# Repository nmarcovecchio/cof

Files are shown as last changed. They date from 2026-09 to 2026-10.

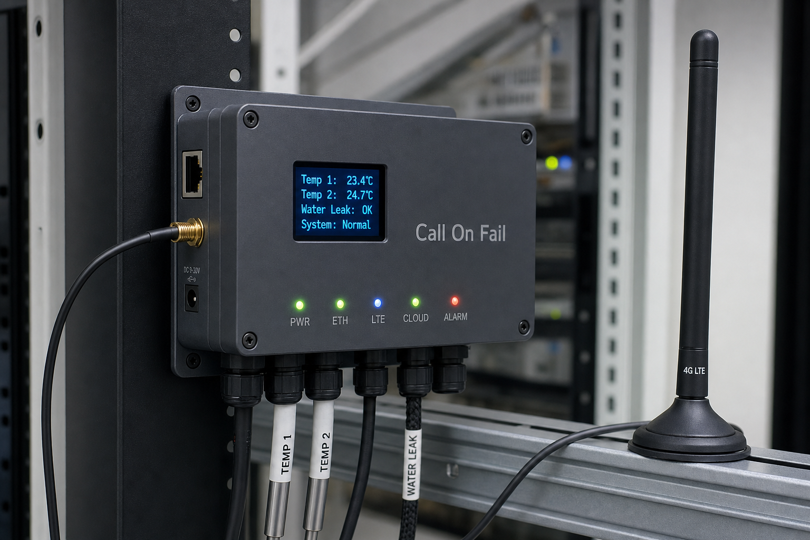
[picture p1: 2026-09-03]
web/assets/producto-nodo.png

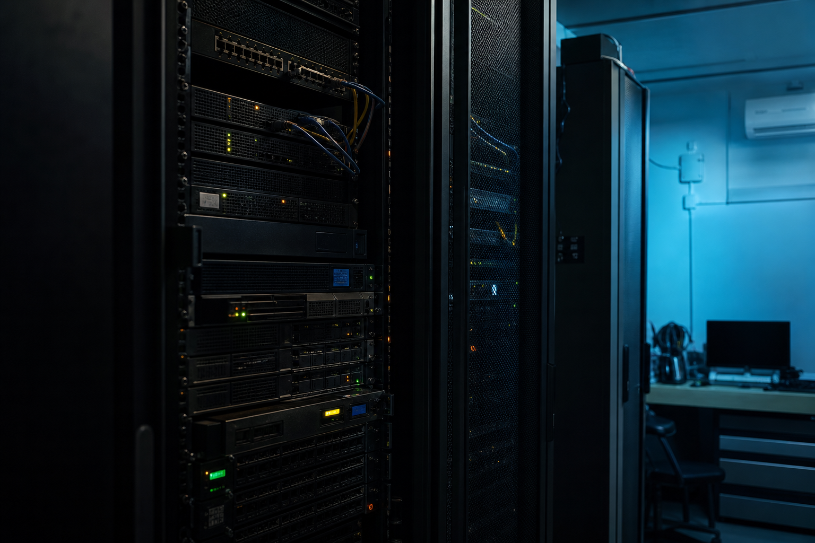
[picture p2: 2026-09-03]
web/assets/hero-sala.png

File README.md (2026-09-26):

# CallOnFail firmware

Primer firmware base para CallOnFail usando:

- WT32-ETH01 / WT32-S1 con Ethernet.
- WiFi opcional por credenciales cargadas desde Serial.
- OLED I2C 1.3" SH1106.
- SHT31 por I2C.
- DS18B20 por OneWire.
- PCF8574 por I2C para boton/DIP switch.
- Modem A7672 por UART TTL.
- OTA por Ethernet desde `ota/manifest.json`.
- Audio de prueba descargado por Ethernet y cargado al modem con `AT+CFTRANRX`.

## Backend MVP con Docker

El repo incluye una base deployable para VPS:

- Flask + Gunicorn.
- Jinja templates + Bootstrap.
- PostgreSQL.
- Redis.
- Mosquitto MQTT interno.
- Worker MQTT Python.
- Caddy como reverse proxy.
- Sitio público estático en `web/` (`www.callonfail.com.ar`).

La bitacora/configuracion persistente del VPS queda en:

```text
docs/ops/VPS_CONFIG.md
```

El contrato inicial para configuracion de dispositivos queda en:

```text
docs/DEVICE_CONFIG_V1.md
```

Llamada y SMS validados en lab (Claro / A7672 / TTS WAV) quedan en:

```text
docs/voice/VOICE_SMS.md
docs/voice/operators/claro-ar.md
```

La configuracion diferencia capacidades del modem, llamadas habilitadas por
cliente y estado real de audios. Un modem puede soportar audio, pero el cliente
puede tener `calling.enabled=false`.

### Deploy inicial en VPS

En el VPS, despues de instalar Docker:

```bash
sudo mkdir -p /opt/callonfail
sudo chown -R ubuntu:ubuntu /opt/callonfail
git clone https://github.com/nmarcovecchio/cof.git /opt/callonfail
cd /opt/callonfail
cp .env.example .env
nano .env
```

Si estas probando una rama antes de mergearla a `main`:

```bash
git clone -b NOMBRE_DE_RAMA https://github.com/nmarcovecchio/cof.git /opt/callonfail
```

Para una primera prueba sin dominio/TLS, dejar:

```text
APP_DOMAIN=:80
```

Cuando `app.callonfail.com.ar` (y `www`) apunten al VPS con DNS only en
Cloudflare, cambiar:

```text
APP_DOMAIN=app.callonfail.com.ar
ACME_EMAIL=tu-email
```

En produccion usá siempre el dominio, no la IP:

```text
https://www.callonfail.com.ar/
https://app.callonfail.com.ar/
```

Detalle de DNS/TLS/ACME: `docs/ops/VPS_CONFIG.md`.

Timezone de la UI:

```text
APP_TIMEZONE=America/Argentina/Buenos_Aires
```

Las fechas se guardan en UTC y se muestran en la UI con este timezone, hasta
segundos.

Credenciales admin iniciales:

```text
SECRET_KEY=generar-un-secreto-largo
ADMIN_USERNAME=admin
ADMIN_PASSWORD=poner-un-password-fuerte
SESSION_COOKIE_SECURE=false
```

`/health` queda publico para monitoreo. Dashboard, dispositivos, config y
comandos requieren login.

Los formularios usan token CSRF básico. Cuando el sitio esté con HTTPS, cambiar
`SESSION_COOKIE_SECURE=true`.

Levantar servicios:

```bash
docker compose up -d --build
```

Ver estado:

```bash
docker compose ps
docker compose logs -f web
docker compose logs -f mqtt-worker
```

Probar desde el VPS:

```bash
curl http://localhost/health
curl http://localhost/api/status
```

Probar desde navegador:

```text
http://IP_DEL_VPS/
```

Dashboard Bootstrap:

```text
http://IP_DEL_VPS/dashboard
http://IP_DEL_VPS/tenants
http://IP_DEL_VPS/devices
http://IP_DEL_VPS/devices/new
http://IP_DEL_VPS/devices/cof-test
http://IP_DEL_VPS/devices/cof-test/config
```

Flujo multi-cliente inicial:

1. Crear cliente en `/tenants/new` (email, grupo de Telegram, telefono).
2. Crear sitio en `/sites/new`.
3. Crear dispositivo en `/devices/new`.
4. Usar el mismo `Device ID` que usa el firmware en MQTT.
5. Entrar al dispositivo y publicar config o forzar OTA.
6. Configurar SMTP/bot una sola vez en el VPS: `docs/ops/NOTIFICATIONS.md`.

Los dispositivos reportan `hardware_profile`, capacidades y recursos
descubiertos. En `/devices/<device_id>` se muestran esos datos para poder mapear
sensores fisicos a sensores logicos.

Los datos de prueba se pueden borrar desde la web:

- `/devices`: archivar/restaurar dispositivos.
- `/tenants`: eliminar clientes completos o sitios individuales.

Archivar un dispositivo conserva su historial. Si el hardware sigue publicando
MQTT, el backend registra eventos `archived_device_message` y no guarda
telemetria normal ni lo reactiva automaticamente.

Para reutilizar un equipo con otro cliente:

1. Ir a `/devices?include_archived=1`.
2. Entrar a `Editar/reasignar`.
3. Elegir nuevo cliente/sitio.
4. Guardar y restaurar.

o, si ya configuraste DNS:

```text
https://app.callonfail.com.ar/
```

### Comandos Docker utiles

```bash
docker compose up -d
docker compose up -d --build
docker compose ps
docker compose logs -f
docker compose logs -f web
docker compose restart web
docker compose down
```

### MQTT MVP

Mosquitto escucha internamente en `1883` y Docker lo publica solo en
`127.0.0.1:1883`, para que no quede abierto a internet sin TLS.

Para probar desde el VPS:

```bash
docker compose exec mosquitto mosquitto_pub -h localhost -t devices/cof-test/telemetry -m '{"temperature":25.1}'
docker compose logs -f mqtt-worker
```

Antes de conectar equipos reales desde internet hay que agregar autenticacion y
TLS en `8883`.

### Prueba ESP32 -> VPS por MQTT

Para una prueba corta de laboratorio, se puede exponer MQTT sin TLS en `1883`.
No dejar esto asi para produccion.

En `.env` del VPS:

```text
MQTT_BIND_ADDRESS=0.0.0.0
```

Recrear servicios:

```bash
docker compose up -d --build
```

Abrir temporalmente el puerto en UFW:

```bash
sudo ufw allow 1883/tcp
```

Tambien abrir `1883/tcp` en el firewall de Lightsail/AWS.

En el ESP32, desde PlatformIO Monitor:

```text
mqtt mqtt.callonfail.com.ar 1883 cof-test
```

O usando la IP publica:

```text
mqtt IP_DEL_VPS 1883 cof-test
```

Publicar telemetria manual:

```text
pub
```

Ver logs en el VPS:

```bash
docker compose logs -f mqtt-worker
```

Luego refrescar:

```text
http://IP_DEL_VPS/dashboard
```

Para probar configuracion web -> ESP32 -> ACK:

```text
http://IP_DEL_VPS/devices/cof-test
```

Entrar a `Editar/publicar configuracion`, guardar el JSON y esperar que el
dispositivo reporte la misma version en `Config deseada/reportada`.

Para forzar chequeo OTA desde la web:

```text
http://IP_DEL_VPS/devices/cof-test
```

Click en `Probar SMS` o `Probar llamada` (firmware 0.2.28+) para mandar un SMS
o marcar un numero. El texto de la casilla es el SMS y el audio de la llamada
(Piper `es_AR-daniela` → AMR-NB 8 kHz). Detalle en `docs/voice/VOICE_SMS.md`. El backend
publica `test_sms` o `test_call` en `devices/<id>/command`. Si el ACK dice
`unsupported`, primero `OTA`. Sin VoLTE la llamada prepara CS (RF bounce)
antes del primer `ATD`.

Click en `Forzar chequeo OTA`. El backend publica:

```text
devices/cof-test/command
```

con:

```json
{"command":"ota_check"}
```

El ESP32 responde en:

```text
devices/cof-test/ack
```

El firmware consulta el manifest automaticamente para datos auxiliares, pero la
actualizacion de firmware se ejecuta solo por comando explicito:

- boton web `Forzar chequeo OTA`,
- comando Serial `o`,
- pulsacion larga del boton fisico.

Si se borra un dispositivo mientras el ESP32 sigue conectado, puede recrearse
primero por telemetria y aparecer sin hardware profile hasta que llegue un
`status`. El firmware publica status al conectar MQTT y tambien se puede pedir
desde `/devices/<device_id>` con `Solicitar estado`.

Por defecto el worker no auto-crea dispositivos desconocidos:

```text
MQTT_AUTO_PROVISION=false
```

Crear/provisionar dispositivos desde la web evita asignaciones accidentales a
clientes equivocados.

Cuando termine la prueba, cerrar `1883`:

```bash
sudo ufw delete allow 1883/tcp
```

## IDE recomendado

Usa **Visual Studio Code + PlatformIO**.

1. Instalar VS Code.
2. Instalar la extension "PlatformIO IDE".
3. Abrir la carpeta `firmware/` del repo en VS Code (PlatformIO toma `platformio.ini` de ahí).
4. Editar `firmware/include/cof_config.h`.
5. Conectar el programador USB-Serial.
6. En PlatformIO, ejecutar:
   - `Build`
   - `Upload`
   - `Monitor`

Alternativa por consola (desde `firmware/`):

```bash
cd firmware
pio run
pio run -t upload
pio device monitor -b 115200
```

## Comandos por Serial

Abrir PlatformIO Monitor a `115200`. El firmware acepta comandos para probar
hardware sin recompilar:

```text
h      ayuda
s      imprimir estado general
i      escanear bus I2C
t      leer sensores ahora
m      reinicializar modem
o      forzar chequeo manifest/OTA
a      forzar chequeo manifest/audio
c      hacer llamada de prueba si llamadas estan habilitadas
r      reiniciar ESP32
wifi SSID PASSWORD  guardar WiFi y conectar
wifi-clear          borrar WiFi guardado
wifi-status         ver estado WiFi
mqtt HOST PORT DEVICE_ID [USER PASSWORD]
mqtt-clear          borrar MQTT guardado
mqtt-status         ver estado MQTT
pub                 publicar telemetria ahora
AT...  enviar comando AT crudo al modem
```

Ejemplos:

```text
i
s
AT
AT+CPIN?
AT+CSQ
AT+CCMXPLAY=?
AT+CFTRANRX=?
```

Para cargar WiFi desde Serial:

```text
wifi MiRed MiPassword
```

El firmware guarda SSID/password en flash y vuelve a conectarse despues de un
reset. Para borrar:

```text
wifi-clear
```

Nota: por ahora el comando simple no soporta espacios en el SSID o password.
Desde la ficha web del dispositivo, con Ethernet ya conectado, se puede guardar
u olvidar WiFi; ahi el password puede tener espacios y no queda en la config
retenida.

Para configurar MQTT desde Serial:

```text
mqtt IP_DEL_VPS 1883 cof-test
mqtt-status
pub
```

La build de laboratorio trae por defecto:

```text
MQTT host: mqtt.callonfail.com.ar
MQTT port: 1883
Device ID: cof-test
```

Si no hay otra configuracion MQTT guardada en el ESP32, intenta conectar ahi
automaticamente.

El firmware tambien habilita el watchdog interno del ESP32 con timeout amplio
para pruebas. Si el programa se cuelga, el ESP32 deberia reiniciarse solo.

## Configuracion antes de llamar

Por seguridad, las llamadas estan deshabilitadas por defecto.

En `firmware/include/cof_config.h`:

```cpp
#define COF_ENABLE_CALLS 0
#define COF_PHONE_NUMBER "+549XXXXXXXXXX"
```

Para probar llamadas:

```cpp
#define COF_ENABLE_CALLS 1
#define COF_PHONE_NUMBER "+549TU_NUMERO"
```

Tambien se puede publicar el numero en `ota/manifest.json`, pero para la
primera prueba conviene dejarlo fijo en el firmware.

## Pines WT32

La placa v1 (4 IN, 2 OUT, leak, RESET del A7672, WDT con corte de 5 V) esta
en `docs/hardware/HARDWARE_V1.md`. Abajo queda el cableado de **lab** actual.

### Alimentacion

Usar una sola entrada de alimentacion en el WT32:

```text
Fuente PC 5V  -> WT32 5V
Fuente PC GND -> WT32 GND
```

No alimentar el WT32 por 5V y 3V3 al mismo tiempo.

### Programacion inicial

Usar el header de programacion/debug:

```text
USB-Serial TX  -> WT32 RXD0
USB-Serial RX  -> WT32 TXD0
USB-Serial GND -> WT32 GND
WT32 IO0       -> GND solo para subir firmware
```

Secuencia:

1. Poner `IO0` a GND.
2. Reset/EN.
3. Subir firmware.
4. Sacar `IO0` de GND.
5. Reset/EN.

El USB-Serial debe usar logica de 3.3V.

### I2C

```text
WT32 IO32 / CFG    -> SDA
WT32 IO33 / 485_EN -> SCL
```

Conectar al mismo bus:

```text
OLED SH1106 VCC -> 3V3
OLED SH1106 GND -> GND
OLED SH1106 SDA -> IO32
OLED SH1106 SCL -> IO33

SHT31 VCC -> 3V3
SHT31 GND -> GND
SHT31 SDA -> IO32
SHT31 SCL -> IO33

PCF8574 VCC -> 3V3
PCF8574 GND -> GND
PCF8574 SDA -> IO32
PCF8574 SCL -> IO33
```

Boton de prueba:

```text
PCF8574 P0 -> boton -> GND
```

Pulsacion corta: llamada de prueba.

Pulsacion larga, mas de 3 segundos: forzar chequeo OTA/manifest.

### DS18B20

```text
DS18B20 VDD  -> 3V3
DS18B20 GND  -> GND
DS18B20 DATA -> WT32 IO14
4.7k entre DATA y 3V3
```

### ZMPT101B

Para mas adelante:

```text
ZMPT101B OUT -> WT32 IO36
```

No conectar 220V hasta validar el resto del sistema.

### A7672

Alimentar el modem con 5V de la fuente de PC:

```text
Fuente PC 5V  -> A7672 VCC
Fuente PC GND -> A7672 GND
WT32 GND      -> A7672 GND comun
```

UART:

```text
A7672 TXD -> WT32 RXD / GPIO5
A7672 RXD -> WT32 TXD / GPIO17
```

Velocidad inicial:

```text
115200
```

El firmware prueba:

```text
AT
ATE0
ATI
AT+CPIN?
AT+CSQ
AT+CCMXPLAY=?
AT+CFTRANRX=?
```

## OTA por Ethernet o WiFi

El ESP32 consulta el manifest en el mismo origen que el binario:

```text
https://app.callonfail.com.ar/ota/manifest.json
```

(OTA por LTE esta bloqueado a proposito; sin LAN el OLED muestra `OTA needs LAN`.)

Para publicar una nueva version:

1. Actualizar `COF_FIRMWARE_VERSION` en `firmware/include/cof_config.h`.
2. Compilar:

   ```bash
   pio run
   ```

3. Copiar el binario:

   ```bash
   cp firmware/.pio/build/wt32-eth01/firmware.bin ota/firmware.bin
   ```

4. Actualizar `ota/manifest.json` con la nueva version.
5. Commit + push.

Los equipos instalados descargaran el firmware por Ethernet o WiFi cuando vean
una version mayor en el manifest. Ethernet queda como red principal; WiFi sirve
como fallback y para pruebas.

## Audio de llamada

Hay **dos familias** de audio en el modem y no se pisan:

| Archivo | Origen | Cuando suena |
| --- | --- | --- |
| `C:/a_<sha16>.amr` | El servidor sintetiza el `call_text` de cada regla **al guardar la config**, y el equipo lo baja con `syncRuleAudio()`. | Llamada de esa regla. Es **autocontenido** y **no necesita red**. |
| `C:/cof_fallback.wav` | `ota/audio/cof_fallback.wav`, anunciado por el manifest. | Ultimo recurso, si la regla no tiene audio local utilizable **y** la descarga del TTS falla. |

La llamada usa, en orden: (1) el audio pregrabado de la regla; (2) el TTS bajado
del servidor, si hay ruta y el asset local todavia no bajo; (3) recien ahi
`C:/cof_fallback.wav`.

Todo el texto de la llamada se resuelve **al guardar**, asi que el audio de la
regla es siempre completo y la llamada no baja nada en el momento del disparo. El
unico caso que necesita red es la descarga inicial del asset, que usa `HTTPClient`
+ `WiFiClientSecure` y en un sitio solo-LTE no tiene ruta (el MQTT viaja por el
socket `AT+CIPOPEN`, que no es lwIP). El respaldo no puede decir el sitio ni el
valor: el ESP32 no tiene sintesis.

`{valor}` esta **retirado**: obligaba a sintetizar y bajar audio durante la alarma
y su respaldo sin internet decia "un valor fuera de rango", que suele ser falso.
El numero, si importa, se escribe en el texto y se graba; el valor exacto de cada
disparo va por SMS y email. Ver `docs/ops/NOTIFICATIONS.md`.

El equipo **solo borra archivos que empiezan con `a_`**, asi que ni el respaldo ni
nada desconocido puede ser barrido por accidente.

El respaldo se rehace a mano (no hay pipeline):

```text
ota/audio/cof_fallback.wav
```

Formato:

```text
WAV PCM, 8000 Hz, mono, 16-bit
```

El firmware lo sube al modem como:

```text
AT+CFTRANRX="C:/cof_fallback.wav",<bytes>
```

Y durante la llamada lo reproduce hacia el remoto:

```text
AT+CCMXPLAY="C:/cof_fallback.wav",1,0
```

## Pantalla OLED

La pantalla muestra:

- Version de firmware.
- IP Ethernet.
- Temperatura/humedad SHT31.
- Temperatura DS18B20.
- ADC crudo del ZMPT101B.
- Estado modem/LTE.
- Estado actual: OTA, llamada, audio, errores.

## Si el OLED queda apagado

Checklist rapido:

1. Despues de subir firmware, sacar `IO0` de GND y resetear. Si `IO0`
   queda a GND, el WT32 queda en modo programacion y no corre el programa.
2. Confirmar que el OLED este conectado a los pines configurados:

   ```text
   OLED SDA -> WT32 IO32 / CFG
   OLED SCL -> WT32 IO33 / 485_EN
   OLED VCC -> WT32 3V3
   OLED GND -> WT32 GND
   ```

3. No usar GPIO21/GPIO22: en este firmware el bus I2C esta en IO32/IO33.
4. Probar invertir SDA/SCL si hay duda de serigrafia.
5. Abrir Monitor a 115200 y buscar:

   ```text
   [i2c] scan SDA=32 SCL=33
   [i2c] found device at 0x3C
   ```

   o:

   ```text
   [i2c] no devices found
   ```

6. Si no aparece ningun dispositivo I2C, revisar alimentacion, GND comun,
   SDA/SCL y soldaduras del pin header.

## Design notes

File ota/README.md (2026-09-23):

# CallOnFail current version

The ESP32 reads `manifest.json` from this directory over Ethernet.

Expected production files:

- `manifest.json`: firmware, audio and runtime configuration metadata.
- `firmware.bin`: PlatformIO build output copied from `.pio/build/wt32-eth01/firmware.bin`.
- `audio/cof_fallback.wav`: 8 kHz, 16-bit, mono WAV. Uploaded to the A7672 modem
  as `C:/cof_fallback.wav` and played by an **alarm** call as a last resort, when
  the site can neither use the rule's pre-recorded audio nor download the server
  TTS (site with no Ethernet/WiFi). Regenerated by hand: bump `audio.version` and
  the `sha256` when it changes.
- `audio/cof_test.wav`: the historical lab test audio. No longer what an alarm
  call plays (`COF_MODEM_AUDIO_PATH` now points at `cof_fallback.wav`); kept as
  the canonical bench asset.

**Per-rule call audio is NOT here.** Rules with a `call_text` get their audio
pre-recorded by the backend at config-save time and served from
`CALL_AUDIO_DIR` at `/audio/asset/<sha256>.amr`; the device downloads it on
config apply into `C:/a_<sha16>.amr`. Nothing to publish in this directory.

`manifest.json` advertises one audio asset at a time, so the file above is the
current one. `release-fw.py` only rewrites `firmware.*`; it leaves the `audio`
block alone.

Keep the firmware version in `manifest.json` higher than the version compiled in
`include/cof_config.h` when you want deployed devices to update OTA.

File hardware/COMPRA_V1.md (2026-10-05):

# Listado de compra — CallOnFail v1.5.3

**Trabado con el esquemático rev 1.5.3.** No cambiar partes de alimentación sin
actualizar `docs/hardware/HARDWARE_V1.md` y `hardware/kicad/gen_sch.py` juntos.

Alineado a `cof-v1-bom.csv`. Un prototipo. En AE se piden packs: el proto usa
la columna **Usa**. Todo lo que se suelda a pata es THT (no SOT-23 suelto).
Los módulos (WT32, A7672, XY-SJVA, XL6019, LM66200, PCF8575, SHT31, OLED,
FT232, RS485, PC817, relé 2CH, water detector) ya vienen armados.

Gel **6 V 7 Ah** (NP7-6): comprar acá, no China. Fuente **5 V 5 A**: ya está.

## Módulos

| Comprar | Pedir | Usa | Para |
| --- | ----- | --- | ---- |
| **XY-SJVA** o XY-SJVA-4 CC/CV 3 A 35 W, **dos potes** | 1 | 1 | Carga gel 6,85 V / 0,6 A desde `5V_PSU`. No ZK-S4 |
| Buck-boost auto **XL6019** (no XL6009 de un pote, no ZK-4KX) | 1 | 1 | Backup gel → **5,1 V** |
| **LM66200** dual ideal-diode (módulo pines 2,54 / tipo Adafruit) | 1–2 | **1** | OR PSU + XL6019 → `5V_BUS` |
| **PCF8575** módulo I2C (16 bit) | 1 | 1 | Campo, LEDs, buzzer, SYS_KILL, ETH_RST. VDD **3V3** |
| **Módulo 2 relés optoacoplado** 5 V | 1 | 1 | OUT1 / OUT2. Activo LOW típico |
| **EstarDyn PC817 2CH** (3,6–30 V) | 1 | 1 | Aísla campo IN1 + IN2 (no agua) |
| **Mini Water Detector Relay** 5/12/24 V | 1 | 1 | Fuga → contacto seco a PCF P00. Alimentar a **5 V** |
| **Buzzer activo 5 V** (2 patas) | 5–10 | **1** | +5V_SYS; − vía Q_BZ (P03→NPN) |
| **TTL↔RS485 auto** (BS, 3V3/5V) | 1 | 1 | Modbus HW. IO12 TX / IO39 RX |
| **FT232** (FTDI232 / FT232RL) breakout | 1 | 1 | Prog UART0. No 5 V USB al WT32 |
| **TPL5010** (módulo o DIP/SOIC breakout) | 1–2 | **1** | WDT ~10 min @ `5V_BUS`. DONE vía NPN |
| **74HCT123** DIP-16 (o HCT123 equivalente) | 2–5 | **1** | One-shot ~2 s → Q1 nuclear |
| SHT31 I2C | 1 | 1 | Humedad (si no está el del lab) |
| OLED 1.3" SH1106 | 1 | 1 | Si no está el del lab |
| DS18B20 waterproof | 4 | 4 | Temps en cadena |
| ZMPT101B | 1 | 1 | 220 V después; no conectar 220 hasta validar |

WT32-ETH01 y A7672SA-FASE: los del lab.

## Semiconductores

| Comprar | Pedir | Usa | Para |
| --- | ----- | --- | ---- |
| **NDP6020P** TO-220 (P-FET logic). Alt AE: **IRF5305** | 5–10 | **1** | Q1 `5V_SYS` (+módem). **No** IRF4905 |
| **2N3904** NPN TO-92 | 10 | **3** | Q_EN (`BB_EN`) + Q_DONE (TPL DONE) + Q_BZ (buzzer) |
| **1N4148** | pack 50 | **1+** | ETH_RST (PCF P11) → PHY nRST (pad R43) |

## Pasivos y mecánica

| Comprar | Pedir | Usa | Para |
| --- | ----- | --- | ---- |
| Electrolítico **2200 µF / 16 V** | 10 | 1 | `5V_BUS` C1 |
| Electrolítico **1000 µF / 16 V** | 10 | 1 | A7672 C2 (placa B) |
| Electrolítico **47 µF / 16 V** | 10 | 1 | 74HCT123 timing C17 |
| Electrolítico **10 µF** | 10 | 1 | `5V_SYS` C15 |
| Cerámico / film **2,2 µF** | pack | 1 | `/CLR` blank C18 |
| Cerámico **100 nF** paso 2,54 mm | pack | ver BOM | Desacoples + ADC + ZMPT |
| **REXT** TPL5010 **57,6 kΩ** 1% | 5 | 1 | Intervalo ~10 min (tabla TI) |
| **100 kΩ** 1% | pack | 2+ | HCT123 REXT + TRIG_N/`/CLR` PU |
| 10 kΩ, 15 kΩ, 47 kΩ, 4,7 kΩ, **1 kΩ**, 330 Ω, **1 MΩ** | packs | ver BOM | Gates, I2C, 1-Wire, LEDs, ADC gel, ZMPT, DONE PU |
| Fusible 5×20 **5 A** + porta | 5+1 | 1 | Gel+ |
| LED 5 mm verde / rojo / azul (+ LTE) | 20 c/u | **4** | PWR / NET / ALARMA / **LTE** |
| Pulsador panel NA hundido + táctiles 6×6 | 1+pack | **4** | RESET gabinete + servicio PCF + **BOOT** + **EN** |
| Bornera 5,08 mm | 1 set | — | IN/OUT / RS485 A-B |
| **Bornera 5,08** 4 polos ×2 | 1 set | 2 | J7 / J8 enlace 5 V A↔B. No cinta IDC |
| **Molex KK 2,54** 8p + housing ×2 (o bornera 8) | 1 set | 2 | J9 / J10 señales (IO15, SYS_KILL, BTN) |

## No comprar (para este diseño)

- 74HCT14 / 74HCT125
- CD4541BE (WDT = TPL5010)
- TLC555 / NE555 / 7555
- Segundo NDP6020P / Q3 / FET de módem (módem = `5V_SYS`)
- ULN2003 + relés sueltos / 1N4007 flyback (módulo opto)
- PCF8574 (usar **8575**)
- SB560 / Schottky de potencia (OR = LM66200)
- 2N7000
- ZK-S4, XL4015, XL6009 de un pote, ZK-4KX
- IRF4905 / IRF9540
- AO3401 / SOT-23 suelto
- TXS0102 / shifters I2C
- Cinta IDC-10

Detalle por referencia: `hardware/kicad/cof-v1-bom.csv`.
Especificación: `docs/hardware/HARDWARE_V1.md`.

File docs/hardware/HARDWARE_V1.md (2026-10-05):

# Hardware v1 — CallOnFail

**Hardware trabado en rev 1.5** (2026-10-04). No rediseñar alimentación / OR /
MOSFET / enlace A↔B salvo bug real. Fuente de verdad: `gen_sch.py` + este doc +
`hardware/COMPRA_V1.md`. El PDF se genera local con `kicad-cli sch export pdf`;
no va en git.

**Software / lab:** Telegram y email ya andan. Falta **probar el ciclo de alarma**.
Firmware de I/O, RESET, WDT y LEDs de gabinete todavía no (driver **PCF8575**).

Placa: WT32-ETH01 + A7672SA-FASE. Perfil `cof-wt32-a7672-v1`.

Esquemático KiCad 10: `hardware/kicad/cof-v1.kicad_pro`
(hoja Alimentacion + hoja ESP32/modem/sensores).
BOM: `hardware/kicad/cof-v1-bom.csv`. Compra: `hardware/COMPRA_V1.md`. Rev **1.5.3**
(THT: **1×** NDP6020P + **2× 2N3904**; OR = **LM66200**; WDT = **TPL5010**@`5V_BUS`
+ NPN DONE; nuclear = **74HCT123** ~2 s → Q1; módem en `5V_SYS`; P12 = `SYS_KILL`↓;
EN = lab only; I/O = **PCF8575** @ 3V3; campo = PC817 + relé opto 2CH + water;
prog = **FT232** + BOOT/EN; RS485 auto IO12/IO39).
Proto en dos placas unidas por bornera / Molex (no cinta IDC); después, una sola placa.

**Lab** = ya cableado y en firmware. **v1** = placa a armar según este doc.

No usar GPIO21/22 para I2C. No alimentar el WT32 por 5V y 3V3 a la vez.

---

## Qué lleva el producto

| Función | Cómo |
| --- | --- |
| Temp ×4 (máx. de venta) | DS18B20 en un bus, ~15–20 m, cadena |
| Humedad + temp ambiente | SHT31 en la placa |
| 220 V | ZMPT101B (no conectar 220 hasta validar) |
| Fuga de agua | Water Detector contacto seco → PCF **P00** (sin PC817) |
| Entradas de campo ×2 | IN1/IN2 vía PC817 2CH → PCF **P01** / **P13** |
| 2 salidas de campo | Módulo 2 relés opto (PCF P04/P05) |
| Buzzer de gabinete | PCF P03 → NPN → buzzer 5 V activo |
| LEDs de **gabinete** | PWR, NET, ALARMA, **LTE** (frente) |
| Botón **RESET** de gabinete | Hundido; dispara one-shot ~2 s (corta `5V_SYS` + módem) |
| RS485 | Módulo TTL↔RS485 auto (IO12 TX / IO39 RX) |
| OLED | Servicio / lab, adentro, no en el frente |
| Backup 4 h | Gel 6 V 7 Ah (VRLA). LiFePO4 queda para después |

---

## 1. Alimentación (v1)

Riel de equipo: **5 V**. La fuente de 220 que ya está comprada es **5 V 5 A**.
Eso alimenta WT32 + A7672 + sensores. Un solo convertidor de backup
(**buck-boost**, no el XL4015). Los **3V3 salen del WT32**; no hay otro
regulador de 3V3.

Gel **6 V 7 Ah** (sellada, tipo NP7-6). Usar ~la mitad. Flote **6,8–6,9 V**,
no 7,3 V de “carga rápida”. La gel **no** va en paralelo con la fuente de
5 V. Se carga desde `5V_PSU` con **XY-SJVA** (buck-boost CC/CV 3 A / 35 W;
a 5 V de entrada ~15 W). Seteo **6,85 V / 0,6 A**, ~C/10. No ZK-S4 (80 W).

4 Ah a 6 V queda justo para 4 h. 7 Ah deja margen de llamada y Peukert.
No dos 6 V en serie: eso es volver a 12 V.

GND común. El supervisor (WDT + one-shot del RESET) vive en **`5V_BUS`**,
antes de los MOSFET de corte. Así funciona en el banco sin gel, y sigue
vivo cuando se corta `5V_SYS`.

```text
220 VAC
  └── Fuente 5V 5A
          ├── 5V_PSU
          │     ├── XY-SJVA CC/CV (6,85 V / 0,6 A)  [3 A / 35 W]
          │     │         └── Gel 6 V 7 Ah + fusible 3–5 A
          │     │               └── buck-boost (ajuste 5,1 V) ──┐
          │     │                   (EN=0 si hay PSU)            │
          │     └────────────────────────────────────────────── LM66200 ── 5V_BUS
          │                                                       (VIN1=PSU, VIN2=backup)
5V_BUS  (+2200 µF + 100 nF)
  ├── TPL5010 WDT (~10 min) + 74HCT123 one-shot (~2 s) → Q1
  │
  └── NDP6020P (Q1)  →  5V_SYS
        WT32 pin 5V
        A7672 VCC (+1000 µF + 100 nF en placa B)
        LED PWR
        3V3 del WT32 → OLED, SHT31, PCF, DS18B20
```

Hay 220: la fuente de 5 V lleva todo. El XY-SJVA deja la gel en flote a
6,85 V / 0,6 A. El buck-boost de backup está apagado (EN a GND vía **2N3904**).

Se corta la 220: se muere la fuente y el cargador. El EN del buck-boost se
suelta (pull-up a Gel+), el LM66200 pasa a VIN2, la gel a 5,1 V en el bus.
El capellón en `5V_BUS` tapa el hueco. El ZMPT avisa “se cortó la luz”.
Ethernet off, LTE si hace falta, ~4 h.

El XY-SJVA **toma 5V_PSU**, no `5V_BUS` (si no, en backup la gel se carga a
sí misma). **No unir** las nets con un cable. OR: módulo **LM66200** (dual
ideal-diode, ~2,5 A, pines 2,54). VIN1 = `5V_PSU`, VIN2 = XL6019, VOUT =
`5V_BUS`. EN del módulo a GND (siempre habilitado). El XY-SJVA no sirve de
backup (3 A / ~15 W a 5 V). LED verde “lleno” es ~0,1×I; en gel se ignora
(flote a 6,85 V).

IN− y OUT−: con el tester, módulo apagado. Si están abiertos, **no** los
unes ni los tires los dos al GND del WT32 (el shunt de CC va en el −).
Gel− solo a OUT−. Si ya vienen cortocircuitados en la placa, GND común
está bien.

### Cableado de banco

```text
Fuente 5V+ ──── 5V_PSU ──── LM66200 VIN1 ──┐
Fuente 5V− ──── GND                        ├── VOUT ── 5V_BUS
                 │                         │
                 ├── XY-SJVA IN+    XY-SJVA IN− ── GND fuente (no puentear OUT−)
                 │         │
                 │         OUT+ ── fusible 3–5 A ── Gel+
                 │         OUT− ────────────────── Gel−  (ver nota IN−/OUT−)
                 │
                 │   Gel+ ── buck-boost VIN+
                 │   GND  ── VIN−
                 │           VOUT+ ── LM66200 VIN2 ─┘
                 │           VOUT− ── GND
                 │           EN ── R2 10k a Gel+ ; Q_EN 2N3904 hunde EN si hay PSU
                 │
                 └── 10k ── PSU_DET ── 100k a GND ── base Q_EN (vía 10k)

5V_BUS ── 2200 µF + 100 nF a GND
       ├── TPL5010 + 74HCT123 → gate Q1 (~2 s SYS off)
       └── NDP6020P (Q1) ── 5V_SYS → WT32 5V, A7672 VCC, LED PWR, 3V3
```

XY-SJVA: **CV 6,85 V / CC 0,6 A** (vacío, después gel). Buck-boost de
backup: **5,1 V**. EN: pull-up a Gel+; con PSU el **2N3904** lo baja a ~0.

### Cortes (WDT / RESET / nuclear)

IRF4905 / IRF9540 no cierran bien a 5 V (quieren Vgs ≈ −10 V). Usar
**P-MOSFET logic NDP6020P** (TO-220): source = `5V_BUS`, drain = carga,
gate a GND = ON, gate a `5V_BUS` = OFF. Pinout de frente G-D-S. Arranca
en el banco sin gel. Si no hay NDP6020P, **IRF5305** TO-220. **No** IRF4905.

| Qué | Quién lo corta | Default |
| --- | --- | --- |
| `5V_SYS` | 74HCT123 (~2 s): TPL timeout / P12 `SYS_KILL` / BTN RESET  | ON |
| Módem | Mismo Q1 (`5V_SYS`); soft = AT / RESET / PWRKEY | ON |
| Gel | Nadie | Siempre conectada |

Un pulso a `EN` del ESP32 **no** resetea el PHY LAN8720. Por eso el nuclear
corta `5V_SYS` (ESP + PHY + módem). `EN` queda solo para lab (SW_EN).

Durante una llamada hay que seguir pateando el WDT. Timeout **~10 min**
(REXT 57,6 kΩ tabla TI; > llamada + TTS + margen).

### Por qué 6 V y por qué buck-boost

6 V queda más cerca del riel de 5 V: carga 5 V → 6,85 V (menos salto que
13,7 V), bateria más chata, mismo tipo NP7-6 de alarma / luces de
emergencia. No 12 V.

La gel 6 V llena está ~6,8 V; vacía (corte) ~5,5 V. Eso **cruza** los 5,1 V
del backup. Un buck (XL4015) necesita ~1,5 V de cabeza: solo sirve con la
bateria llena. Un boost solo se queda corto cuando está llena. El puente
es un **buck-boost automático** a 5,1 V (módulo 5 A tipo **XL6019**, no
el XY-SJVA, no ZK-4KX). El **XL6009 de un pote es solo boost**: con la gel
llena (~6,8 V) no puede entregar 5,1 V. Si no trae EN, un NDP6020P corta el
+ de la gel al convertidor mientras haya `5V_PSU`.

---

## 2. WT32 — lab (no bornes de cliente)

Ethernet interno: IO0 CLK, IO16 power, IO18 MDIO, IO23 MDC.

```text
5V_SYS  →  WT32 5V
GND     →  WT32 GND
```

Programación (3.3 V):

```text
USB-Serial TX  →  RXD0
USB-Serial RX  →  TXD0
USB-Serial GND →  GND
IO0 a GND solo para flashear; después soltar y reset
```

---

## 3. I2C — IO32 SDA, IO33 SCL (lab + v1)

Todo a 3V3 del WT32 (riel `5V_SYS`).

| Equipo | Dir. | Rol |
| --- | --- | --- |
| OLED SH1106 | 0x3C | Lab / adentro del gabinete |
| SHT31 | 0x44 | Humedad + temp ambiente |
| PCF8575 | 0x20–0x27 | 16 I/O: campo, buzzer, LEDs, SYS_KILL, ETH_RST. **VDD=3V3** |

---

## 4. DS18B20 ×4 — IO14 (lab)

```text
3V3  →  VDD (las 4)
GND  →  GND
IO14 →  DATA (un bus, en cadena, no estrella)
4.7k entre DATA y 3V3, en la placa junto al WT32
```

No parásito. Cable tipo UTP, par DATA+GND.

---

## 5. ZMPT101B — IO36 (lab, 220 después)

```text
ZMPT VCC  →  5V_SYS
ZMPT OUT  →  10 kΩ  → IO36
                  ├── 15 kΩ a GND
                  └── 100 nF a GND
ZMPT GND  →  GND
```

No conectar 220 V hasta validar el divisor en lab.

---

## 6. Bornes de campo — PCF8575 (v1.5)

VDD del PCF = **3V3** (no 5 V: I2C al ESP32). Firmware de gabinete aún no.

**Módulo 2 relés opto:** `VCC` (lógica/opto) a **3V3**, `JD-VCC` (bobinas) a
**5V_SYS**. Jumper **VCC–JD-VCC OFF** (aislado).

| PCF | I/O | Qué |
| --- | --- | --- |
| P00 | IN | Fuga agua: Water Detector NO→P00, COM→GND (sin opto) |
| P01 | IN | Campo IN1 vía PC817 ch1 |
| P02 | IN | Botón **servicio** (lab/mantenimiento; no RESET, no silencia) |
| P03 | OUT | Buzzer: →1k→ Q_BZ 2N3904 (coll. a buzzer−; + = 5V_SYS) |
| P04 | OUT | Relé módulo IN1 (activo LOW típico) |
| P05 | OUT | Relé módulo IN2 |
| P06 | OUT | LED NET (ánodo **3V3**, cátodo P06) |
| P07 | OUT | LED ALARMA (ánodo **3V3**, cátodo P07) |
| P10 | OUT | LED LTE (ánodo **3V3**, cátodo P10) |
| P11 | OUT | ETH_RST → 1N4148 → LAN8720 nRST (soldado en módulo) |
| P12 | OUT | SYS_KILL → TRIG_N (pulso **bajo** = nuclear ~2 s) |
| P13 | IN | Campo IN2 vía PC817 ch2 (10k PU) |
| P14–P17 | — | Spare NC |

Campo IN1/IN2 vía **PC817** (los 2 canales). Agua **no** usa opto (contacto
seco a P00). Pull-ups 10 k a 3V3 en lado MCU.

---

## 7. Frente del gabinete — LEDs + RESET (v1)

Tres LEDs y un botón, cable a un conector de la placa. No usar OUT1/OUT2 ni IN1–2.

| Frente | Color / tipo | Qué hace | Origen |
| --- | --- | --- | --- |
| PWR | LED verde | Hay `5V_SYS` | 5V_SYS + R → GND (sin PCF) |
| NET | LED verde/azul | Ethernet o MQTT OK | **3V3** + R → PCF **P06** |
| ALARMA | LED rojo | Alarma abierta | **3V3** + R → PCF **P07** |
| LTE | LED (ámbar/azul) | Enlace LTE / MQTT LTE | **3V3** + R → PCF **P10** |
| RESET  | Botón NA, **hundido** | `5V_SYS` off mientras se mantiene | BTN → gate Q1 |

Hundido. **No silencia alarmas.**

Conector de panel (**6 pines**):

```text
1  GND
2  LED_PWR      ánodo (5V_SYS→330Ω en placa; cátodo del LED de frente a GND)
3  LED_NET      P06 (cátodo; ánodo en placa a 3V3→330Ω)
4  LED_ALARMA   P07 (cátodo; ánodo en placa a 3V3→330Ω)
5  LED_LTE      P10 (cátodo; ánodo en placa a 3V3→330Ω)
6  BTN_RESET    → TRIG_N (NA a GND; nuclear ~2 s)
```

**Buzzer** adentro: `5V_SYS` → buzzer+ ; buzzer− → collector **Q_BZ** 2N3904;
P03 → 1 kΩ → base; emitter GND. PCF nunca ve 5 V. Servicio: táctil → **PCF P02**.

Prog lab: **FT232** + **SW_BOOT** (IO0) + **SW_EN** (EN). No 5 V USB al WT32.

PHY soft-reset: PCF P11 → 1N4148 → nRST LAN8720 (hilo a pad R43 del WT32).

---

## 8. A7672

UART lab, 115200:

```text
A7672 TXD  →  WT32 IO5
A7672 RXD  →  WT32 IO17
GND comun
5V_SYS     →  A7672 VCC
```

Control v1 (open-collector a GND; el módulo ya tiene pull-up). **1 k en
serie** en RESET y PWRKEY. No >100 nF en estos pines. No bajar RESET y PWRKEY a la vez.

| A7672  | Pin | WT32 |
| --- | --- | --- |
| RESET  | 16  | IO4, pulso bajo ~2,5 s |
| PWRKEY | 1 | IO2, encendido / apagado |

`USIM_RST` es la SIM, no el módem.

Si RESET soft no alcanza: `SYS_KILL` (nuclear) o botón gabinete; luego PWRKEY.

---

## 9. WDT externo + nuclear RESET (v1.5.3)

**TPL5010** a **`5V_BUS`** (siempre vivo con fuente/gel). Intervalo **~10 min**
vía REXT **57,6 kΩ** (tabla TI). `WAKE` NC. `RSTn` → net `TRIG_N` (OR open-drain
con P12 / BTN). Sin TLC555. **No** ata `EN`.

**DONE (nivel):** VDD=5 V exige DONE ≥ ~3,5 V. IO15 solo da 3,3 V → **NPN
open-drain** (`Q_DONE` 2N3904): colector = DONE + PU 10 k a `5V_BUS`; base ←
IO15 vía 1 k. Idle firmware: IO15 **alto** (DONE bajo). Pateo: pulso IO15
**bajo** (DONE sube = clear WDT).

**74HCT123** @ `5V_BUS`: trig en **A1** ← `TRIG_N` (flanco bajada; B1=VCC).
**Q** → net `HCT_Q` → 1 k → gate Q1 ~2 s (R 100 k + C 47 µF en RCx).
A1 y Q son nodos distintos (no se unen). Mitad 2: A2=VCC, B2=GND, `/CLR2`=GND.

**/CLR blank:** al enchufar, RC 100 k + 2,2 µF mantiene `/CLR` bajo ~220 ms
(> POR TPL ~120 ms) para no disparar el one-shot por el POR del TPL.

**RESET gabinete / P12:** bajan `TRIG_N` a GND → flanco en A → nuclear ~2 s.

```text
IO15 ──1k── Q_DONE ── DONE ── TPL5010@BUS ── RSTn ──┐
                                                    ├── TRIG_N ──► A1 74HCT123
SYS_KILL (P12 pulso bajo) ──────────────────────────┤              Q ──► HCT_Q ──1k── Q1 gate
BTN_RESET / SW1 ── GND ─────────────────────────────┘
/CLR1 ── RC blank (100k+2.2u a BUS/GND)
```

### MOSFET high-side

```text
5V_BUS ── S NDP6020P D ── 5V_SYS (= módem)
              G ── 100k GND ── 1k ← HCT_Q ← Q (74HCT123)
```

Solo **Q1** (sin Q3). OR rieles = LM66200.

### EN del buck-boost

```text
5V_PSU ── 10k ── PSU_DET ── 100k a GND ── 10k ── base Q_EN
Gel+ ── 10k ── BB_EN ── collector Q_EN (emitter GND)
```

Hay PSU → Q_EN ON → EN≈0 → backup off. Sin PSU → EN a Gel+ → backup on.

Usar la gel en un corte es normal. Lo que la mata es seguir chupando
cuando ya está vacía (menos de ~5,5 V, sulfato). El convertidor de backup
no corta solo: quiere 5,1 V hasta que no puede más.

### ADC gel (firmware) + LVD (hardware)

**ADC (v1):** Gel+ al WT32 **IO35** (ADC1, pin libre). No IO36 (ZMPT) ni
32/33 (I2C).

```text
Gel+ ── 47 kΩ ──┬── IO35
                └── 22 kΩ a GND
                └── 100 nF a GND
```

~2,2 V a 6,9 V; ~1,75 V a 5,5 V. Medir Gel+ vs GND del equipo. MQTT:
tensión, aviso p.ej. bajo 6,0 V. El firmware puede bajar EN bajo 5,5 V;
si el ESP está muerto, no alcanza.

**LVD (después, en `5V_BUS`):** comparador o TL431 al mismo EN del buck-boost
(bajar EN sin el ESP). Gel bajo 5,5 V → backup off. No hace falta ADS1115.

---

## 10. GPIO WT32 — mapa (v1.5.3)

Header útil **lleno** (0 libres). `SYS_KILL` va por PCF P12.

| GPIO | Uso |
| ---- | --- |
| 0 | ETH REFCLK + SW_BOOT |
| 1 / 3 | UART0 ↔ FT232 |
| 2 | A7672 PWRKEY |
| 4 | A7672 RESET |
| 5 / 17 | UART módem RX / TX |
| 12 | RS485 TX |
| 14 | DS18B20 |
| 15 | TPL5010 DONE (vía NPN; idle alto, pateo bajo) |
| 16, 18, 23 | Ethernet (interno) |
| 32 / 33 | I2C SDA / SCL |
| 35 | ADC gel |
| 36 | ZMPT |
| 39 | RS485 RX |
| EN | SW_EN lab only |

`SYS_KILL`: PCF **P12** (pulso **bajo** = nuclear). Servicio: PCF **P02**.

---

## 11. Enlace A ↔ B (proto; después una placa)

Dos placas 9×15: A = fuente / WDT / MOSFET, B = electrónica. Se unen con
**bornera 5,08** (5 V) y **Molex KK 2,54** o más bornera (señales). **No
cinta IDC-10.** Cable a cable, pinout marcado en ambos lados. 5 V en
**0,75 mm²**. Cuando A y B anden, esas nets pasan a pistas en **una sola
placa** y J7–J10 desaparecen.

`5V_BUS` y `5V_PSU` se quedan en A. TPL5010 y 74HCT123 viven de `5V_BUS` en A
(no necesitan 3V3 de B). Pin 6 `3V3` queda por si hace falta. No pasar `GEL+`.

**J7 / J8 — 5 V (bornera 5,08)**

| Pin | Net | Dirección |
| --- | --- | --- |
| 1 | GND | — |
| 2 | `5V_SYS` | A → B |
| 3 | GND | — |
| 4 | `5V_SYS` | A → B |

**J9 / J10 — señales (Molex KK o bornera)**

| Pin | Net | Dirección |
| --- | --- | --- |
| 1 | `GEL_ADC` | A → B |
| 2 | `IO15` | B → A |
| 3 | `TRIG_N` | B → A (P12 SYS_KILL) |
| 4 | `SPARE` | — |
| 5 | `TRIG_N` | B → A (BTN panel) |
| 6 | `3V3` | B → A |
| 7 | `SPARE2` | — |
| 8 | GND | — |

Si un pin de señal queda abierto: el equipo falla (WDT, ADC, nuclear) pero no
se quema: gate Q1 con 100 k a GND **en A**; `TRIG_N` con PU 100 k a BUS. Si
falta **GND** y sigue habiendo 5 V, sí se puede romper el ESP.

---

## 12. Recuperación

1. AT (CFUN, hangup).
2. RESET del A7672 (~2,5 s).
3. PWRKEY cycle.
4. Nuclear `5V_SYS` (ESP + PHY + módem): TPL timeout, `SYS_KILL`, o **BTN RESET**.

---

## 13. Qué va al frente vs adentro

**Frente (gabinete):** LEDs PWR, NET, ALARMA. Botón RESET hundido. Bornes IN1–2, OUT1–2. Jack Ethernet. Buzzer adentro. (SIM / SMA antena según mecánica.)

**Adentro:** WT32, A7672, OLED, SHT31, PCF, ZMPT, fuente 5 V 5 A, XY-SJVA
(carga gel), buck-boost 5 A (backup), TPL5010, 74HCT123, NDP6020P×1, divisor
gel en IO35, botón de servicio (PCF P02), USB-serial FT232.

### Pedido AE (un prototipo)

Igual a `hardware/COMPRA_V1.md` (rev **1.5.3**). Gel **6 V 7 Ah** acá. Fuente **5 V 5 A**: ya comprada.

Piezas clave vs 1.4: **2N3904×2**, **TPL5010**, **74HCT123**, **PCF8575**, PC817
2CH, water detector, relé opto 2CH, RS485 auto, FT232, LED LTE. Salen: HCT14,
CD4541, TLC555, ULN2003, PCF8574, Q3/MODEM_CUT, relés sueltos.

No ZK-S4 / XL4015 / XL6009 1-pote / IRF4905 / cinta IDC / SB560 / 2N7000 /
HCT125 / TLC555 / NE555 / shifter I2C.

XY-SJVA: CV **6,85 V**, CC **0,6 A**, vacío primero. No unir IN−/OUT− si el
tester los ve abiertos. LED verde de “lleno” no vale para gel.

### Seguridad en el proto (rev 1.5.3)

- Gate Q1 definido **en A** (100 k a GND; idle ON).
- EN backup: R2 a Gel+; **Q_EN** baja EN si hay PSU.
- **SYS_KILL** (P12 pulso bajo) + BTN + TPL RSTn → `TRIG_N` → 74HCT123 → Q1.
- LEDs NET/ALARM/LTE a **3V3** (mismo dominio que PCF). Buzzer 5 V solo vía **Q_BZ**.
- **LM66200**: OR PSU+backup. No puentear `5V_PSU` con `5V_BUS`.
- TPL5010 a `5V_BUS`; DONE vía NPN OD; REXT 57,6 kΩ (~10 min); `/CLR` blank.
- PHY nRST: solo sink vía 1N4148; no pelear el RC del módulo.
- FT232: GND+TX+RX; **no** 5 V USB al WT32.
- Enlace proto: bornera / Molex, no IDC. No hot-plug. No 5 V y 3V3 a la vez en el WT32.

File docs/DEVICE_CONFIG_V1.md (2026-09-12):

# Device configuration contract v1

This document defines the first CallOnFail device configuration contract.

The backend owns the desired configuration. The device stores the latest valid
configuration locally and reports what it applied.

## MQTT topics

For a device with ID `cof-000001`:

```text
devices/cof-000001/telemetry
devices/cof-000001/event
devices/cof-000001/status
devices/cof-000001/config/desired
devices/cof-000001/config/reported
devices/cof-000001/command
devices/cof-000001/ack
```

The `device_id` must match the backend device record created in `/devices/new`.
For lab testing, the seeded/default device is:

```text
cof-test
```

Recommended QoS:

```text
telemetry          QoS 0
event              QoS 1
status             QoS 1
config/desired     QoS 1, retained
config/reported    QoS 1
command            QoS 1
ack                QoS 1
```

## Desired config

Example payload published by the backend to:

```text
devices/cof-000001/config/desired
```

```json
{
  "schema_version": 1,
  "config_version": 1,
  "device_id": "cof-000001",
  "telemetry_interval_seconds": 60,
  "sensors": [
    {
      "id": "temp_1",
      "name": "Temperatura freezer",
      "type": "temperature",
      "enabled": true,
      "source": "ds18b20"
    },
    {
      "id": "temp_2",
      "name": "Temperatura ambiente",
      "type": "temperature",
      "enabled": true,
      "source": "sht31_temperature"
    },
    {
      "id": "humidity_1",
      "name": "Humedad ambiente",
      "type": "humidity",
      "enabled": true,
      "source": "sht31_humidity"
    },
    {
      "id": "mains_1",
      "name": "Red electrica",
      "type": "mains_voltage",
      "enabled": true,
      "source": "zmpt101b"
    },
    {
      "id": "water_1",
      "name": "Fuga de agua",
      "type": "water_leak",
      "enabled": true,
      "source": "input_1",
      "mode": "normally_open"
    }
  ],
  "outputs": [
    {
      "id": "output_1",
      "name": "Sirena",
      "type": "relay",
      "enabled": true
    },
    {
      "id": "output_2",
      "name": "Salida auxiliar",
      "type": "relay",
      "enabled": true
    }
  ],
  "calling": {
    "enabled": false,
    "max_attempts_per_alarm": 0,
    "notes": "Enable only for customers that want phone calls."
  },
  "audio": [
    {
      "id": "test_call",
      "enabled": false,
      "description": "Audio de prueba. El archivo debe validarse con una llamada real.",
      "url": "https://ota.callonfail.com.ar/audio/test_call.wav",
      "sha256": "",
      "modem_path": "C:/test_call.wav",
      "format": "wav_pcm_8000_mono_16bit"
    }
  ],
  "contacts": [
    {
      "id": "owner",
      "name": "Responsable",
      "phone": "+549XXXXXXXXXX"
    },
    {
      "id": "backup",
      "name": "Backup",
      "phone": "+549XXXXXXXXXX"
    }
  ],
  "rules": [
    {
      "id": "high_temperature",
      "enabled": true,
      "condition": {
        "sensor": "temp_1",
        "operator": ">",
        "value": 40,
        "duration_seconds": 60
      },
      "flow": "temperature_alarm"
    }
  ],
  "flows": [
    {
      "id": "temperature_alarm",
      "steps": [
        {
          "type": "call",
          "contact": "owner",
          "audio": "test_call"
        },
        {
          "type": "wait",
          "seconds": 120
        },
        {
          "type": "call",
          "contact": "backup",
          "audio": "test_call"
        },
        {
          "type": "output",
          "output": "output_1",
          "state": true,
          "seconds": 30
        }
      ]
    }
  ]
}
```

## Calling and audio model

Keep these concepts separate:

### Modem capability

Reported by firmware as telemetry/status:

```json
{
  "modem_ready": true,
  "audio_play_supported": true,
  "file_transfer_supported": true
}
```

This only means the modem supports the AT commands. It does **not** prove that
the customer wants calls enabled or that the audio was heard in a real call.

### Customer/device configuration

Controlled from the web:

```json
{
  "calling": {
    "enabled": false,
    "max_attempts_per_alarm": 0
  },
  "audio": [
    {
      "id": "test_call",
      "enabled": false,
      "url": "https://ota.callonfail.com.ar/audio/test_call.wav",
      "sha256": "",
      "modem_path": "C:/test_call.wav"
    }
  ]
}
```

If `calling.enabled` is false, the device must not place phone calls even if the
modem is ready. Alarm email, Telegram chat ID and phone number are stored on
the tenant (see `docs/NOTIFICATIONS.md`). Device `notifications` in this JSON
is a leftover override only.

Audio assets should be dynamic. A customer may have no audio assets, one shared
test audio, or different audios per alarm flow.

### Runtime status

Reported by firmware/backend after real operations:

```json
{
  "calling_enabled": false,
  "audio_assets": [
    {
      "id": "test_call",
      "modem_path": "C:/test_call.wav",
      "sync_status": "not_required",
      "last_sync_at": null,
      "last_play_result": null,
      "validated_by_real_call": false
    }
  ]
}
```

Recommended status values:

```text
not_required
pending
synced
sync_failed
play_command_ok
play_command_failed
validated_by_real_call
```

The product should show audio as "validated" only after a real call test proves
that the remote side heard the expected audio.

## Reported config

After validating and storing the desired config, the device publishes:

```text
devices/cof-000001/config/reported
```

```json
{
  "schema_version": 1,
  "device_id": "cof-000001",
  "config_version": 1,
  "applied": true,
  "config_hash": "sha256-of-canonical-config",
  "firmware": "0.1.4",
  "message": "config applied"
}
```

If config cannot be applied:

```json
{
  "schema_version": 1,
  "device_id": "cof-000001",
  "config_version": 1,
  "applied": false,
  "error": "unsupported sensor source input_3"
}
```

## Telemetry

The device publishes telemetry to:

```text
devices/cof-000001/telemetry
```

```json
{
  "device_id": "cof-000001",
  "firmware": "0.1.4",
  "uptime_seconds": 12345,
  "ip": "192.168.1.10",
  "ethernet": true,
  "wifi": true,
  "network": {
    "active": "ethernet",
    "ethernet": { "up": true, "ip": "192.168.1.10" },
    "wifi": {
      "configured": true,
      "up": true,
      "ssid": "RedDelSitio",
      "ip": "192.168.1.20",
      "rssi": -62
    },
    "lte": { "up": false, "ip": "-" }
  },
  "temperature_1": 24.8,
  "temperature_2": 25.1,
  "humidity": 52.0,
  "mains_voltage": 221.4,
  "water_leak": false,
  "input_1": false,
  "input_2": false,
  "output_1": false,
  "output_2": false,
  "modem_ready": true,
  "lte_signal": 18
}
```

## Hardware profile and discovery

Devices publish capabilities and discovered resources in `status` messages.
These payloads are retained and event-driven, not high-frequency telemetry.
Devices publish them:

- when MQTT connects,
- when Ethernet or WiFi gains or loses an IP,
- when hardware discovery changes,
- when the backend sends `status_report`.

Ethernet is the default route when both LAN links are up. WiFi is a backup
path. If Ethernet and WiFi are down, MQTT uses LTE data on the A7672.
Do **not** put WiFi passwords in retained `config/desired`; use the
`set_wifi` / `clear_wifi` commands.

Example:

```json
{
  "device_id": "cof-test",
  "status": "online",
  "firmware": "0.2.4",
  "ip": "192.168.1.10",
  "ethernet": true,
  "wifi": true,
  "network": {
    "active": "ethernet",
    "ethernet": { "up": true, "ip": "192.168.1.10" },
    "wifi": {
      "configured": true,
      "up": true,
      "ssid": "RedDelSitio",
      "ip": "192.168.1.20",
      "rssi": -62
    },
    "lte": { "up": false, "ip": "-" }
  },
  "hardware_profile": "cof-wt32-a7672-v1",
  "capabilities": {
    "ethernet": true,
    "wifi": true,
    "modem_a7672": true,
    "phone_calls": true,
    "audio_playback": true,
    "modem_file_transfer": true,
    "sht31": true,
    "ds18b20_bus": true,
    "max_ds18b20": 8,
    "mains_voltage": true,
    "pcf8574": true,
    "external_inputs": 2,
    "external_outputs": 2
  },
  "discovered": {
    "sht31": true,
    "pcf8574": true,
    "modem": true,
    "cellular": {
      "registered": true,
      "radio": "LTE",
      "model": "A7672SA-FASE",
      "ims": false,
      "csq": 31,
      "operator": "722310",
      "voice": {
        "path": "csfb",
        "last_ok": "csfb",
        "cs_attached": true,
        "radio": "LTE",
        "ims": false
      }
    },
    "ds18b20_count": 2,
    "ds18b20": [
      "28FF641D4C1603A1",
      "28FF882B2D1804B3"
    ]
  }
}
```

The backend stores this on the device record and uses it to guide dynamic
configuration. The UI should eventually let users map discovered physical
resources to logical sensors, for example:

```text
28FF641D4C1603A1 -> Freezer 1
28FF882B2D1804B3 -> Freezer 2
input_1          -> Fuga de agua
output_1         -> Sirena
```

## Archived devices

Devices should be archived instead of hard-deleted.

If an archived device continues publishing MQTT:

- the backend keeps the device archived,
- normal telemetry is not stored,
- an `archived_device_message` warning event is recorded,
- config and command actions are disabled until the device is restored.

This prevents a retired/deleted device from being recreated as active just
because it is still powered on and publishing.

To reuse an archived physical device for another customer, restore/reassign it:

```text
/devices?include_archived=1
-> Editar/reasignar
-> select new tenant/site
-> Guardar y restaurar
```

The same `device_id` is preserved, so the firmware does not need to change if it
continues using that MQTT identity.

## Events

The device publishes alarm/state changes to:

```text
devices/cof-000001/event
```

```json
{
  "device_id": "cof-000001",
  "type": "temperature_high",
  "severity": "alarm",
  "message": "Temperatura freezer mayor a 40 C",
  "sensor": "temp_1",
  "value": 42.5,
  "threshold": 40
}
```

## Commands

The backend can publish commands to:

```text
devices/cof-000001/command
```

### Force OTA check

Firmware updates should be explicit commands, not automatic background updates.
The device can still poll the manifest for auxiliary metadata, but firmware
upgrade should happen through this command, Serial `o`, or a physical
maintenance action.

```json
{
  "command_id": "uuid",
  "command": "ota_check",
  "device_id": "cof-000001",
  "created_at": "2026-09-03T00:00:00Z"
}
```

### Force status/capabilities report

```json
{
  "command_id": "uuid",
  "command": "status_report",
  "device_id": "cof-000001",
  "created_at": "2026-09-03T00:00:00Z"
}
```

The device responds with an ACK and publishes a fresh retained `status` message
including `hardware_profile`, `capabilities`, `discovered`, and `network`.

### Set WiFi credentials

Install with Ethernet first, then publish this from the device page. QoS 1, **not
retained**. The firmware stores SSID/password in NVS (same keys as Serial
`wifi`) and associates in STA mode. The ACK and the backend Event store the
SSID only; `password` is stored as a boolean.

```json
{
  "command_id": "uuid",
  "command": "set_wifi",
  "device_id": "cof-000001",
  "ssid": "RedDelSitio",
  "password": "...",
  "created_at": "2026-09-12T00:00:00Z"
}
```

### Clear saved WiFi

```json
{
  "command_id": "uuid",
  "command": "clear_wifi",
  "device_id": "cof-000001",
  "created_at": "2026-09-12T00:00:00Z"
}
```

The device forgets NVS credentials and disconnects WiFi. Ethernet is unchanged.

### Test call with audio

An explicit operator action from the device page. The backend synthesizes the
form text to AMR-NB 8 kHz (`docs/VOICE_SMS.md`) and the device
downloads `audio_url` into `C:/tts.amr` before dialing.

This command may place a call even if `calling.enabled` is false. Automatic
alarm calls still require `calling.enabled=true`.

```json
{
  "command_id": "uuid",
  "command": "test_call",
  "device_id": "cof-000001",
  "phone": "+5491112345678",
  "text": "CallOnFail prueba de llamada",
  "audio_url": "https://app.callonfail.com.ar/audio/tmp/<32-hex>.amr",
  "audio_format": "amr_nb_8000",
  "created_at": "2026-09-04T00:00:00Z"
}
```

The device ACKs immediately, downloads TTS audio when `audio_url` is present,
prepares CS radio if VoLTE is not registered, then publishes an `event` of type
`test_call`. A result that starts with `Call done` is success, even when
radio/IMS/CEER details are appended. `discovered.cellular.voice.path` is
inferred live from IMS, radio and `CREG`: `volte`, `csfb`, `gsm`, `lte_data`,
or `none`. A new IMSI/operator clears the last learned path so another SIM is
re-diagnosed.

### Test SMS

```json
{
  "command_id": "uuid",
  "command": "test_sms",
  "device_id": "cof-000001",
  "phone": "+5491112345678",
  "text": "CallOnFail prueba SMS",
  "created_at": "2026-09-03T00:00:00Z"
}
```

The device ACKs immediately, sends the SMS with `AT+CMGF=1` / `AT+CMGS`,
then publishes an `event` of type `test_sms` with the result.

The device responds to:

```text
devices/cof-000001/ack
```

```json
{
  "device_id": "cof-000001",
  "command_id": "uuid",
  "command": "ota_check",
  "status": "accepted",
  "message": "OTA check scheduled",
  "firmware": "0.2.3"
}
```

## Local vs cloud behavior

The cloud is the source of truth for desired configuration, but devices must
keep the latest valid config locally and continue critical alarm behavior when
offline. WiFi credentials are an exception: they live only on the device NVS
and are set with `set_wifi` / `clear_wifi` (or Serial), never in retained
`config/desired`.

The backend should show:

```text
desired config version
reported config version
applied/pending/error
last config report time
```

## MVP web test flow

1. Open the device page:

   ```text
   http://<VPS_STATIC_IP>/devices/cof-test
   ```

2. Click `Editar/publicar configuracion`.
3. Save the JSON.
4. The backend stores a new `device_configs` row.
5. The backend publishes the payload retained to:

   ```text
   devices/cof-test/config/desired
   ```

6. Firmware receives the config, stores `config_version` and `config_hash`, then publishes:

   ```text
   devices/cof-test/config/reported
   ```

7. The MQTT worker stores the report and updates the device's reported config
   version.
8. Refresh the device page and verify:

   ```text
   Config deseada/reportada: <same version> / <same version>
   ```

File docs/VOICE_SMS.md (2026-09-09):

# Voice and SMS — validated lab (2026-09-04)

This is the working reference for outgoing **test calls** and **test SMS**
on the current lab device. Follow this before changing radio, audio, or Claro
settings.

Validated on:

```text
Device:     cof-test
Hardware:   WT32-ETH01 + A7672
SIM:        Claro Argentina (operator 722310)
Firmware:   0.2.42 (inbound SMS for OK ack, plus command_id on call/SMS result)
MQTT:       mqtt.callonfail.com.ar:1883 (anonymous, no TLS)
Web:        https://app.callonfail.com.ar/devices/cof-test
```

Both **Probar SMS** and **Probar llamada** succeeded from the web on this setup.

## What not to change without a new live test

- Do not default MQTT to port `8883` / TLS until the broker actually serves TLS.
- Do not dial CSFB on a stale LTE attach as the first `ATD`.
- Do not rely on `AT+CTTS` (on-modem TTS). Many A7672 builds return `ERROR`.
- Do not treat `device.status == online` in the DB as live. The UI uses
  `last_seen_at` (fresh if younger than 3 minutes).
- Keep `COF_ENABLE_CALLS` at `0` in firmware. Admin test-call/SMS bypass it.
  Automatic alarm calls still require `calling.enabled=true` in device config.

## Claro / modem config (compiled in firmware)

From `include/cof_config.h`:

```text
APN       internet.claro.com.ar
APN user  clarogprs
APN pass  clarogprs777
SMSC      +5491115030500
```

Idle radio stays automatic (`AT+CNMP=2`) so LTE is used for SMS and signal.
Voice-centric LTE: `AT+CEMODE=1`, `AT+CEVDP=3`, `AT+CAVIMS=1`.

VoLTE (`CIREG` / IMS registered) was **not** the working path on this SIM.
The working voice path is **CS after a radio bounce**, then one dial.

## Voice call sequence (must keep)

On LTE without IMS, the first `ATD` usually returns `NO CARRIER`. That is not
a “retry that sometimes works”: the CS domain was not ready. Firmware 0.2.27+
does this **before** the first dial:

1. Download TTS AMR (test call only).
2. `AT+CFUN=4` → wait → `AT+CFUN=1` (RF bounce).
3. Wait until `CREG` / radio online / `CPAS` idle / CSQ valid.
4. One `ATD<E.164>;` (semicolon required for voice).
5. Wait for connect URCs (ignore early CSFB `NO CARRIER` for ~40 s).
6. `AT+CCMXPLAY="C:/tts.amr",1,0` (remote path = into the call).
7. Hang up, restore `AT+CNMP=2` and packet/SMS services.

If that still fails, fallback is lock GSM (`AT+CNMP=13`), dial once, then
restore LTE.

Progress events on the device page (in order on a good call):

```text
Downloading TTS audio
Preparing CS radio
Dialing, waiting for voice
Call done [...]
```

Claro CSFB event table, traces and what we can mark:
[docs/operators/claro-ar.md](operators/claro-ar.md).

## Test SMS

Web publishes:

```json
{
  "command": "test_sms",
  "device_id": "cof-test",
  "phone": "+549...",
  "text": "CallOnFail prueba de llamada"
}
```

Firmware waits until the SMS stack is ready (`CMGF` / `CPMS`), keeps the SIM
SMSC, then `AT+CMGS`. Result event `SMS sent` is success.

After a failed CSFB call, firmware restores LTE + SMS bearer so SMS still
works. Do not poll `AT` during an active CSFB in a way that aborts the call.

## Test call audio (AMR-NB)

The text field on the device page is used for **SMS and spoken call audio**.
SMS still caps at 160 characters. Call TTS accepts up to **800 characters**.

Backend (`backend/app/tts.py`):

1. Piper `es_AR-daniela-high` (español argentino; baked into the web image).
2. `ffmpeg` → **AMR-NB 8 kHz, 12.2 kbps** (`#!AMR\n`). About 1.5 KB/s vs 16 KB/s WAV.
3. File lives in `/tmp/cof-tts/<id>.amr` for 15 minutes.
4. Public URL: `https://app.callonfail.com.ar/audio/tmp/<id>.amr`

ESP32 RAM still buffers the whole file (`kMaxAudioBytes` 180 KB). AMR at 12.2 kbps
fits ~**2 minutes** of speech; 800 characters is typically under a minute.

VPS `.env` must include:

```text
PUBLIC_BASE_URL=https://app.callonfail.com.ar
```

MQTT command:

```json
{
  "command": "test_call",
  "device_id": "cof-test",
  "phone": "+549...",
  "text": "CallOnFail prueba de llamada",
  "audio_url": "https://app.callonfail.com.ar/audio/tmp/<32-hex>.amr",
  "audio_format": "amr_nb_8000"
}
```

Device downloads over Ethernet (HTTPS, cert not verified) into RAM, deletes any
previous `C:/tts.amr` (`AT+FSDEL`), uploads with `AT+CFTRANRX`, plays remote,
then restores the previous modem audio path. If this fails, the event message
is specific (`TTS HTTP 404`, `TTS too large`, `TTS no RAM`, etc.).

Admin test-call **bypasses** `calling.enabled`. Alarm-driven calls must not.

The canned `cof_test.wav` on the modem stays WAV; only spoken test-call audio
is AMR.

## Web / MQTT ops

- Commands: `devices/<id>/command` QoS 1, not retained.
- ACK: `devices/<id>/ack`.
- Call/SMS result: `devices/<id>/event` types `test_call` / `test_sms`.
- Cellular card is **not live** unless `last_seen_at` is < 3 minutes old.
  Stale LTE/CSQ is shown as last report, not “Conectado”.
- Firmware OTA still only on web **OTA**, Serial `o`, or long button press.
- MQTT silence: no successful publish for 3 min → reconnect; 6 min →
  `ESP.restart()`. A WT32-ETH01 LAN8720 PHY hang may still need a **power
  cycle** (PHY reset is not wired to a GPIO).

## After deploy

```bash
cd /opt/callonfail
git pull
docker compose up -d --build web
docker compose up -d caddy
```

Firmware OTA reads the GitHub manifest, then downloads
`https://app.callonfail.com.ar/ota/firmware.bin` from this VPS (same host as TTS).
Do that deploy **before** pressing OTA on a 0.2.30 device.

Device must already be on firmware `>= 0.2.31` (OTA) to download AMR `audio_url`.
If ACK is `unsupported`, OTA first.

## Still pending (do not mix with this win)

1. MQTT TLS + per-device passwords — only with Serial access to the ESP32.

Alarmas por regla, email, Telegram y **Disparar esta alarma** estan en
`docs/NOTIFICATIONS.md`. El telefono/email/chat van en el cliente.

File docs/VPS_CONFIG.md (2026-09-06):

# CallOnFail VPS configuration

This file is the shared source of truth for VPS setup and operations. Update it
whenever the server, deployment, DNS, MQTT, TLS, backups, or Docker layout
changes.

## Current goal

Run CallOnFail on a single AWS Lightsail VPS (2 vCPU / 2 GB) using Docker
Compose:

- Flask + Gunicorn web/API service (`app.callonfail.com.ar`).
- Public static marketing site (`www.callonfail.com.ar`, apex redirects to www).
- PostgreSQL database.
- Redis.
- Mosquitto MQTT broker.
- MQTT worker.
- Caddy reverse proxy + Let's Encrypt TLS.

Current Lightsail public IP (update if the instance changes):

```text
54.207.204.86
```

## VPS baseline

Recommended baseline (current Lightsail matches the minimum):

- Ubuntu 24.04 LTS.
- 2 vCPU.
- 2 GB RAM minimum, 4 GB RAM preferred.
- 60 GB SSD minimum.
- Static public IP.

The marketing site is static and cheap. The tight resource is RAM for
Postgres + Gunicorn + MQTT worker. Keep Gunicorn at 2 workers on 2 GB. Add
1–2 GB swap if the instance OOMs under load.

## DNS plan

Cloudflare manages `callonfail.com.ar`.

Recommended DNS records (A only; do **not** publish AAAA unless the VPS has
working IPv6 and Caddy listens on it):

```text
callonfail.com.ar        A    <VPS_STATIC_IP>
www.callonfail.com.ar    A    <VPS_STATIC_IP>
app.callonfail.com.ar    A    <VPS_STATIC_IP>
api.callonfail.com.ar    A    <VPS_STATIC_IP>
mqtt.callonfail.com.ar   A    <VPS_STATIC_IP>
ota.callonfail.com.ar    A    <VPS_STATIC_IP>
```

Cloudflare proxy mode for Caddy + Let's Encrypt:

```text
callonfail.com.ar        DNS only   (grey cloud)
www.callonfail.com.ar    DNS only
app.callonfail.com.ar    DNS only
api.callonfail.com.ar    DNS only
mqtt.callonfail.com.ar   DNS only
ota.callonfail.com.ar    DNS only
```

Use **DNS only** while Caddy obtains/renews certificates with HTTP-01. If a
hostname is still Proxied (orange cloud), Cloudflare may publish AAAA to their
edge; Let's Encrypt prefers IPv6 and the ACME challenge returns 404 → no cert
→ browser errors (Cloudflare 525 if proxied, or TLS handshake errors if DNS
only).

MQTT must stay `DNS only` because the normal Cloudflare proxy does not proxy
raw MQTT on port 8883.

After certificates exist, orange-cloud + SSL mode Full (strict) is optional.
While certificates are missing, Flexible can hide the problem temporarily but
is not the target setup.

## Public marketing website

Static HTML lives in the repo under `website/` and is served by Caddy:

```text
https://www.callonfail.com.ar/     -> website/index.html
https://www.callonfail.com.ar/sala/    -> pack Sala / Rack
https://www.callonfail.com.ar/energia/ -> pack Energía
https://www.callonfail.com.ar/ot/      -> pack OT / Tablero
https://www.callonfail.com.ar/frio/    -> pack Cadena de frío
https://callonfail.com.ar/         -> redirect to www
https://app.callonfail.com.ar/     -> Flask app
```

SEO helpers in `website/`:

```text
robots.txt
sitemap.xml
```

After deploy, submit `https://www.callonfail.com.ar/sitemap.xml` in Google Search Console.
For ads, point campaigns to the pack URLs (`/sala/`, `/energia/`, `/ot/`, `/frio/`)
with unique WhatsApp prefill text per landing.
Do **not** open the Flask app by raw IP (`https://<VPS_IP>/...`). After
`APP_DOMAIN=app.callonfail.com.ar`, Caddy only routes the app on that hostname.
Use:

```text
https://app.callonfail.com.ar/
https://app.callonfail.com.ar/devices/cof-test
```

Update the marketing site from the VPS:

```bash
cd /opt/callonfail
git pull origin main
```

Content is bind-mounted; `git pull` is enough for HTML/CSS/assets. Recreate
Caddy only if `deploy/caddy/Caddyfile` or compose volumes changed:

```bash
docker compose up -d caddy
```

## TLS / ACME notes

Production `.env` must use the real app hostname (not `:80`):

```text
APP_DOMAIN=app.callonfail.com.ar
ACME_EMAIL=admin@callonfail.com.ar
```

`:80` is only for a first lab boot before DNS exists. Leaving it set while
`www` / apex are also in the Caddyfile makes HTTPS confusing and is not the
production layout.

Verify certificates from the VPS with correct SNI (do not curl bare `127.0.0.1`
over HTTPS without `--resolve`):

```bash
curl -Ik --resolve www.callonfail.com.ar:443:127.0.0.1 https://www.callonfail.com.ar/
curl -Ik --resolve app.callonfail.com.ar:443:127.0.0.1 https://app.callonfail.com.ar/health
docker compose logs caddy --tail 80 | grep -iE 'certificate obtained|acme|error'
```

If ACME is stuck after fixing DNS, clear Caddy cert state and retry:

```bash
docker compose stop caddy
docker volume ls | grep caddy
docker run --rm -v callonfail_caddy_data:/data alpine \
  sh -c 'rm -rf /data/caddy/certificates /data/caddy/acme /data/caddy/locks'
docker compose up -d caddy
docker compose logs -f caddy
```

Replace `callonfail_caddy_data` with the volume name from `docker volume ls`.

## VPS firewall

Open in AWS Lightsail networking and Ubuntu UFW:

```text
22/tcp    SSH
80/tcp    HTTP
443/tcp   HTTPS
8883/tcp  MQTT over TLS, later
```

Do not expose `1883/tcp` publicly for production.

Current Docker Compose publishes Mosquitto only on localhost:

```text
127.0.0.1:1883:1883
```

This is intentional until TLS/authentication are configured.

For a short lab test from an ESP32 outside the VPS, set this in `.env`:

```text
MQTT_BIND_ADDRESS=0.0.0.0
```

Unknown MQTT devices are ignored by default:

```text
MQTT_AUTO_PROVISION=false
```

For lab-only auto creation of unknown devices, set it to `true`. Production
should keep it disabled and create/provision devices from the web.

Then recreate services:

```bash
docker compose up -d --build
```

Open port `1883/tcp` only temporarily in AWS Lightsail and UFW:

```bash
sudo ufw allow 1883/tcp
```

Close it after the test:

```bash
sudo ufw delete allow 1883/tcp
```

## Initial server packages

```bash
sudo apt update
sudo apt upgrade -y
sudo apt install -y git curl ufw fail2ban ca-certificates
```

## Docker installation

```bash
curl -fsSL https://get.docker.com | sh
sudo usermod -aG docker ubuntu
```

Log out and log back in, then verify:

```bash
docker run hello-world
docker compose version
```

If Docker says permission denied:

```bash
sudo usermod -aG docker ubuntu
exit
```

Then reconnect over SSH.

## Ubuntu UFW setup

```bash
sudo ufw allow OpenSSH
sudo ufw allow 80/tcp
sudo ufw allow 443/tcp
sudo ufw allow 8883/tcp
sudo ufw enable
sudo ufw status
```

## Repository checkout

For branch testing:

```bash
sudo mkdir -p /opt
sudo chown ubuntu:ubuntu /opt
cd /opt
git clone -b cursor/backend-docker-setup-4c37 https://github.com/nmarcovecchio/cof.git callonfail
cd /opt/callonfail
```

After merge to `main`, use:

```bash
git clone https://github.com/nmarcovecchio/cof.git /opt/callonfail
cd /opt/callonfail
```

If the repo already exists:

```bash
cd /opt/callonfail
git pull
```

## Environment file

Create `.env` from the example:

```bash
cp .env.example .env
nano .env
```

For first boot without DNS/TLS:

```text
APP_DOMAIN=:80
```

After DNS points to the VPS:

```text
APP_DOMAIN=app.callonfail.com.ar
ACME_EMAIL=<admin-email>
```

UI timezone:

```text
APP_TIMEZONE=America/Argentina/Buenos_Aires
```

Dates are stored in UTC and rendered in the configured timezone with second
precision.

Admin login:

```text
SECRET_KEY=<long-random-secret>
ADMIN_USERNAME=admin
ADMIN_PASSWORD=<strong-password>
SESSION_COOKIE_SECURE=false
```

`/health` remains public for monitoring. Dashboard, device pages, config pages,
and command actions require login.

After HTTPS is confirmed, set:

```text
SESSION_COOKIE_SECURE=true
```

Always change:

```text
POSTGRES_PASSWORD=change-this-password
```

Do not commit `.env`.

## Docker operations

Start/build:

```bash
docker compose up -d --build
```

Status:

```bash
docker compose ps
```

Logs:

```bash
docker compose logs -f
docker compose logs -f web
docker compose logs -f mqtt-worker
docker compose logs -f mosquitto
```

Restart one service:

```bash
docker compose restart web
```

Stop:

```bash
docker compose down
```

## Health checks

From the VPS (use Host / `--resolve` once `APP_DOMAIN` is a real hostname):

```bash
curl -sS --resolve app.callonfail.com.ar:80:127.0.0.1 \
  http://app.callonfail.com.ar/health
curl -sk --resolve app.callonfail.com.ar:443:127.0.0.1 \
  https://app.callonfail.com.ar/health
curl -sk --resolve app.callonfail.com.ar:443:127.0.0.1 \
  https://app.callonfail.com.ar/api/status
```

From a browser after DNS/TLS:

```text
https://www.callonfail.com.ar/
https://app.callonfail.com.ar/
https://app.callonfail.com.ar/dashboard
https://app.callonfail.com.ar/devices/cof-test
```

Raw IP URLs are only useful for the first `:80` lab boot. In production they
will not serve the Flask app correctly.
## MQTT local test

Publish a test message inside the Mosquitto container:

```bash
docker compose exec mosquitto mosquitto_pub -h localhost -t devices/cof-test/telemetry -m '{"temperature":25.1}'
```

Watch the worker:

```bash
docker compose logs -f mqtt-worker
```

Expected result: the MQTT worker logs the incoming telemetry payload.

## MQTT ESP32 lab test

Preconditions:

- Firmware with MQTT support is running on the ESP32.
- ESP32 has Ethernet or WiFi internet.
- VPS `.env` has `MQTT_BIND_ADDRESS=0.0.0.0`.
- AWS Lightsail and UFW allow temporary `1883/tcp`.

From PlatformIO Monitor:

```text
mqtt <VPS_STATIC_IP> 1883 cof-test
mqtt-status
pub
```

Or, after DNS is configured:

```text
mqtt mqtt.callonfail.com.ar 1883 cof-test
mqtt-status
pub
```

Firmware lab default:

```text
MQTT host: mqtt.callonfail.com.ar
MQTT port: 1883
Device ID: cof-test
```

If no MQTT config is saved in the ESP32 preferences, firmware attempts to
connect to this endpoint automatically.

Watch the VPS:

```bash
docker compose logs -f mqtt-worker
```

Refresh:

```text
https://app.callonfail.com.ar/dashboard
```

## Resume at home — 2026-09-03 (updated 2026-09-04)

The ESP32 was recovered. **Test call and test SMS work.** Details and the
radio/audio config to keep: `docs/VOICE_SMS.md`.

### What is running now

- VPS Mosquitto: anonymous, public `1883` only. No TLS certs, no passwd.
- `docker-compose.yml` publishes `1883:1883` and `8883:8883`.
- Web config form is visual (sensors / rules / call on/off).
  Email, Telegram chat ID and phone live on the **tenant**.
  Rules are evaluated in `mqtt_worker`. Setup: `docs/NOTIFICATIONS.md`.
- Latest published firmware: `0.2.34`.
- Lab device `cof-test`: MQTT `1883`, Claro A7672. Voice = CS bounce then one
  dial. SMS = modem. Call audio = Piper `es_AR-daniela` → AMR-NB 8 kHz.

### Why OTA does not happen by itself

Hourly manifest check calls `checkManifest(false)` — it does **not** flash.
Firmware OTA only runs on MQTT command `ota_check` (web button) or Serial `o`.

Do **not** OTA a build that defaults/migrates MQTT to `:8883` until TLS is
actually up. `0.2.11` did that and left the device offline.

### Next (in this order)

1. Only with the ESP32 at hand: MQTT TLS + auth + per-device credentials.
   Follow the section below. Do not cut over remotely.

## Current security posture

Current MVP state (after 2026-09-03 revert):

- Marketing site and Web/API run behind Caddy with Let's Encrypt.
- PostgreSQL is internal to Docker.
- Redis is internal to Docker.
- Mosquitto is **lab mode again**:
  - `1883` public, `allow_anonymous true`
  - `8883` published in Compose but unused (no certs / no TLS listener)
- MQTT TLS + password + ACL cutover is **not** active. Do not re-enable it
  without Serial access to the ESP32.

## MQTT TLS + auth setup

### 1) DNS

Ensure Cloudflare has:

```text
mqtt.callonfail.com.ar   A    <VPS_STATIC_IP>    DNS only
```

### 2) VPS firewall / Lightsail

Open:

```text
8883/tcp
```

Close public `1883/tcp` if it was opened for lab tests:

```bash
sudo ufw delete allow 1883/tcp || true
sudo ufw allow 8883/tcp
sudo ufw status
```

Also remove `1883` from the Lightsail networking panel if present.

### 3) Update repo and env

```bash
cd /opt/callonfail
git pull
nano .env
```

Add/update:

```text
MQTT_BACKEND_USERNAME=backend
MQTT_BACKEND_PASSWORD=<strong-backend-pass>
MQTT_DEVICE_USERNAME=cof-test
MQTT_DEVICE_PASSWORD=<strong-device-pass>
MQTT_TLS_DOMAIN=mqtt.callonfail.com.ar
SESSION_COOKIE_SECURE=true
```

Use the same device password in firmware (`COF_DEFAULT_MQTT_PASSWORD`) before building/OTA.

### 4) Generate Mosquitto users

```bash
export MQTT_BACKEND_PASSWORD='...'   # same as .env
export MQTT_DEVICE_PASSWORD='...'    # same as .env
./deploy/mosquitto/gen-passwd.sh
```

### 5) Issue MQTT certificate via Caddy

```bash
docker compose up -d caddy
curl -I https://mqtt.callonfail.com.ar/
./deploy/mosquitto/sync-certs-from-caddy.sh
```

### 6) Start hardened Mosquitto + backend

```bash
docker compose up -d --build
docker compose ps
docker compose logs -f mosquitto
docker compose logs -f mqtt-worker
```

### 7) Point the ESP32 to TLS MQTT

Do **not** OTA a firmware that defaults/migrates to `:8883` until the
broker actually listens on TLS `8883`. `0.2.11` did that and left
`cof-test` offline. Recover over Serial first (see "Resume at home").

Manual Serial override:

```text
mqtt mqtt.callonfail.com.ar 8883 cof-test cof-test <device-password>
mqtt-status
```

### 8) Verify

From the VPS:

```bash
docker compose exec mosquitto mosquitto_pub \
  -h localhost -p 1883 \
  -u backend -P "$MQTT_BACKEND_PASSWORD" \
  -t devices/cof-test/command \
  -m '{"command":"status_report","device_id":"cof-test"}'
```

From dashboard: device should stay online and accept OTA/config commands.

## Deferred: finish MQTT security and per-device provisioning at home

This should be finished when physical access to the ESP32 is available, so the
device can be recovered over USB/Serial if the MQTT TLS cutover leaves it
offline.

Recommended order:

1. Keep current lab device (`cof-test`) working.
2. Finish MQTT TLS/auth cutover on the VPS.
3. OTA the firmware and confirm the existing device reconnects on `8883`.
4. Only after that, implement per-device credential provisioning in the web UI.

### Target provisioning model

For production, each device should have its own MQTT identity:

```text
username = device_uid
password = random secret generated by backend
ACL      = devices/<device_uid>/#
```

The current `.env` values:

```text
MQTT_DEVICE_USERNAME=cof-test
MQTT_DEVICE_PASSWORD=...
```

are only a bootstrap/lab setup for the current test device. They are not the
final multi-device model.

### Planned implementation

When resuming this work, implement the following in one pass:

1. Add a per-device MQTT credential record in the backend/database.
2. Generate a random password automatically when creating a new device.
3. Create/update the Mosquitto password entry for that device.
4. Show the credentials once in the UI together with a ready-to-paste Serial
   command:

```text
mqtt mqtt.callonfail.com.ar 8883 <device_uid> <device_uid> <device-password>
```

5. Store the credentials in ESP32 Preferences over Serial during first install.
6. Keep OTA/config/status fully remote after that first provisioning step.

### Why defer this to home

- The first provisioning flow still depends on Serial/USB.
- If TLS/auth is misconfigured, the device may stop reconnecting over MQTT.
- Physical access makes recovery safe and fast.

## Next backend milestones

1. Keep DNS grey-cloud for Caddy ACME (or move to CF origin certs if proxying).
2. Set `SESSION_COOKIE_SECURE=true` once HTTPS is confirmed.
3. Add database migrations.
4. Rotate MQTT device passwords per device (not shared lab password).
5. Add OTA release management under `ota.callonfail.com.ar`.
6. Add backups and basic server monitoring.

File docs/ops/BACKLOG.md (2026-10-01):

# Backlog de ingenieria — CallOnFail

Estado: **2026-09-30**. Ultimo firmware publicado: **0.2.130** (en `ota/manifest.json`).

**Validado en campo (cof-test, 0.2.129):** llamada **y** SMS funcionan por **Ethernet**
y por **LTE**. Voz por VoLTE; SMS prueba SMSoIP (10 s) y cae a CS/SGs con drop de
IMS cuando hace falta. Ver entrada 0.2.129 abajo.

Este archivo es la lista de trabajo tecnico pendiente (deuda, bugs conocidos,
hardening de proceso). **No** es el roadmap de producto: las funciones que
todavia no existen y no se pueden vender viven en `docs/ROADMAP.md`.

Regla: cuando un item se cierra, se borra de aca en el mismo commit que lo
arregla.

**Validado en campo (cof-test, 2026-09-26/27):** MQTT nativo CMQTT solo-LTE
estable (0.2.96+), telemetria y OLED OK, `OTA needs LAN` en vez de Manifest fail,
manifest servido desde el VPS (`/ota/manifest.json`), panel con live-update y
graficos por unidad.

**0.2.98 — UART debug:** comando MQTT `modem_uart_debug` (botones en device
detail). Con ON, ring AT con timestamps, dump cada 30s + snapshot al drop
(`modem_uart_debug` events en el panel Modem).

**0.2.99 — telemetria gemela + IPADDR nativo:** el intervalo de telemetria usa
`millis()` fresco (el `now` del inicio de `loop()` underflowaba tras un
reconnect CMQTT largo y republicaba ~2 s despues). En path nativo
`queryLteIp` ya no llama `AT+IPADDR` (siempre ERROR / 4 s); usa `CGPADDR=1`
(OLED/IP intactos).

**0.2.106 / 0.2.107 (historico, ya superado):** 0.2.106 mandaba `CMQTTDISC` al
llegar al limite de soft-fail PUB y eso reiniciaba el A7672; 0.2.107 lo cambio por
"bajar flags + `CONNECT`" con un guard `cmqttSoftReclaimPending()` que evitaba el
`STOP` — ese guard **se borro en 0.2.108** y el `CONNECT` a ciegas sobre sesion
viva resulto ser otro gatillo de reboot. Nada de esto sigue en el codigo.

**0.2.108 — cooldown en vez de CONNECT + UART debug respeta OFF:** 0.2.107
siguio en reboots porque `CMQTTCONNECT` sobre sesion viva tambien reinicia el
modulo. Soft-fail ahora solo pausa PUB 60 s (sin DISC/CONNECT).
OTA ya no fuerza `uartDbg` ON.

**0.2.109 — `*ATREADY` invisible en sesion viva (causa raiz del offline del
2026-09-29 01:19):** `cmqttLoop()` solo miraba lineas `+CMQTT*` y **descartaba**
el resto, incluido el `*ATREADY` del reboot espontaneo del modulo. El cliente
MQTT del A7672 quedaba muerto con `cmqttBrokerUp` en true, cada PUB posterior
contaba como soft-fail, y el cooldown de 0.2.108 dejaba el publish en pausa para
siempre sin reconectar nunca: la unica salida era el watchdog de silencio (6 min
→ `ESP.restart()`), y ese reboot encontraba el servicio CMQTT viejo, mandaba
`CMQTTSTOP` y reiniciaba tambien el modem. Repetido, eso dejo la radio colgada.

Tres cambios: (1) `cmqttLoop()` detecta `*ATREADY` (`textHasAtReady`, NUL-safe) y
levanta `modemRebootUrcSeen` como hace `readModemUntil()`; (2) al llegar al limite
de soft-fails se consulta `AT+CMQTTCONNECT?` (read-only): si el modulo dice que no
hay sesion se bajan **solo flags** y se reintenta `CONNECT`, si dice que sigue viva
se mantiene el cooldown — nunca `DISC`/`STOP`, nunca `CONNECT` a ciegas; (3) si
`CMQTTSTART` responde `ERROR` ("ya arrancado", tipico tras reboot del ESP32) se
adopta el servicio via `AT+CMQTTACCQ?` en vez de mandar `CMQTTSTOP`, y si el
cliente 0 sigue conectado con nuestro client id se reusa la sesion tal cual.

**0.2.110 — `DISC`/`REL`/`STOP` fuera de todos los hot paths.** Campo 0.2.109:
12 min de traza UART continua sin un solo `*ATREADY`, pero los gatillos seguian
armados en tres lugares que el producto usa todo el tiempo.

- **SMS / llamada sobre LTE.** `takeModemForVoiceSms()` mandaba `CMQTTDISC` sobre
 sesion **viva** y `releaseModemToMqtt(wasOnLte)` hacia `stopLtePdp()` →
 `REL`+`STOP`: los dos gatillos, en cada test SMS y en **cada llamada de alarma**.
 Ahora el take no manda nada (la sesion vive en el modulo y el keepalive es suyo;
 los gates de `modemUartOwnedByMqtt()` ya impedian CMQTT AT), y el release llama
 `cmqttResumeAfterUartHandover()`: descarta el frame RX a medias, y si
 `AT+CMQTTCONNECT?` dice que la sesion vive se reusa tal cual, si dice que murio
 (llamada mas larga que el keepalive, CSFB que se llevo el bearer) baja **solo
 flags** y el siguiente pase hace `CONNECT`. Si el modulo se reinicio durante la
 llamada, `modemRebootUrcSeen` manda al camino de re-init de 0.2.109.
- **Route bounce.** `bounceMqttForRouteChange()` ya no manda `DISC` en path
 nativo: solo limpia el backoff. O la LAN sirve — y entonces corre el unico
 `stopLtePdp()` legitimo, el de `maintainLteFallback()`/`serviceNetworkPaths()` —
 o se queda LTE, y entonces la sesion que iba a tirar es la que hace falta.
- **`cmqttTearDown()` pregunta antes de `DISC`.** Si el modulo dice que no hay
 sesion, se saltea el `DISC` (esa era la cadena documentada `+CMQTTDISC: 0,11` →
 `CMQTTREL ERROR` → `CMQTTSTOP` encima del boot) y va directo a `REL`/`STOP`.
- **`Unknown` es conservador en todos lados.** El adopt trataba "el modulo no
 contesta" como "no conectado" y hacia `CONNECT` a ciegas (la jugada de 0.2.107),
 mientras el soft-fail lo trataba como "no tocar". Ahora `Unknown` → camino
 `STOP` en el adopt, cooldown en el soft-fail: nunca `CONNECT` sin confirmacion.
- **`CGACT` antes de escalar.** Un `CONNECT` que falla tras `+CMQTTNONET` suele ser
 el bearer caido; se reactiva el contexto 1 con `AT+CGACT=1,1` (no toca CMQTT) en
 vez de llegar antes al `stopLtePdp()`. La falla igual cuenta: el escape hatch no
 se desarma nunca.
- **`cmqttDisconnect()` y `releaseLteMqttForModem()` borrados** (el primero ya solo
 se llamaba donde el flag estaba en false, el segundo era codigo muerto).
- **Password redactada en el log UART.** `AT+CMQTTCONNECT=...,"user","pass"` y
 `AT+CGAUTH=...` se publicaban enteros al panel (y quedaban en la tabla de
 events) con UART debug ON. Se redacta el ultimo argumento entre comillas.
 En 0.2.111 se cubrio tambien el **read** de `AT+CMQTTCONNECT?`, que devuelve
 `+CMQTTCONNECT: 0,"tcp://…",…,"user","pass"` (con `:`, no `=`); `cmqttProbeBrokerLink()`
 lo logueaba entero y filtraba el password al dump UART.

**0.2.111 — probe `cmqtt_probe` (boton "Probar DISC/QUIT (CMQTT)").** Ejecuta,
sobre LAN (MQTT por Ethernet/WiFi, nunca con MQTT vivo por LTE), la secuencia
exacta que antes reiniciaba el A7672: `CMQTTSTART` → `CMQTTACCQ` → `CMQTTCONNECT`
(anonimo, client id `cof-probe`) → `CMQTTDISC` → `CMQTTREL` → `CMQTTSTOP`, y
reporta paso a paso si aparece `*ATREADY` (reboot) en algun comando. Sirve para
confirmar en cada unidad, sin consola serial, el bug DISC/QUIT de §0.2.106/110.

**0.2.112 — fix de reporte del `cmqtt_probe` (gate de `publishMqttJson`).** El
gate `!modemUartOwnedByMqtt()` en `publishMqttJson()` bloqueaba **todo** publish
mientras la UART estaba prestada, incluso en LAN, donde el MQTT sale por
Ethernet/WiFi (`PubSubClient`) y **nunca toca la UART del modem**. En el probe de
0.2.111 eso difirio todos los pasos posteriores al `start` a la cola de 8 slots
(`kDeferredEventMax`), y al resetear el modem el ESP32 se reinicio antes de
flushear: en el panel solo quedo `start`, `end` y un burst de `CMQTTSTART ok`.
Ahora el gate solo aplica cuando `state.lteMqttTransport` (ahi el publish **es**
`CMQTTPUB` sobre la UART y si hay que bloquear); en LAN se publica en vivo.

**Hallazgo de campo (cof-test, 2026-09-29 14:51 UTC):** con 0.2.111 el probe
confirmo `CMQTTSTART ok` pero el equipo se reinicio (ESP32: el contador `T+` de
`millis()` paso de `T+39360` a `T+3164`; el dump siguiente muestra un
`initModem()` completo) antes de poder publicar que paso disparo el reset. El
culpable (¿`ACCQ`/`CONNECT`/`DISC`?) quedo sin identificar por el bug de reporte
de arriba.

**Resultado con 0.2.112 (cof-test, 2026-09-29 16:33 UTC): la hipotesis DISC/QUIT
queda DESMENTIDA en esta unidad (A7672SA-FASE, IMEI 860710055794385).** Con el
reporte en vivo, el probe corrio la secuencia completa y limpia, paso a paso:
`CMQTTSTART ok` → `CMQTTACCQ ok` → `CMQTTCONNECT ok` → `before DISC: up` →
`DISC ok +CMQTTDISC: 0,0` → `REL ok` → `STOP ok` → `no reboot (*ATREADY)`.
El dump UART lo confirma byte a byte (respuestas canonicas, `+CMQTTDISC: 0,0`,
`+CMQTTSTOP: 0`, cero `*ATREADY`, contador `T+` continuo: ni el modem ni el
ESP32 se reiniciaron). **El teardown CMQTT (DISC/REL/STOP) NO resetea este
modem.** La nota historica de §0.2.106/0.2.110 ("DISC/QUIT reinicia el A7672")
era una pista falsa o aplicaba a otra unidad/firmware: no es regla general en
este hardware. La causa real de los reboots de 0.2.106–0.2.108 queda como el
otro sospechoso: **`CMQTTCONNECT` sobre una sesion ya viva** (ver 0.2.113).

**0.2.113 — probe `cmqtt_probe` gana fase 2: re-CONNECT sobre sesion viva.**
Tras la fase 1 (DISC/QUIT, ya probada limpia), el probe vuelve a `CMQTTSTART` →
`CMQTTACCQ` → `CMQTTCONNECT` #1 y luego emite **un segundo `CMQTTCONNECT` sobre
la sesion recien conectada** (el patron exacto de 0.2.106/0.2.108, donde se
conectaba sin `DISC` previo). Reporta `P2 reCONNECT ok/fail [+ *ATREADY]` y hace
cleanup (`DISC`/`REL`/`STOP`) si sobrevive. Es la confirmacion empírica del
segundo sospechoso, en la misma corrida y sobre LAN para que el resultado
sobreviva a un reboot.

**Gran descubrimiento (cof-test, 2026-09-29, fw 0.2.112/0.2.113): NI el teardown
CMQTT NI el re-CONNECT reinician el A7672SA-FASE.** Fase 1: `DISC`/`REL`/`STOP`
corren limpios de punta a punta (respuestas canonicas, cero `*ATREADY`, contador
`T+` continuo). Fase 2: el re-`CMQTTCONNECT` sobre sesion viva **no reinicia**,
responde `+CMQTTCONNECT: 0,19` = **"client is used"** (tabla de codigos de la
A76XX MQTT(S) Application Note §1.3). La hipotesis historica de 0.2.106–0.2.110
("DISC/QUIT resetea el modem") queda **desmentida**: era una pista falsa o
aplicaba a otra unidad/firmware. La causa real de los reboots de 0.2.106–0.2.108
fue otra: el modem se reiniciaba solo (CFUN/CSFB o espontaneo) y el firmware,
que no veia el `*ATREADY` por el prefijo `\0` (0.2.94), seguia mandando CMQTT
**encima del boot** (`CMQTTDISC` codigo 11 → `REL ERROR` → `STOP` sobre boot), lo
que dejaba la radio en `NO SERVICE`. O sea: los comandos CMQTT no *causaban* el
reboot; lo *agravaban* sobre un modem que ya estaba reiniciandose.

**0.2.114 — `cmqttConnect()` adopta `0,19` ("client is used") en vez de fallar.**
Con el codigo 19 identificado, el connect ya no lo trata como error: si el
modulo dice "client is used", el flag `cmqttBrokerUp` estaba stale (soft-fail que
probeo "unknown", o un `CONNLOST` transitorio que el modem recupero solo) y la
sesion esta viva; se adopta (`cmqttBrokerUp = true`) en vez de devolver false y
caminar el teardown/reconnect contra una sesion viva. Corrige ademas los
comentarios que afirmaban (mal) que DISC/STOP/CONNECT "reinician" el A7672: la
postura "probe-first / no DISC en hot path" se mantiene, pero ahora con la razon
correcta (DISC sobre cliente no conectado = `0,11` + `REL`/`STOP` ERROR, no un
reboot).

Sigue habiendo `DISC`/`REL`/`STOP`, **solo** como ultimo recurso y nunca en un
hot path: LAN que toma el relevo definitivo, 3 `CONNECT` fallidos seguidos,
`CSQ 99` sostenido, el ladder de recuperacion de radio (que resetea el modulo de
todas formas) y el borrado de credenciales.

**0.2.115 — `lockGsmForCall()` ya no cuelga la llamada en un sitio solo-LTE.** Campo
2026-09-29 21:43 UTC (`cof-test`, 0.2.114, saliendo por LTE): un `test_call` llego y
se acepto (`command_ack`), publico `Rule audio not on device, using fallback`, y a
partir de ahi **4 min de silencio total** (sin telemetria ni eventos). A las 21:47:31
el dump UART muestra el modem reiniciado (`AT`/`ATE0`/`ATI`/`AT+CPIN?` = `initModem()`
completo) y en `+CPSI: NO SERVICE,Online` con **`+CNMP: 13`**. La llamada nunca se
marco: no hay un solo `ATD` en el trace.

La huella `+CNMP: 13` es `lockGsmForCall()` ([`sms_voice.cpp`](../firmware/src/sms_voice.cpp)),
que corria **incondicional** cuando el primer dial no completaba:
`AT+CNMP=13` (GSM-only) → `waitForRadioService(45 s, true)` + `waitUntilModemReady(30 s)`.
**El sitio no tiene 2G usable** (radio LTE Band 2/Band 28, CSQ 31), asi que el lock
dejaba la radio en `NO SERVICE`, quemaba 75 s bloqueantes en el loop cooperativo
(sin telemetria ni watchdog de MQTT) y el modem reiniciaba con `CNMP` todavia en 13.
`restoreAutoRadio()` solo restauraba `CNMP=2` si `forcedGsmForCall` seguia en RAM, asi
que un reboot en medio del lock dejaba la radio en GSM-only/NO SERVICE.

**Dato que cerro el diagnostico (usuario):** saliendo por **Ethernet la llamada sale
perfecta**; solo falla por LTE, con la misma senal y el mismo firmware. No es la radio
ni el dial: es **que camino de retry se elige al fallar el primer intento**. Por
Ethernet el primer CSFB completa y el retry no corre; por LTE el primer intento no
completa a tiempo y escalaba al GSM-lock sin 2G. Agravante: `persistSkipGsm(true)`
**no tenia ningun caller** (el unico uso era `persistSkipGsm(false)` en
`bounceRadioForCsfb()`), o sea la unica proteccion contra el lock existia pero nunca
se activaba.

Cambios en 0.2.115:

- **`gsmAccessPlausible()`** (nuevo, [`modem_at.cpp`](../firmware/src/modem_at.cpp)):
  escanea con `AT+COPS=?` y acepta el lock solo si algun operador anuncia GSM/2G
  (bit 2 de la mascara de ACT). Un `observedVoicePath` previo `"gsm"` evita el scan;
  el veredicto se cachea por boot. Un scan que no contesta **no** bloquea (unknown ≠ no).
- **`lockGsmForCall()` devuelve `bool` y se gatea**: si no hay 2G, no toca el radio y
  sale con `false` (el caller termina con el resultado del primer intento). Si lockea,
  exige que `waitForRadioService(45 s, true)` devuelva servicio **antes** de gastar el
  segundo wait; si no aparece GSM, hace `restoreAutoRadio()` y sale.
- **Camino de retry** ([`sms_voice.cpp`](../firmware/src/sms_voice.cpp)): no corre el
  `bounceRadioForCsfb()` de la rama `else if` cuando el lock no tomo, asi un sitio
  solo-LTE no paga `bounce + lock + bounce` por una sola llamada. El resultado se
  anota con `(no 2G here, GSM lock skipped)` para que el motivo se vea en el panel.
- **`configureCellularApn()` fuerza `AT+CNMP=2`** y limpia `forcedGsmForCall`, asi un
  reboot (del ESP32 o del modulo) durante el lock no deja la radio en GSM-only.
  `restoreAutoRadio()` ademas pregunta `CNMP` real (`state.cnmp`) en vez de confiar
  solo en el flag en RAM.
- **Instrumentacion:** `waitForRadioService(gsmOnly)` loguea `radio`/`csq` al expirar,
  y `lockGsmForCall()` registra el motivo (`GSM lock skipped: no 2G in COPS scan` /
  `GSM lock timed out, restoring CNMP=2`) via `appendModemLogForced`, que viaja en el
  evento final. El silencio del 2026-09-29 no se puede repetir sin dejar rastro.

**Pendiente de validar en hardware:** `test_call` en `cof-test` solo-LTE (Ethernet
desenchufado) no debe producir silencio > 20 s ni reboot del modem, debe publicar el
motivo; y con Ethernet debe seguir andando perfecto (sin regresion).

**0.2.116 — sacar el lock 2G: siempre LTE/CSFB + abortar rapido en reboot.** Campo
2026-09-29 (cof-test, 0.2.115, LTE **y** Ethernet): el `ATD` devolvia `+CLCC dialing`
y a los ~12-15 s el modem se reiniciaba solo (`\0` + `*ATREADY`) — el handoff CSFB
no tiene target alcanzable en este sitio (IMS `ims_reg=0`; 2G anunciado en `COPS=?`
pero `CNMP=13` → `NO SERVICE`). No es el audio: el `Rule audio not on device, using
fallback` es normal (usa `cof_fallback.wav`), y nunca se llega al `CCMXPLAY` porque
el modem crashea antes de conectar.

Cambios en 0.2.116:

- **No mas lock GSM:** se elimina `lockGsmForCall()` y `gsmAccessPlausible()` (el
  scan `COPS=?` de 60 s que ademas mentia con torres lejanas). 2G nunca anduvo en
  Claro AR (`claro-ar.md`, 0.2.39); el camino de voz es **siempre LTE/CSFB**
  (bounce `CFUN=4/1` + un `ATD`), sin escaladas de radio en el retry. Un `test_call`
  fallido termina con el resultado del primer intento, rapido y sin tocar el radio.
- **Abortar en reboot:** `conductOutgoingCall()` ahora vuelve inmediatamente con
  `Call not connected (modem reboot)` si `modemRebootUrcSeen` se activa durante la
  llamada, en vez de esperar el timeout de 120 s. Una llamada fallida pasa de
  ~4 min + reboot-loop a ~12-15 s y modem sano.

**Pendiente (raiz):** el ciclo ya no cuelga ni lockea 2G, pero el modem **sigue
crasheando en el CSFB** si no hay target CS. La voz solo vuelve con VoLTE/IMS (que
en Claro AR no registra) o con un target 2G/3G anclable en el sitio. Queda por
verificar en el manual `A76XX` el rango de `AT+CEVDP`/`AT+CEMODE` (si `CEVDP=3`
obliga "IMS only" en vez de "CS preferred", es candidato a causa del crash) y
probar `CEVDP=0/1` + `CEMODE=0` (CS-only).

**0.2.118 — bisect CSFB cerrado: la falla es el entorno, no el firmware; IMS/VoLTE
investigado.** Se reconstruyo el binario 0.2.39 (publicado como 0.2.117) y el
`test_call` en `cof-test` dio un resultado distinto al de 0.2.115/116, que separa
los dos problemas que veniamos mezclando:

- **La llamada no conecta (entorno, no codigo).** El 0.2.39 marco (`ATD`), bajo
  el TTS (`audio_url`, no el `call_audio` por regla), y a los ~40 s recibio
  `+CLCC: 1,0,6` (desconexion limpia, sin ring). El **mismo binario 0.2.39** que
  el 06-09 estaba documentado con ringing + audio (`claro-ar.md`) hoy no llega a
  ring ⇒ el target CSFB de 2G se cayo del sitio. Sin 2G (CSFB) + sin VoLTE
  (`ims_reg=0`) + sin 3G (A7672SA-FASE no tiene WCDMA) **no queda camino de voz**.
  Ninguna version de firmware arregla esto.

- **El modem crashea al marcar (regresion de firmware).** Solo 0.2.115/116
  (`*ATREADY` ~12-15 s tras `ATD`); 0.2.39 marco y obtuvo `CLCC 6` limpio, sin
  crash. Candidato: la sesion CMQTT/PDP nativa (desde 0.2.79) + teardown CSFB.
  Arreglar esto evita el crash pero **no** hace conectar la llamada.

**No es el AMR/VPS.** El 0.2.39 bajo el TTS bien; el fallo es en el radio (`CLCC 6`
antes de ring), antes de cualquier `CCMXPLAY`. Los cambios de audio por regla del
23-09 (`dfa75ef`, `74456ee`, `ab68306`, `659818c`, `7e100f1`) corren **despues**
de que la llamada conecta.

**IMS/VoLTE (`ims_reg=0`):** el A7672 (ASR1603) **si soporta VoLTE** (pagina de
SIMCom lista `VoLTE` en funciones), pero el manual `A76XX` V1.12 que tenemos no
documenta `AT+CAVIMS`/`AT+CIREG`/`AT+CEMODE`/`AT+CEVDP` (son comandos ASR1603, de
un manual V2.x). El firmware ya configura lo correcto (`CAVIMS=1`, `CEMODE=1`,
`CEVDP=3`, `CIREG=2`, `CGDCONT=2,"IPV4V6","ims"`). El registro no ocurre por
razones de **operador/vendor**, no de codigo:

1. **Pack VoLTE en la linea (SIM).** Claro AR exige la funcionalidad
   `Funcionalidad VoLTE` activa en la linea (se pide gratis por Mi Claro). Sin
   ella, IMS no registra.
2. **Whitelist de equipo.** "activo en todo dispositivo comercializado por Claro
   desde 2019" ⇒ Claro habilita VoLTE en equipos vendidos por ellos; el A7672 es
   un modulo IoT, su IMEI no esta whitelisted para VoLTE.
3. **Perfil IMS/MBN del operador en el modulo.** En ASR1603 el VoLTE es
   MBN/XML-based; el firmware del A7672 debe traer el perfil IMS de Claro AR, y
   los modulos Cat1 LatAm normalmente no lo traen.

**Camino de voz en este hardware+operador = dead end.** Las salidas son de
hardware/operador: (a) modem con 3G/WCDMA para CSFB a 3G (Claro mantiene 3G mas
tiempo que 2G); (b) lograr VoLTE (Pack VoLTE en el SIM + whitelist del IMEI +
perfil IMS de Claro en el modulo — poco probable para IoT); o (c) aceptar voz solo
2G donde aun haya 2G (menguante).

**Giro 2026-09-30: VoLTE SI quedó activo en la línea.** El usuario llamó a Claro
(*611) con el IMEI y activaron `Funcionalidad VoLTE` en la línea. Con eso el módem
reporta `+CIREG: 2,1,15` (registrado + capacidades IMS `0xF` = voz MMTEL + SMS).
La llamada de prueba sale por IMS **sin** rebote CS (`Preparing CS radio` ya no
aparece en el `test_call`), así que el PDP/CMQTT nativo no se toca. Desmiente la
conclusión "dead end" de arriba: era falta de activación en la línea, no whitelist
de IMEI ni perfil MBN.

**0.2.122 — parser de `+CIREG` leía `ext_info` en vez de `reg_info`.** Según
3GPP TS 27.007 §8.71, `AT+CIREG?` devuelve `+CIREG: <n>,<reg_info>[,<ext_info>]`;
`reg_info` (2º campo) es el flag de registro (`1` = registrado) y `ext_info` es la
máscara hex de capacidades que **solo aparece cuando ya está registrado**. El parser
hacía `lastIndexOf(',')` y se quedaba con `"15"` (ext_info) en vez de `"1"`, así que
`imsVoiceReady()` (`state.imsReg == 1`) nunca daba true pese al registro. Fix en
[`modem_at.cpp`](../firmware/src/modem_at.cpp): tomar el 2º campo.

**0.2.123 — SMS: falso "SMS sent" + `CGSMS` mal puesto.** Dos hallazgos en el envío
MO sobre LTE:

- `transmitSms()` ([`sms_voice.cpp`](../firmware/src/sms_voice.cpp)) solo miraba la
  *ausencia* de `+CMGS`/`OK` para fallar. El dump mostraba
  `SMS rsp ... +CMGS: 70 | +CMS ERROR: unknown error | +CGEV: ME PDN DEACT 1` y aun
  así devolvía `SMS sent` (y el `readModemUntil(60000,"OK")` agotaba el timeout sin
  `OK`). Ahora `+CMS ERROR`/`+CME ERROR` se tratan como falla antes de evaluar éxito,
  lo que además activa el retry de `sendTestSms()`.
- `AT+CGSMS=1` en el manual A76XX §9.2.10 es **"circuit switched"** (mapeado a 3 =
  CS preferred), no "SMS sobre LTE NAS/IMS" como daba por sentado el código. En un
  sitio solo-LTE eso forzaba un intento CS por 2G que fallaba con
  `+CMS ERROR: unknown error` y desactivaba el PDP de datos. Se pasó a `CGSMS=2`
  ("GPRS preferred" = SMS sobre PS/NAS) en `configureCellularApn()` y
  `restorePacketServices()`.

**0.2.124 — `CGSMS=2` NO bastó: el SMS seguía por CS (2G). `CSMS=1` + probe.** El
re-test en `cof-test` (0.2.123, 21:23) siguió fallando igual:
`SMS rsp ... +CGEV: ME PDN DEACT 1 | +CMGS: 72 | +CMS ERROR: unknown error`. La
clave es el `+CGEV: ME PDN DEACT 1` = el módem **desactiva el PDP de datos** al
enviar el SMS → está haciendo **CSFB a 2G** para el SMS, no SMS sobre PS/IMS. Con
2G caído del sitio, `+CMS ERROR` y no llega el mensaje.

Por qué `CGSMS=2` no alcanza: `CGSMS` (manual §9.2.10) solo elige **CS vs GPRS/PS**;
el SMS sobre PS requiere además **`AT+CSMS=1`** (Phase 2+, manual §9.2.1), que el
firmware **nunca seteaba** (queda en Phase 2 = solo CS). Se agregó `CSMS=1` antes de
`CGSMS=2` en `configureCellularApn()` y `restorePacketServices()`.

El otro dato: `+CIREG: 2,1,15` con `ext_info=15` = **0xF** = bits 1 (MMTEL voz) + 2
(texto) + 4 (**SMS using IMS functionality**, SMSoIP) + 8 (video) — o sea Claro
**sí anuncia SMSoIP**. Si `CSMS=1` no alcanza (SGs no disponible en la red), el
camino correcto con VoLTE activo es **SMS over IMS (SMSoIP)**, que es automático
cuando el módem registra con `+g.3gpp.smsip`; no hay comando AT dedicado para
forzarlo.

**0.2.125 — la causa real era `CEMODE=1` (combined attach), no `CSMS`.** El re-test
a las 22:03 siguió en **0.2.123** (el OTA de 0.2.124 nunca se aplicó en el device),
y el dump repite `+CMGS: 74 | +CMS ERROR: unknown error | +CGEV: ME PDN DEACT 1`
(×3). `AT+CEMODE` (3GPP TS 27.007 §10.1.28) es **"UE modes of operation for EPS"**:
`0`=PS mode 2, `1`=**CS/PS mode 1** (combined attach = CSFB + SMS-over-SGs), `2`=CS/PS
mode 2, `3`=**PS mode 1** (EPS-only, voice-centric). El firmware seteaba `CEMODE=1`,
o sea **combined attach** con CSFB habilitado; por eso cada MO SMS hacía CSFB (soltaba
el PDP de datos, `+CGEV: ME PDN DEACT 1`) para bajar a 2G, que no existe en el sitio.
`CEMODE=3` (PS mode 1) fuerza voz **y** SMS por IMS (VoLTE/SMSoIP) sin dominio CS:
es el modo correcto para operar "todo IMS". `CSMS=1` + `CGSMS=2` quedan (no molestan),
pero el arreglo es `CEMODE=3`. El probe ahora agrega `CEMODE?`/`CEMODE=?`/`CGPADDR?`
para confirmar el modo y que el PDP IMS (CID 2) tenga IP.

**0.2.126 — `CEMODE=3` correcto pero insuficiente: el PDP IMS (CID 2) nunca se
activaba, y `CEMODE` fijo rompía los sitios 2G.** El re-test en 0.2.125 (22:28) con
VoLTE activo dio `+CREG: 0,0` (CS apagado, esperado con PS mode 1) pero el SMS
**seguía** fallando con `+CMS ERROR: unknown error`. Diagnóstico: hay **tres**
caminos de SMS y el firmware no dejaba vivo ninguno.

| Escenario | CS | PS (CID 1) | IMS (CID 2) | Antes de 0.2.126 |
|---|---|---|---|---|
| Sitio 2G / CSFB | CS off (CEMODE=3) | — | nunca activado | **roto** por el `CEMODE=3` fijo |
| LTE sin Ethernet (CMQTT nativo) | CS off | activo (CMQTTSTART) | nunca activado | SMS por PS, pero CID 2 sin levantar |
| LTE + Ethernet (este sitio, `cof-test`) | CS off | **inactivo** (`"lte":{"up":false}`) | nunca activado | **sin bearer** -> `+CMS ERROR` |

El `AT+CGDCONT=2,"IPV4V6","ims"` se definía desde siempre pero **nunca** se activaba
con `AT+CGACT=1,2`, así que con MQTT por Ethernet (CID 1 idle) el IMS no tenía IP.
Cambios de 0.2.126:

- `ensureImsPdp()` (`lte_pdp.cpp`): si CID 2 no tiene IP, `CGDCONT`+`CGACT=1,2` y
  espera `+CGPADDR=2` != `0.0.0.0`. Se llama antes del primer `CMGS` y en el
  reintento de `sendTestSms()`.
- `applyAdaptiveCemode()` (`modem_at.cpp`): **el `CEMODE` sigue al sitio, no es fijo.**
  Con IMS registrado (`imsVoiceReady()`) mantiene `CEMODE=3` (todo IMS); sin IMS baja
  a `CEMODE=1` (combined attach) para no matar el SMS/CSFB de los sitios 2G. Se
  re-evalúa en `refreshCellularStatus()` y `restorePacketServices()`.
- Probe: `CGPADDR=2` y `CGPADDR=1` por CID, para confirmar qué bearer tiene IP.

Pendiente de campo: confirmar que con CID 2 arriba el `+CMGS` sale por SMSoIP en
`cof-test`, y que un sitio sin IMS queda en `CEMODE=1` y sigue mandando por CS.

**0.2.127 — 0.2.126 quedó desmentido por el campo: SMSoIP no está provisionado y el
bearer IMS real es CID 8, no CID 2.** El probe de 0.2.126 en `cof-test` mostró:

- IMS registrado `+CIREG: 2,1,15` (ext_info=0x15 = voz+SMS+video).
- El IMS bearer real es **CID 8**, auto-creado por el módem y **ya activo**:
  `+CGDCONT: 8,"IPV4V6","IMS","254.128.0.0...81.203.207.201.1",0,0,0,2,1,1` y `+CGACT: 8,1`.
  Nuestro `CGDCONT=2,"ims"` era un duplicado muerto.
- `ensureImsPdp()` activaba CID 2: `AT+CGACT=1,2` -> `+CME ERROR: unknown error` +
  `+CGEV: ME PDN DEACT 2` + `+CGEV: NW REATTACH` (**dañino: desestabilizaba antes del SMS**).
- Con IMS arriba, `AT+CMGS` -> `+CMS ERROR: Network timeout` (60 s). El A7672 **no
  rutea MO SMS por IMS**; Claro no provisiona SMSoIP para este IMEI IoT (igual que
  VoLTE requirió alta en línea).

Conclusión: MO SMS en este módem sale por **CS/SGs** (combined attach, `CEMODE=1`), y
la voz por **VoLTE** (`CEMODE=3`). Son excluyentes, así que el firmware conmuta por
operación. Cambios de 0.2.127:

- Revertido `ensureImsPdp()` (CID 2 fantasma).
- `enableCsSmsTransport()`: `CEMODE=1` + `CEVDP=1`, espera `csAttached()` (CREG
  registrado) antes del `CMGS`.
- `restoreImsMode()`: devuelve `CEMODE=3`+`CEVDP=3`+`CAVIMS=1` si hay IMS (o `CEMODE=1`
  en sitio 2G) al terminar el SMS, para que la voz siga por VoLTE.
- `applyAdaptiveCemode()` respeta un override mientras el SMS fuerza CS.
- Probe: `CGPADDR8` (bearer IMS real) en vez de `CGPADDR2`, y reporta `cs_attached`.

Pendiente de campo: probar SMS (debe salir por SGs con `CEMODE=1` transitorio) y
llamada (debe seguir por VoLTE). Si el SMS por SGs también falla en cof-test (LTE
sin 2G y sin SGs en la MME), el siguiente paso es pedir a Claro el alta de
SMS-over-IMS en la línea, no más firmware.

**0.2.128 — la llamada VoLTE se bloqueaba en `isCallReady()`: exigía `csAttached()`
(`+CREG` stat 1/5/9/10), que en un sitio solo-VoLTE (`CEMODE=3`) es `+CREG: 0,0`.** El
re-test en `cof-test` (23:49) mostró IMS arriba (`+CIREG: 2,1,15`) y EPS registrado
(`+CEREG: 0,1`), pero `waitUntilModemReady(true)` agotaba los 25 s y la llamada nunca
marcaba ("Call not ready", sin `ATD`). La voz tiene dos transportes independientes:
CS (CSFB/2G) o IMS (VoLTE); `isCallReady()` ahora acepta `csAttached() || imsVoiceReady()`.
Los sitios CSFB legacy no cambian (`imsVoiceReady()` es falso ahí).

**0.2.128 — SMS: sale por Ethernet, falla por LTE. La causa es que IMS no se suelta
cuando el data PDP (CID 1) está activo.** En cof-test el primer SMS tras el OTA
(00:01:15Z, MQTT por Ethernet) salió por **CS/SGs**, no por IMS: `CEMODE=1`+`CEVDP=1`
provocó `+CGEV: NW PDN DEACT 1`, el IMS cayó a `+CIREG: 2,0,0`, `CREG` pasó a `0,1`
y el `CMGS` respondió `OK`. Después de que el MQTT subió a LTE nativo/CMQTT
(00:02:24Z "LTE MQTT OK"), los SMS de 00:04:52Z y 00:17:33Z fallaron con
`+CMS ERROR: unknown error` (60 s): con CID 1 activo la red NO desactiva el PDP,
el módem conserva `+CIREG: 2,1,15` aun con `CEMODE=1`, y el `CMGS` se rutea por IMS
(SMSoIP no provisionado). Ver `docs/voice/operators/claro-ar.md`. Salida limpia:
alta SMSoIP en Claro; workaround firmware: bajar IMS (`AT+CGACT=0,1`) antes del `CMGS`.

**0.2.129 — SMS: SMSoIP primero (10 s), fallback CS/SGs con drop de IMS.** Tras
revalidar Ethernet (SMS OK), el fix LTE es: si `imsVoiceReady()`, probar `CMGS` con
tope 10 s + early `ERROR`; si falla, `dropImsForSms()` (`CGACT=0,8` + `CAVIMS=0`,
espera `!imsVoiceReady` ~15 s); si IMS no baja → `SMS failed: IMS still up`; si baja,
`enableCsSmsTransport()` + `CMGS` por CS/SGs; al final `restoreImsMode()` re-arma
VoLTE. Sin IMS al inicio, directo a CS/SGs (sitios 2G/CSFB). No toca el path de voz.

**Campo (cof-test, 0.2.129):** confirmado por el usuario — **llamada OK por Ethernet
y por LTE**; **SMS OK por Ethernet y por LTE**. El path de voz observado es VoLTE;
el de SMS es CS/SGs (SMSoIP sigue sin provisionar en esta línea, el probe falla en
≤10 s y el fallback manda el SMS).

**0.2.130 — badge de transporte en call/SMS.** El evento MQTT lleva `payload.transport`
(`volte`/`csfb`/`gsm`/`smsoip`/`sgs`/`cs`) y el panel muestra el badge (VoLTE, CSFB,
2G, SMSoIP, SGs, CS) en lugar del genérico "ok". SMS exitoso publica
`SMS sent [smsoip|sgs|gsm]`.

---

## P0 — Pipeline de OTA

Tres agujeros encontrados el 2026-09-21 al publicar 0.2.60. El device no tenia
forma de saber que estaba desactualizado durante **cinco releases** (0.2.55 a
0.2.59). El §0 de abajo es del 2026-09-23 y agrega un cuarto, mas de fondo.

### 0. Un equipo solo-LTE nunca se puede actualizar (hallazgo 2026-09-23)

**CONFIRMADO EN HARDWARE el 2026-09-23.** `cof-test` saliendo por LTE: el OTA desde
el panel devolvio `ota_check: accepted` y el equipo **siguio en 0.2.70** con el
manifest anunciando 0.2.72. El servidor estaba bien (el binario del VPS tenia el
sha256 correcto); el corte es del lado del equipo.

`checkManifest()` lee el manifest con `httpGetString()`, que arranca asi:

```c
bool httpGetString(const String& url, String& out, uint32_t timeoutMs) {
  if (!lanConnected()) {          // estado: ethernetConnected || wifiConnected
    return false;
  }
```

`lanConnected()` es Ethernet o WiFi **solamente**: no cuenta `lteDataUp`. Y
`checkManifest()` es quien decide si hay version nueva. Consecuencia: en un sitio
solo-LTE el manifest **nunca se lee**, el equipo nunca ve una version nueva y
**jamas se actualiza solo**. Desde 0.2.97 el OLED dice `OTA needs LAN` (no
`Manifest fail`) para no parecer un fallo; el panel sigue bloqueando el boton.

Es la misma raiz que §8c (el audio y el OTA necesitan `HTTPClient`, que necesita
lwIP), pero aca el sintoma es mas grave porque no depende de una descarga fallida:
ni siquiera se intenta. Y como `performOta()` usa `networkConnected()` (que **si**
cuenta LTE), la asimetria es accidental, no deliberada: el OTA se negaria en
`httpGetString` mucho antes de llegar a `performOta`.

**Mitigado en el panel (commit `53b5407`).** El boton ya no publica a ciegas:
`device_ota_block_reason()` en `backend/app/main.py` rechaza antes de enviar y
avisa por que. El boton queda deshabilitado con la razon en el tooltip y una alerta
debajo, asi que ya no se puede creer que el OTA funciono cuando no puede. Sigue
siendo una mitigacion, **no un arreglo**: el equipo sigue sin poder actualizarse
solo.

**Impacto directo en el trabajo en curso:** esto es lo que hace que B tenga un
bootstrap de una sola vez. El firmware que implementa la via HTTP nativa del
modem solo puede llegar a un equipo que ya tenga LAN - que es justo el escenario
que B viene a resolver. Unico camino: LAN (o flasheo a mano) **una vez**, y a
partir de ahi B abre el OTA por LTE.

**Como cerrarlo:** darle al manifest una via que no requiera lwIP, que es el mismo
trabajo de §8c (`AT+HTTPINIT` -> `AT+HTTPPARA="URL"` -> `AT+HTTPACTION`, y leer el
cuerpo). `COF_MANIFEST_URL` ya apunta al VPS (`/ota/manifest.json`, mismo origen
que el bin); la via del modem solo tiene que alcanzar `app.callonfail.com.ar`.
Ver §8c y la prueba end-to-end del probe en 0.2.69.

### 1. El VPS nunca se sincroniza solo (causa raiz)

`scripts/release-fw.py` compila, actualiza `ota/manifest.json` y pushea a
GitHub. Pero el binario lo sirve Flask desde el **checkout del VPS**
(`./ota:/srv/ota:ro`, ver `docs/ops/VPS_CONFIG.md`), y **nada** corre `git pull`
ahi. El manifest anunciaba `0.2.59` mientras el VPS servia `0.2.57`; el gate de
sha256 rechazaba el update en silencio.

Opciones (elegir una):

- **a)** `manifest.url` deja de apuntar al VPS y apunta a un CDN (raw GitHub o
  R2/S3). Elimina la dependencia del pull, pero suma latencia de CDN.
- **b)** El script falla si el sha256 servido no coincide con el local. Requiere
  un endpoint publico en el backend que devuelva el sha256 de `ota/firmware.bin`
  (no hace falta SSH).
- **c)** Cron/systemd timer en el VPS: `git pull` periodico + aviso si cambia.

Mientras tanto: **`cd /opt/callonfail && git pull` en el VPS antes de cada OTA.**

### 3. Nadie verifica que el device haya actualizado

El gate de sha256 protege contra firmware corrupto, pero rechaza **en silencio**
(`OTA bad hash`). No hay alarma de "OTA rechazada" ni de "version estancada".

Fix: (a) el firmware publica un evento `ota_rejected` con el motivo; (b) el
backend avisa si un `ota_check` fue `accepted` y la version reportada no cambio
en N minutos.

---

## P1 — Firmware

### 4. Sondeo de SMS entrante pausado bajo LTE

`pollIncomingSms()` tiene gate `!lteMqttTransport`
(`firmware/src/main.cpp:719`, comentado en `firmware/src/sms_voice.cpp:140`).
Es **deliberado**: intercalar `sendAT` con un `AT+CIPOPEN` abierto puede
corromper el socket del modem. El SMS **saliente** (la prueba manual) funciona
desde 0.2.55.

Decidir: dejar como limitacion documentada, o drenar SMS cerrando el CIPOPEN
antes del housekeeping AT y reabriendo despues.

### 5. TLS no verificado en las descargas del device

`client.setInsecure()` en `ota_config.cpp:223` y `:260` (manifest y firmware),
`sms_voice.cpp:172` (audio), `mqtt_io.cpp:605` (MQTT sobre LTE). El sha256 cubre
integridad, **no autenticidad del transporte**. Fix: pinear la cadena de Let's
Encrypt (ISRG Root X1). Ya anotado como "Pending" en
`.cursor/rules/20-firmware.mdc`.
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

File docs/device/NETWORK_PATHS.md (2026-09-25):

# Network paths: Ethernet, WiFi and LTE

The device has three ways to reach the MQTT broker. This document describes how
one is chosen and, more importantly, how a path that *looks* fine but carries no
internet is detected.

The path selection, the probes and the broker address resolution all live in
`firmware/src/net_paths.cpp` (see the module map in `.cursor/rules/20-firmware.mdc`).

## Priority

Ethernet > WiFi > LTE. The decision is spread over three places, all with the
same order:

| Where | Purpose |
|---|---|
| `applyPreferredRoute()` | sets the lwIP default route (raw TCP clients) |
| `configureMqttClientTransport()` | picks the MQTT client (TLS/plain vs. AT socket) |
| `activeNetworkName()` / `mqttPathLetter()` | what gets reported to the backend |

LTE is a special case: it is a raw `AT+CIPOPEN`/`CAOPEN` socket (`LteMqttClient`),
not an lwIP interface, so the default route is irrelevant while MQTT rides it.

### LTE MQTT: verified on hardware since 0.2.70

Verified 2026-09-23 with the Ethernet cable unplugged: the `handshake` field of
the `lte_data` event carries a full, ACKed session end to end.

```text
open mqtt.callonfail.com.ar:1883 netopen
CIPOPEN ok 54.207.204.86
CIPSEND 135 -> | OK  |   | +CIPSEND: 0,135,135     <- CONNECT
mqtt connected ok                                   <- CONNACK
CIPSEND 38  -> | OK  |   | +CIPSEND: 0,38,38        <- subscribe config/desired
CIPSEND 31  -> | OK  |   | +CIPSEND: 0,31,31        <- subscribe command
CIPSEND 1024 -> | OK  |   | +CIPSEND: 0,1024,1024   <- publish
CIPSEND 382  -> | OK  |   | +CIPSEND: 0,382,382
CIPSEND 1024 -> | OK  |   | +CIPSEND: 0,1024,1024
CIPSEND 78   -> | OK  |   | +CIPSEND: 0,78,78
```

#### Why it had never worked: AT reentrancy during the send

Before 0.2.70 the session died right after the CONNACK. The 0.2.67 capture (the
one that made this diagnosable) ended like this:

```text
CIPSEND 135 -> | OK  |   | +CIPSEND: 0,135,135
mqtt connected ok
no '>' prompt for CIPSEND            <- the subscribe, not the CONNECT
```

The CONNECT was sent, ACKed and answered - so the failure was never DNS, APN, the
cached broker IP or the shape of the `AT+CIPSEND` ACK. It was **reentrancy on the
modem UART**: `LteMqttClient::write()` waits for the `>` prompt and then for the
`+CIPSEND:` ACK inside `readModemUntil()`, and that same loop pumps
`mqttClient.loop()`. `loop()` calls `available()`, which on an empty RX buffer
issues its own `AT+CIPRXGET` (see `recvChunk()`). That command landed inside the
`AT+CIPSEND` exchange, stole the prompt or the ACK, the wait timed out and the
socket was dropped.

The asymmetry with `state.mqttConnected` is what made the CONNECT succeed and the
next send fail: the flag is raised only *after* `connect()` returns, so nothing
pumped during the CONNECT's send and the first `subscribe` was the first send to
race the pump.

The fix is the `atCommandBusy` guard: `write()` owns the line from the prompt to
the ACK, `available()` emits no AT while it is set, and `readModemUntil()` does
not pump (`loop()` can also emit a PINGREQ, which is a write too). Any future
change to `write()` or `available()` has to preserve that invariant - the pump
must never talk to the module mid-send.

`stopLtePdp()` teardown is stack-exclusive since 0.2.65. It used to run both
branches whenever `state.lteDataUp` was set, which under NETOPEN (where the CID is
1) also sent `AT+CNACT=1,0` - but the CNACT context is always 0, so the module
answered `ERROR`. That was real noise in the trace, not the root cause.

#### Instrumentation worth keeping

Since 0.2.66 the client captures the HEAD of the session (the `CIPSEND` ACKs and
PubSubClient's `state=N`) into a `handshake` field published alongside the
tail-only `modem_log` in the `lte_data` event. `modemCallLog` keeps only the tail,
so in a retry loop the first attempt - the only one that carries the send ACK, the
CONNACK and PubSubClient's verdict - is always discarded; the `handshake` capture
is what preserved it and what made this bug findable at all. It clears only once
published, so a failure that never reaches a successful publish is the one that
survives.

Still true: `LteMqttClient::write()` talks to `ModemSerial` directly and does
**not** go through `sendAT()`, so its traffic never appears in the general modem
dump. That is why the trace above lives in `handshake` and not in `modem_log`.

## The rule: an interface is only "the internet" if it reaches the broker

Link up + DHCP lease is **not** evidence of internet. A router with no uplink
happily gives both. Treating that as healthy was the cause of a real outage: the
device reported Ethernet and LTE available and could not reach anything.

So each LAN interface carries an explicit health flag:

- `ethInternetUp` / `wifiInternetUp`
- Set optimistically to `true` when the interface gets its IP (keeps boot fast).
- Demoted to `false` by a real failure: a failed MQTT connect, a failed publish,
  or a failed broker probe.
- A successful MQTT connect (or probe) promotes it back to `true`.

`lanHasInternet()` is `(ethernetConnected && ethInternetUp) || (wifiConnected && wifiInternetUp)`.
`network_internet_ok` additionally counts LTE.

`lanConnected()` (link/IP only) and `lanHasInternet()` (actual reachability) are
deliberately different, and `maintainLteFallback()` uses the latter to decide
whether LTE is needed.
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

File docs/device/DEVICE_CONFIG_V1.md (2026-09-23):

# Device configuration contract v1

This document defines the first CallOnFail device configuration contract.

The backend owns the desired configuration. The device stores the latest valid
configuration locally and reports what it applied.

## MQTT topics

For a device with ID `cof-000001`:

```text
devices/cof-000001/telemetry
devices/cof-000001/event
devices/cof-000001/status
devices/cof-000001/config/desired
devices/cof-000001/config/reported
devices/cof-000001/command
devices/cof-000001/ack
```

The `device_id` must match the backend device record created in `/devices/new`.
For lab testing, the seeded/default device is:

```text
cof-test
```

Recommended QoS:

```text
telemetry          QoS 0
event              QoS 1
status             QoS 1
config/desired     QoS 1, retained
config/reported    QoS 1
command            QoS 1
ack                QoS 1
```
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

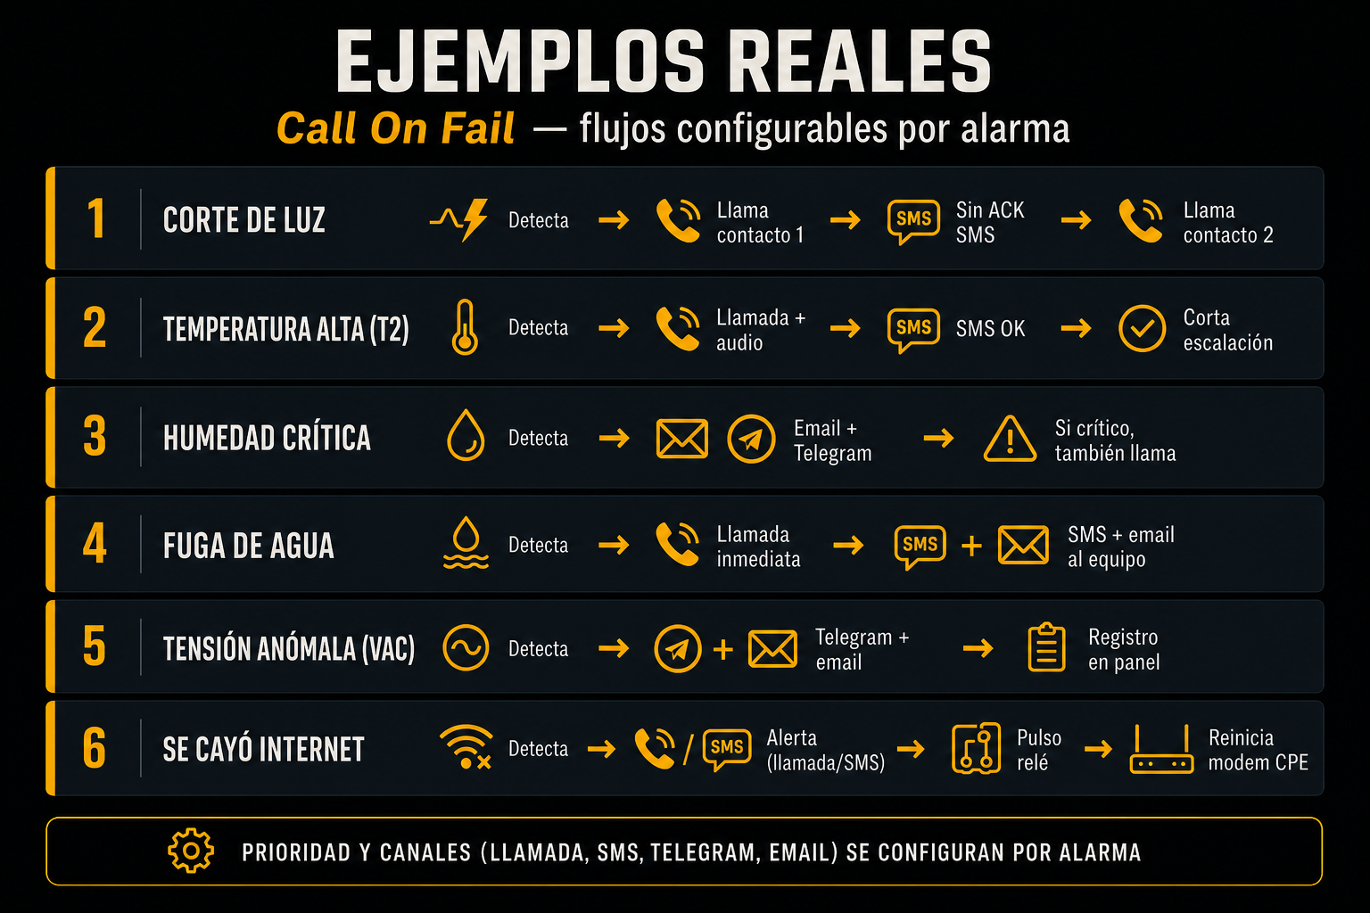
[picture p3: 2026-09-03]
web/assets/flujos-alertas.png

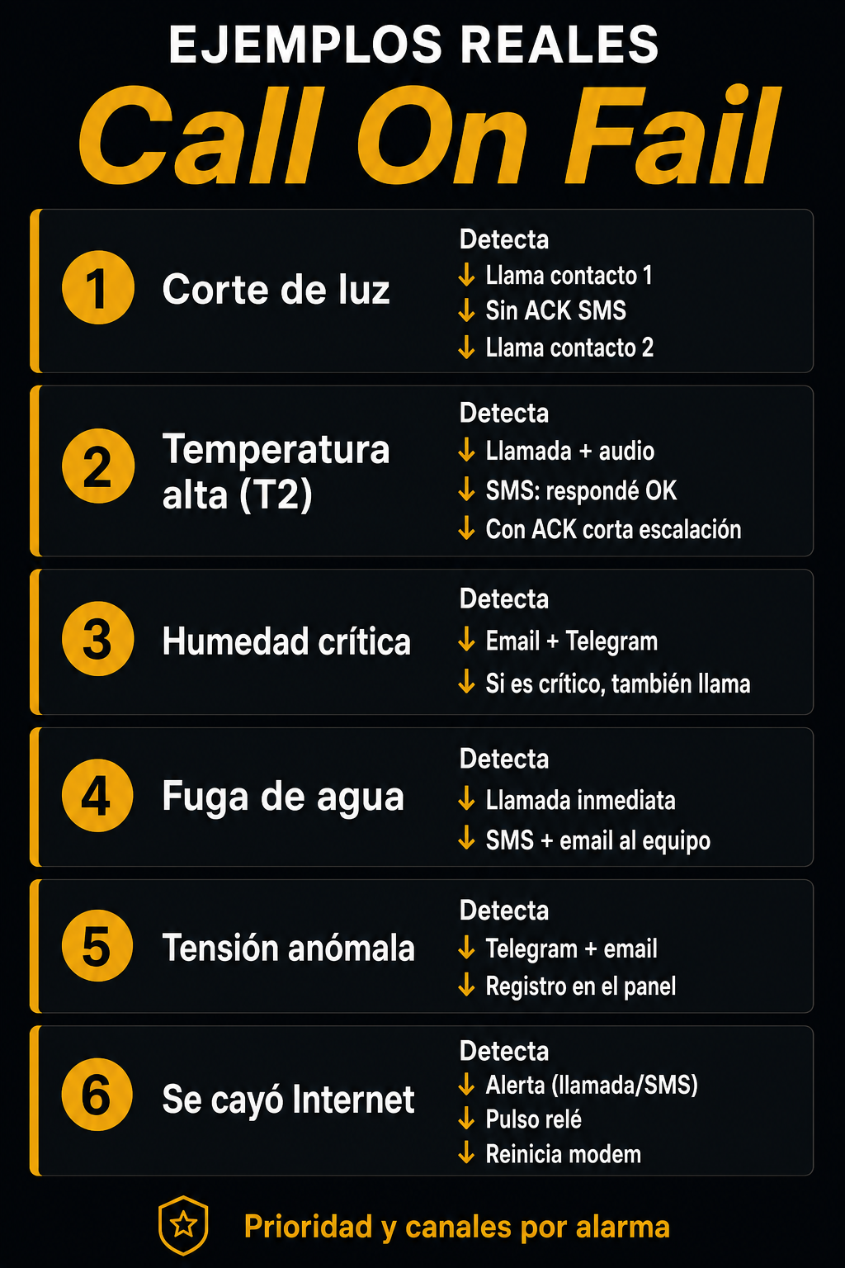
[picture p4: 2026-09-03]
web/assets/flujos-alertas-mobile.png

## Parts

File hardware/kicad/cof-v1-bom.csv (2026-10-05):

Qty | Value | Refs | Lib
1 | Campo IN1 | J3 | Connector_Generic:Conn_01x02
1 | Campo IN2 | J4 | Connector_Generic:Conn_01x02
1 | PSU 5V 5A | J1 | Connector_Generic:Conn_01x02
1 | RS485 A/B | J11 | Connector_Generic:Conn_01x02
1 | Campo OUT | J5 | Connector_Generic:Conn_01x04
1 | Enlace 5V A | J7 | Connector_Generic:Conn_01x04
1 | Enlace 5V B | J8 | Connector_Generic:Conn_01x04
1 | Panel 6 pin | J6 | Connector_Generic:Conn_01x06
1 | Enlace sig A | J9 | Connector_Generic:Conn_01x08
1 | Enlace sig B | J10 | Connector_Generic:Conn_01x08
1 | Gel 6V 7Ah NP7-6 | BT1 | Device:Battery
7 | 100n | C3 C9 C10 C11 C12 C13 C14 | Device:C
1 | 2.2uF | C18 | Device:C
1 | 1000uF/16V | C2 | Device:C_Polarized
1 | 10uF | C15 | Device:C_Polarized
1 | 2200uF/16V | C1 | Device:C_Polarized
1 | 47uF/16V | C17 | Device:C_Polarized
1 | 1N4148 | D8 | Device:D
1 | 5A 5x20 | F1 | Device:Fuse
1 | LED ALARMA | D7 | Device:LED
1 | LED GRN PWR | D2 | Device:LED
1 | LED LTE | D9 | Device:LED
1 | LED NET | D6 | Device:LED
3 | 2N3904 | Q_BZ Q_DONE Q_EN | Device:Q_NPN
1 | NDP6020P | Q1 | Device:Q_PMOS
5 | 100k | R3 R4 R9 R18 R25 | Device:R
9 | 10k | R1 R2 R10 R21 R27 R28 R29 R30 R34 | Device:R
1 | 15k | R35 | Device:R
5 | 1k | R19 R23 R32 R33 R36 | Device:R
1 | 22k | R7 | Device:R
4 | 330R | R5 R16 R17 R26 | Device:R
1 | 47k | R6 | Device:R
3 | 4k7 | R13 R14 R15 | Device:R
1 | 57.6k | R8 | Device:R
1 | A7672SA-FASE | U6 | Module:A7672
1 | XL6019 | U2 | Module:BUCKBOOST
1 | Buzzer 5V activo | LS1 | Module:BUZZER
1 | DS18B20 x4 | U9 | Module:DS18B20
1 | FT232 | U15 | Module:FT232
1 | 74HCT123 | U4 | Module:HCT123
1 | LM66200 | U14 | Module:LM66200
1 | OLED 0x3C | U7 | Module:OLED
1 | PC817 2CH | U12 | Module:PC817_2CH
1 | PCF8575 | U11 | Module:PCF8575
1 | 2-relay opto | K1 | Module:RELAY2_OPTO
1 | RS485 auto | U16 | Module:RS485
1 | SHT31 0x44 | U8 | Module:SHT31
1 | TPL5010 | U3 | Module:TPL5010
1 | Water det | U17 | Module:WATER_DET
1 | WT32-ETH01 | U5 | Module:WT32
1 | XY-SJVA 6.85V/0.6A | U1 | Module:XY_SJVA
1 | ZMPT101B | U10 | Module:ZMPT
1 | BOOT IO0 | SW_BOOT | Switch:SW_Push
1 | EN reset | SW_EN | Switch:SW_Push
1 | RESET gabinete | SW1 | Switch:SW_Push
1 | Servicio P02 | SW2 | Switch:SW_Push

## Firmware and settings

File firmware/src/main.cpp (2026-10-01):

// main.cpp -- lifecycle, sensors, display and the cooperative loop.
//
// Function bodies live in the sibling .cpp files; the globals are DEFINED here
// (declared in cof_state.h) so this file owns the shared state.

#include <Arduino.h>
#include <ArduinoJson.h>
#include <DallasTemperature.h>
#include <ETH.h>
#include <HTTPClient.h>
#include <OneWire.h>
#include <Preferences.h>
#include <PubSubClient.h>
#include <U8g2lib.h>
#include <Update.h>
#include <WiFi.h>
#include <WiFiClientSecure.h>
#include <Wire.h>
#include <Adafruit_SHT31.h>
#include <esp_arduino_version.h>
#include <esp_netif.h>
#include <esp_netif_net_stack.h>
#include <esp_ota_ops.h>
#include <esp_system.h>
#include <esp_task_wdt.h>
#include <mbedtls/sha256.h>
#include "lwip/dns.h"
#include "lwip/netif.h"

#include <cstring>
#include "cof_config.h"


#include "cof_state.h"

HardwareSerial ModemSerial(2);
WiFiClient mqttPlainClient;
WiFiClientSecure mqttTlsClient;
PubSubClient mqttClient;
U8G2_SH1106_128X64_NONAME_F_HW_I2C display(U8G2_R0, U8X8_PIN_NONE);
Adafruit_SHT31 sht31;
OneWire oneWire(COF_PIN_ONEWIRE);
DallasTemperature ds18b20(&oneWire);
Preferences preferences;
RuntimeState state;
uint32_t lastDisplayMs = 0;
uint32_t lastSensorMs = 0;
uint32_t lastModemMs = 0;
uint32_t lastSmsPollMs = 0;
uint32_t lastMqttReconnectMs = 0;
uint32_t lastMqttOkMs = 0;
uint8_t lanMqttFailCount = 0;
uint32_t wifiBackupDueMs = 0;
uint8_t wifiAuthFailCount = 0;
uint32_t lastEthProbeMs = 0;
uint8_t ethProbeFails = 0;
uint32_t lastLanReachableProbeMs = 0;
bool lanReachableLatch = false;
uint32_t noLanSinceMs = 0;
uint32_t ethernetUpAtMs = 0;
uint32_t ethernetHoldoffUntilMs = 0;
IPAddress cachedMqttIp;
IPAddress resolvedBrokerIp;
bool lteForceDnsResolve = false;
volatile bool brokerResolveDone = false;
bool brokerResolveInFlight = false;
bool brokerResolveFailed = false;
uint32_t brokerResolveStartedMs = 0;
uint32_t lastBrokerResolveMs = 0;
// Stable storage for the name being resolved: lwIP keeps this pointer for the
// whole async lookup, and state.mqttHost can be rewritten by a config apply.
String brokerResolveName;
uint32_t lastTelemetryPublishMs = 0;
uint32_t modemStableSinceMs = 0;
uint32_t lastCellularStatusMs = 0;
uint32_t lastManifestMs = 0;
bool didInitialManifestCheck = false;
bool lastButtonPressed = false;
uint32_t buttonPressedAtMs = 0;
String serialCommandBuffer;
bool pendingConfigReport = false;
bool pendingConfigApplied = false;
int pendingConfigVersion = 0;
String pendingConfigHash = "";
String pendingConfigError = "";
bool pendingOtaCommand = false;
bool pendingStatusReportCommand = false;
bool pendingModemProbeCommand = false;
String pendingModemProbeCommandId = "";
bool pendingCmqttProbeCommand = false;
String pendingCmqttProbeCommandId = "";
bool pendingTestCallCommand = false;
String pendingTestCallPhone = "";
String pendingTestCallAudioSha = "";
String pendingTestCallAudioUrl = "";
String pendingTestCallCommandId = "";
bool pendingTestCallIsAdmin = false;
bool reportTestCallProgress = false;
String pendingCallUrcs;
String pendingModemUrcs;
String modemCallLog;
bool pendingTestSmsCommand = false;
String pendingTestSmsPhone = "";
String pendingTestSmsText = "";
String pendingTestSmsCommandId = "";
bool pendingCommandAck = false;
String pendingCommandId = "";
String pendingCommandName = "";
String pendingCommandStatus = "";
String pendingCommandMessage = "";
bool pendingMqttBounce = false;
bool pendingNetworkStatusReport = false;
uint32_t lastLteAttemptMs = 0;
bool reportLteProgress = false;
bool modemUartDebug = false;
uint32_t lastModemUartDebugPublishMs = 0;
bool pendingModemUartDebugPublish = false;
String pendingModemUartDebugReason;
bool uartDebugPublishing = false;
bool lastLteFail = false;
LteIpStack lteIpStack = kLteStackUnknown;
String lteTraceLog;
String pendingLteTraceMessage;
bool pendingLteTracePublish = false;
bool pendingLteTraceOk = false;
// Path health. Optimistic when an interface gets its IP (so boot is not slowed
// down by a probe), demoted only when the broker probe actually fails.
bool ethInternetUp = false;
bool wifiInternetUp = false;
uint8_t wifiProbeFails = 0;
uint32_t lastWifiProbeMs = 0;
uint32_t lastEthRecoverProbeMs = 0;
// Ethernet is flagged down but still physically present (link up + lease), so it
// is worth probing to get the better path back. Derived from ETH.linkUp() rather
// than latched from an event, so a replug without a matching event still recovers.
bool ethRecoverPending = false;
uint8_t modemRecoveryStage = 0;
uint32_t lastModemRecoveryMs = 0;
// Anti-flap hysteresis (see kModemRecoveryHoldMs): when the radio reports
// healthy, this records for how long it has done so. The ladder stage is only
// cleared after the hold elapses, so a marginal signal that flaps NO SERVICE
// <-> service does not re-run the disruptive step 1 on every flap.
uint32_t modemHealthySinceMs = 0;
uint32_t lastModemRecoveryEventMs = 0;
// Set (never reset here) by the AT read path / URC parser when it sees *ATREADY,
// which the A7672 emits only when the module boots. Acted on by pollModem() and
// cleared by initModem() on success. See modem_at.cpp:noteModemRebootDetected().
bool modemRebootUrcSeen = false;
uint32_t lastModemInitAttemptMs = 0;
// When pollModem() first saw the radio report NO SERVICE this episode. Gates the
// recovery ladder so a transient flap does not trigger a disruptive reset.
uint32_t noServiceSinceMs = 0;
// The modem reported +CIPEVENT: NETWORK CLOSED UNEXPECTEDLY: the network library
// died (out of service), so state.lteDataUp is stale. Cleared when the PDP is
// torn down / brought back up. See lte_mqtt_client.h:noteUrc().
bool ltePdpDown = false;
uint32_t ltePreemptSinceMs = 0;
uint32_t lastLteRetryDelayMs = kLteRetryIntervalMs;
uint32_t lastLteDataEventMs = 0;
uint8_t lteMqttConnectFails = 0;
uint32_t lastSilenceProbeMs = 0;
uint32_t lastLteHealthProbeMs = 0;
uint32_t lteNoServiceSinceMs = 0;
uint8_t lteMqttRebuildCycles = 0;
// Events produced while MQTT is down, drained in order once it is back.
DeferredEvent deferredEvents[kDeferredEventMax];
size_t deferredEventCount = 0;
// Which interface the lwIP default route should use. Auto follows the health
// flags (Ethernet > WiFi); the explicit values pin the route for a reachability
// probe, which is only meaningful if the packet leaves through the interface
// under test.
void setStatus(const String& line) {
  state.statusLine = line;
  Serial.println("[status] " + line);
}
// Human-readable reset reason, captured once at boot so the panel can tell a
// recovery-ladder ESP.restart() ("software") from a crash ("panic"/"wdt"). See
// BACKLOG §6.
const char* resetReasonName() {
  switch (esp_reset_reason()) {
    case ESP_RST_POWERON: return "power_on";
    case ESP_RST_EXT: return "external_pin";
    case ESP_RST_SW: return "software";
    case ESP_RST_PANIC: return "panic";
    case ESP_RST_INT_WDT: return "int_wdt";
    case ESP_RST_TASK_WDT: return "task_wdt";
    case ESP_RST_WDT: return "wdt";
    case ESP_RST_DEEPSLEEP: return "deep_sleep";
    case ESP_RST_BROWNOUT: return "brownout";
    case ESP_RST_SDIO: return "sdio";
    default: return "unknown";
  }
}
// --- OTA rollback guard -----------------------------------------------------
// Runs once per boot. See kOtaConfirm* constants for the policy.
bool otaConfirmPending = false;
uint32_t otaConfirmBootMs = 0;
bool otaConfirmedThisBoot = false;
void publishTestCallProgress(const String& message) {
  if (!reportTestCallProgress) {
    return;
  }
  setStatus(message);
  if (state.mqttConnected) {
#if COF_LTE_MQTT_NATIVE
    if (state.lteMqttTransport) {
      // Native CMQTT keepalives on the module; nothing to pump here.
    } else
#endif
    {
      // Keep the keepalive serviced so the broker does not drop us mid-call.
      if (mqttClient.loop()) {
        lastMqttOkMs = millis();
      } else {
        state.mqttConnected = false;
      }
    }
    publishDeviceEvent("test_call", "info", withFirmware(message));
  }
}
void publishTestCallResult(const String& result, bool ok, const String& commandId) {
  JsonDocument doc;
  doc["device_id"] = state.mqttDeviceId;
  doc["firmware"] = COF_FIRMWARE_VERSION;
  doc["type"] = "test_call";
  doc["severity"] = ok ? "info" : "warning";
  doc["message"] = withFirmware(result);
  if (commandId.length() > 0) {
    doc["command_id"] = commandId;
  }
  // Prefer the observed path from the call suffix: "Call done [volte LTE IMS=…]".
  // Codes: volte | csfb | gsm (see docs/voice/operators/claro-ar.md).
  {
    const int open = result.indexOf('[');
    if (open >= 0) {
      int end = result.indexOf(' ', open + 1);
      const int close = result.indexOf(']', open + 1);
      if (end < 0 || (close >= 0 && close < end)) {
        end = close;
      }
      if (end > open + 1) {
        String transport = result.substring(open + 1, end);
        transport.trim();
        if (transport.length() > 0) {
          doc["transport"] = transport;
        }
      }
    }
  }
  if (modemCallLog.length() > 0) {
    doc["modem_log"] = modemCallLog;
  }
  publishMqttJson("event", doc, false, 1);
}
LteMqttClient lteMqttClient;
void maintainLteFallback() {
  if (state.callInProgress || state.otaInProgress || state.audioSyncInProgress ||
      !modemUartOwnedByMqtt()) {
    return;
  }
  if (static_cast<int32_t>(millis()) < static_cast<int32_t>(kLteBootGraceMs)) {
    return;
  }

  const bool lanMqttOk = state.mqttConnected && !state.lteMqttTransport && lanConnected();
  if (lanMqttOk) {
    noLanSinceMs = 0;
    lastLteFail = false;
    lastLteAttemptMs = 0;
    if (state.lteDataUp || state.lteMqttTransport) {
      Serial.println("[lte] LAN MQTT ok, stopping PDP");
      noteLteSessionDrop("lan-mqtt");
      stopLtePdp();
      lastMqttReconnectMs = 0;
    }
    return;
  }

  // A LAN interface is only a reason to stay off LTE if it actually reaches the
  // broker. Previously a bare DHCP lease was enough, so a router with no uplink
  // kept lanConnected() true and LTE never engaged.
  const bool lanUsable = canUseLan();
  if (lanUsable) {
    noLanSinceMs = 0;
    if (!state.lteDataUp) {
      lastLteFail = false;
    }
    lastLteAttemptMs = 0;
    lastLteRetryDelayMs = kLteRetryIntervalMs;
    return;
  }

  if (noLanSinceMs == 0) {
    noLanSinceMs = millis();
    if (noLanSinceMs == 0) {
      noLanSinceMs = 1;
    }
  }
  const bool waitingWifi = state.wifiConfigured && !state.wifiConnected &&
                           wifiAuthFailCount < kWifiAuthFailLimit && !state.lteDataUp;
  if (waitingWifi && static_cast<int32_t>(millis() - noLanSinceMs) < static_cast<int32_t>(kWifiGraceBeforeLteMs)) {
    startWifiRadio();
    return;
  }
  ensureLtePdp();
}
bool readTestButton() {
  if (!state.pcfReady) {
    return false;
  }

  Wire.requestFrom(state.pcfAddress, static_cast<uint8_t>(1));
  if (Wire.available() != 1) {
    return false;
  }

  const uint8_t value = Wire.read();
  return (value & 0x01) == 0;
}
bool networkStatRegistered(int stat) {
  return stat == 1 || stat == 5 || stat == 9 || stat == 10;
}
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
void loop() {
  const uint32_t now = millis();
  feedWatchdog();
  serviceOtaRollbackGuard();
  handleSerialInput();

  if (now - lastSensorMs >= kSensorIntervalMs) {
    lastSensorMs = now;
    readSensors();
  }

  if (now - lastDisplayMs >= kDisplayIntervalMs) {
    lastDisplayMs = now;
    drawDisplay();
  }

  // Before the path polls: they all gate on cachedMqttIp, which is otherwise only
  // learned from a successful MQTT connect.
  serviceBrokerResolve();
  pollEthernetPath();
  pollWifiPath();
  serviceNetworkPaths();
  connectMqttIfNeeded();
  maintainWifiBackup();
  enforceMqttSilenceWatchdog();
  serviceLteMqttHealth();
  serviceModemUartDebug();

  if (state.mqttConnected && pendingNetworkStatusReport) {
    pendingNetworkStatusReport = false;
    publishDeviceStatus("online", true);
  }
  publishLteDataTrace();
  flushDeferredEvents();

  if (state.mqttConnected && pendingConfigReport) {
    publishConfigReported();
    pendingConfigReport = false;
  }

  if (state.mqttConnected && pendingCommandAck) {
    publishCommandAck();
    pendingCommandAck = false;
  }

  if (pendingOtaCommand && !state.callInProgress && !state.otaInProgress && !state.audioSyncInProgress) {
    pendingOtaCommand = false;
    setStatus("OTA command");
    checkManifest(true);
  }

  if (state.mqttConnected && pendingStatusReportCommand) {
    pendingStatusReportCommand = false;
    publishDeviceStatus("online", true);
  }

  // Gated off a live call so the probe's AT traffic cannot abort an active CSFB
  // call; it just stays pending until the call finishes.
  if (pendingModemProbeCommand && !state.callInProgress && !state.otaInProgress &&
      !state.audioSyncInProgress && modemUartOwnedByMqtt()) {
    const String probeCommandId = pendingModemProbeCommandId;
    pendingModemProbeCommand = false;
    pendingModemProbeCommandId = "";
    runModemProbe(probeCommandId);
  }

  if (pendingCmqttProbeCommand && !state.callInProgress && !state.otaInProgress &&
      !state.audioSyncInProgress && modemUartOwnedByMqtt()) {
    const String probeCommandId = pendingCmqttProbeCommandId;
    pendingCmqttProbeCommand = false;
    pendingCmqttProbeCommandId = "";
    runCmqttProbe(probeCommandId);
  }

  if (pendingTestSmsCommand && modemCsWorkAllowed()) {
    const String smsPhone = pendingTestSmsPhone;
    const String smsText = pendingTestSmsText;
    const String smsCommandId = pendingTestSmsCommandId;
    pendingTestSmsCommand = false;
    pendingTestSmsPhone = "";
    pendingTestSmsText = "";
    pendingTestSmsCommandId = "";
    appendModemLogForced("SMS run " + smsPhone);
    const String result = sendTestSms(smsPhone, smsText);
    appendModemLogForced("SMS result " + result);
    lteTraceLog = modemCallLog;
    pendingLteTraceMessage = "SMS " + result;
    pendingLteTraceOk = result.startsWith("SMS sent");
    pendingLteTracePublish = true;
    connectMqttIfNeeded();
    const bool ok = result.startsWith("SMS sent");
    // Transport code lives in the message suffix "SMS sent [smsoip|sgs|gsm]" and
    // is also published as payload.transport for the panel badge.
    String transport;
    const int open = result.indexOf('[');
    const int close = result.indexOf(']', open + 1);
    if (open >= 0 && close > open + 1) {
      transport = result.substring(open + 1, close);
      transport.trim();
    }
    publishDeviceEvent("test_sms", ok ? "info" : "warning", result, smsCommandId, transport);
  }

  if (pendingTestCallCommand && modemCsWorkAllowed()) {
    const String callPhone = pendingTestCallPhone;
    const String callAudioSha = pendingTestCallAudioSha;
    const String callAudioUrl = pendingTestCallAudioUrl;
    const String callCommandId = pendingTestCallCommandId;
    const bool callAdmin = pendingTestCallIsAdmin;
    pendingTestCallCommand = false;
    pendingTestCallPhone = "";
    pendingTestCallAudioSha = "";
    pendingTestCallAudioUrl = "";
    pendingTestCallCommandId = "";
    pendingTestCallIsAdmin = false;
    reportTestCallProgress = callAdmin;
    const String result = placeCallAndPlayAudio(callPhone, callAdmin, callAudioSha, callAudioUrl);
    reportTestCallProgress = false;
    connectMqttIfNeeded();
    if (callAdmin) {
      const bool ok = result.startsWith("Call done");
      publishTestCallResult(result, ok, callCommandId);
    }
  }

  // Use a fresh millis(): connectMqttIfNeeded() can spend seconds on CMQTT AT and
  // then set lastTelemetryPublishMs = millis(). Comparing that against the stale
  // `now` from the top of loop() underflows uint32_t and republishes telemetry
  // ~2 s later (identical twin rows after every LTE reconnect / atready).
  {
    const uint32_t telemetryNow = millis();
    if (state.mqttConnected &&
        telemetryNow - lastTelemetryPublishMs >= state.telemetryIntervalMs) {
      if (publishTelemetryNow()) {
        lastTelemetryPublishMs = millis();
      }
    }
  }

  if (state.mqttConnected && !state.callInProgress && !state.otaInProgress &&
      !state.lteMqttTransport && modemUartOwnedByMqtt() &&
      now - lastCellularStatusMs >= kCellularStatusIntervalMs) {
    lastCellularStatusMs = now;
    refreshCellularStatus();
    publishDeviceStatus("online", true);
  }

  const uint32_t modemEvery = lanConnected() ? kModemIntervalMs : kModemRetryNoLanMs;
  if (now - lastModemMs >= modemEvery && !state.callInProgress && !state.audioSyncInProgress &&
      !state.lteMqttTransport && modemUartOwnedByMqtt()) {
    lastModemMs = now;
    pollModem();
  }

  if (now - lastSmsPollMs >= kSmsPollIntervalMs && modemCsWorkAllowed() &&
      !state.lteMqttTransport &&
      !pendingTestSmsCommand && !pendingTestCallCommand) {
    lastSmsPollMs = now;
    pollIncomingSms();
  }

  if (state.pcfReady && !state.callInProgress && !state.otaInProgress && !state.audioSyncInProgress) {
    handleButton();
  }

  if (networkConnected() && !state.callInProgress && !state.otaInProgress && !state.audioSyncInProgress) {
    if (!didInitialManifestCheck && now > kManifestInitialDelayMs) {
      didInitialManifestCheck = true;
      lastManifestMs = now;
      checkManifest(false);
    } else if (didInitialManifestCheck && now - lastManifestMs >= kManifestIntervalMs) {
      lastManifestMs = now;
      checkManifest(false);
    }
  }

  delay(20);
}

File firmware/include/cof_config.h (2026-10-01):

#pragma once

// Self-sufficient on purpose: the ETH_* constants below are typed with
// eth_clock_mode_t / eth_phy_type_t from ETH.h, and this header is included
// before the module-specific includes, so it cannot rely on them.
#include <Arduino.h>
#include <ETH.h>

// Firmware version shown on OLED and used by OTA comparison.
// NOTE: must be strictly lower than ota/manifest.json for a device to update.
#define COF_FIRMWARE_VERSION "0.2.130"

// Same origin as the OTA bin (Flask serves both from OTA_DIR with no-store).
#define COF_MANIFEST_URL "https://app.callonfail.com.ar/ota/manifest.json"

// Safety switch: set to 1 only after configuring COF_PHONE_NUMBER.
#define COF_ENABLE_CALLS 0
#define COF_PHONE_NUMBER "+549XXXXXXXXXX"

// WT32-ETH01 / WT32-S1 pin assignment.
#define COF_PIN_I2C_SDA 32
#define COF_PIN_I2C_SCL 33
#define COF_PIN_ONEWIRE 14
#define COF_PIN_ZMPT_ADC 36
#define COF_PIN_MODEM_RX 5
#define COF_PIN_MODEM_TX 17

// I2C defaults.
#define COF_OLED_ADDRESS 0x3C
#define COF_SHT31_ADDRESS 0x44

// Modem filesystem target for the canned fallback audio, played only when the
// per-rule pre-recorded audio and the TTS download are both unavailable.
// The per-rule files live under C:/a_<sha>.amr and are managed separately.
#define COF_MODEM_AUDIO_PATH "C:/cof_fallback.wav"

// Claro Argentina packet data. Voice/SMS still need CS/LTE attach.
#define COF_MODEM_APN "internet.claro.com.ar"
#define COF_MODEM_APN_USER "clarogprs"
#define COF_MODEM_APN_PASS "clarogprs777"
#define COF_MODEM_SMSC "+5491115030500"

// Default MQTT endpoint (TLS). Override from Serial with:
// mqtt HOST PORT DEVICE_ID [USER PASSWORD]
// Device username should match device_uid for Mosquitto ACL.
#define COF_DEFAULT_MQTT_HOST "mqtt.callonfail.com.ar"
#define COF_DEFAULT_MQTT_PORT 1883
#define COF_DEFAULT_MQTT_DEVICE_ID "cof-test"
#define COF_DEFAULT_MQTT_USERNAME "cof-test"
// Overridden by the real credential over Serial and stored in Preferences.
// This repo is PUBLIC: never commit a real value here, not even temporarily.
#define COF_DEFAULT_MQTT_PASSWORD "change-me-device-mqtt"

// MQTT over LTE: use the modem's native AT+CMQTT* client instead of the
// hand-rolled CIPOPEN/CIPSEND/CIPRXGET socket emulation. Native handles the PDP
// activation, keepalive and inbound delivery (URC) itself. Keep as a switch so a
// regression on some module firmware can be reverted to the legacy socket path
// without touching the LAN (PubSubClient) path.
#define COF_LTE_MQTT_NATIVE 1

// ---------------------------------------------------------------------------
// Timing and behaviour constants.
//
// Moved here from main.cpp when it was split into modules: every module needs
// some of these, so they belong to the shared layer rather than to any one .cpp.
// Do not duplicate them back into a module.
//
// eth_*_t below come from ETH.h, so this header must be included after it.
// ---------------------------------------------------------------------------
constexpr uint8_t kEthPhyAddr = 1;
constexpr int kEthMdcPin = 23;
constexpr int kEthMdioPin = 18;
constexpr int kEthPowerPin = 16;
constexpr eth_clock_mode_t kEthClockMode = ETH_CLOCK_GPIO0_IN;
constexpr eth_phy_type_t kEthPhyType = ETH_PHY_LAN8720;
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

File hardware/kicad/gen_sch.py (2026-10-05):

#!/usr/bin/env python3
"""Generate CallOnFail v1 KiCad schematics (KiCad 10), rev 1.5.3.

Two hierarchical sheets:
  01-alimentacion  — 5V_PSU, XY-SJVA, gel, buck-boost, Q1, TPL5010@BUS, 74HCT123
  02-io            — WT32, FT232, A7672, PCF8575, campo, RS485, frente

Layout rules (KiCad docs + readable-schematic practice):
  - 50 mil / 1.27 mm grid for symbols, pins and wires
  - Flow left→right (inputs, processing, outputs); power source→load
  - Parts that work together sit together; whitespace between blocks
  - Wires inside a block; labels if a wire would cross another block
  - join() path budget MAX_JOIN_WIRE — beyond that always labels (no spaghetti)
  - IC↔nearby R/C/PU/PD: always wire (join_local), never labels
  - Never run a wire along a symbol pin column; T-junctions only
  - GND down, supplies up
  - Never route a wire across a symbol body (modules + passives + connectors)
  - No overlapping symbol bodies; whitespace between blocks
  - Leave an IC pin straight (then bend); do not turn on top of the pin number

Rev 1.5 vs 1.4: no HCT14/CD4541/ULN/discrete relays; 2N3904 + TPL5010 +
PCF8575 + PC817 + relay module + RS485 + FT232.
Rev 1.5.1: TPL5010 on power sheet; RELAY JD-VCC; ZMPT 10k/15k; J9/J10 +3V3.
Rev 1.5.2: no TLC555 — BTN holds SYS off; TPL RSTn → EN; file version 20260306.
Rev 1.5.3: no Q3; 5V_MODEM=5V_SYS; TPL@5V_BUS+NPN DONE; 74HCT123~2s→Q1;
  trig OR TPL/P12/BTN (active low); /CLR blank on plug; TPL ~10 min; EN=lab.
"""

from __future__ import annotations

import re
import uuid
from pathlib import Path

OUT = Path(__file__).resolve().parent
LIB = Path(r"C:\Program Files\KiCad\10.0\share\kicad\symbols")
KICAD_PRO_TEMPLATE = Path(r"C:\Program Files\KiCad\10.0\share\kicad\template\kicad.kicad_pro")

ROOT_UUID = "a1111111-1111-4111-8111-111111111111"
PWR_UUID = "a2222222-2222-4222-8222-222222222222"
IO_UUID = "a3333333-3333-4333-8333-333333333333"
PROJECT = "cof-v1"

EXTRACT = {
    "Device:R": ("Device.kicad_sym", "R"),
    "Device:C": ("Device.kicad_sym", "C"),
    "Device:C_Polarized": ("Device.kicad_sym", "C_Polarized"),
    "Device:D": ("Device.kicad_sym", "D"),
    "Device:LED": ("Device.kicad_sym", "LED"),
    "Device:Fuse": ("Device.kicad_sym", "Fuse"),
    "Device:Battery": ("Device.kicad_sym", "Battery"),
    "Device:Q_PMOS": ("Device.kicad_sym", "Q_PMOS"),
    "Device:Q_NPN": ("Device.kicad_sym", "Q_NPN"),
    "Switch:SW_Push": ("Switch.kicad_sym", "SW_Push"),
    "Connector_Generic:Conn_01x02": ("Connector_Generic.kicad_sym", "Conn_01x02"),
    "Connector_Generic:Conn_01x04": ("Connector_Generic.kicad_sym", "Conn_01x04"),
    "Connector_Generic:Conn_01x05": ("Connector_Generic.kicad_sym", "Conn_01x05"),
    "Connector_Generic:Conn_01x06": ("Connector_Generic.kicad_sym", "Conn_01x06"),
    "Connector_Generic:Conn_01x08": ("Connector_Generic.kicad_sym", "Conn_01x08"),
    "power:GND": ("power.kicad_sym", "GND"),
    "power:PWR_FLAG": ("power.kicad_sym", "PWR_FLAG"),
}


def g(n: int | float) -> float:
    """50 mil KiCad connection grid."""
    return round(float(n) * 1.27, 2)


ESCAPE = g(8)  # 10.16 mm past the pin, then the first bend
# Prefer labels over spaghetti: join() wires only if the path stays short.
MAX_JOIN_WIRE = g(48)  # ~61 mm manhattan/path budget


def uid() -> str:
    return str(uuid.uuid4())


def take_sexp(s: str, start: int) -> str:
    depth = 0
    i = start
    n = len(s)
    while i < n:
        c = s[i]
        if c == '"':
            i += 1
            while i < n:
                if s[i] == "\\":
                    i += 2
                    continue
                if s[i] == '"':
                    i += 1
                    break
                i += 1
            continue
        if c == "(":
            depth += 1
        elif c == ")":
            depth -= 1
            if depth == 0:
                return s[start : i + 1]
        i += 1
    raise ValueError("unterminated s-expr")


def extract_symbol(lib_file: str, name: str) -> str:
    lib_id = f"{lib_file.replace('.kicad_sym', '')}:{name}"
    if LIB.exists():
        text = (LIB / lib_file).read_text(encoding="utf-8")
        needle = f'(symbol "{name}"'
        idx = 0
        while True:
            j = text.find(needle, idx)
            if j < 0:
                break
            after = j + len(needle)
            if after < len(text) and text[after] in " \r\n\t":
                body = take_sexp(text, j)
                return body.replace(f'(symbol "{name}"', f'(symbol "{lib_id}"', 1)
            idx = j + 1
    for sch_name in ("01-alimentacion.kicad_sch", "02-io.kicad_sch"):
        path = OUT / sch_name
        if not path.exists():
            continue
        text = path.read_text(encoding="utf-8")
        needle = f'(symbol "{lib_id}"'
        j = text.find(needle)
        if j >= 0:
            return take_sexp(text, j)
    raise KeyError(f"{lib_id} not in KiCad libs or existing sheets")


def parse_pins(sym_text: str) -> dict[str, tuple[float, float, float]]:
    pins: dict[str, tuple[float, float, float]] = {}
    i = 0
    while True:
        j = sym_text.find("(pin ", i)
        if j < 0:
            break
        block = take_sexp(sym_text, j)
        at = re.search(r"\(at ([-\d.]+) ([-\d.]+) ([-\d.]+)\)", block)
        num = re.search(r'\(number "([^"]+)"', block)
        if at and num:
            pins[num.group(1)] = (
                float(at.group(1)),
                float(at.group(2)),
                float(at.group(3)),
            )
        i = j + 1
    return pins


def rot_xy(x: float, y: float, rot: int) -> tuple[float, float]:
    rot %= 360
    if rot == 0:
        return x, y
    if rot == 90:
        return -y, x
    if rot == 180:
        return -x, -y
    if rot == 270:
        return y, -x
    raise ValueError(rot)
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

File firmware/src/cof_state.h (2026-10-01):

#pragma once
// Umbrella header for all shared state. Include this and nothing else from
// the cof_* headers; the order below is load-bearing.
//
// Declarations only: the definitions (with initialisers) live in main.cpp, so
// exactly one translation unit owns each symbol. Do not add initialisers here
// -- that would create a tentative definition in every TU, which links under
// -fcommon but breaks the moment the toolchain flips to -fno-common.
//
// Verified before the split: no global's initialiser reads another global, so
// splitting them across translation units cannot introduce a static
// initialisation-order bug.

#include <Arduino.h>
#include <ArduinoJson.h>
#include <Preferences.h>
#include <PubSubClient.h>
#include <WiFi.h>
#include <WiFiClientSecure.h>
#include <IPAddress.h>
#include <map>
#include <DallasTemperature.h>
#include <OneWire.h>
#include <U8g2lib.h>
#include <Adafruit_SHT31.h>
#include <Client.h>
#include "cof_config.h"

// ---- types ----
enum LteIpStack : uint8_t { kLteStackUnknown = 0, kLteStackNetopen, kLteStackCnact };

enum class PathPreference : uint8_t { Auto, Ethernet, Wifi };

// Cooperative UART owner for the single modem serial line. MQTT (CMQTT), voice
// and SMS cannot share AT traffic; the main loop yields while owner != mqtt.
enum ModemUartOwner : uint8_t {
  kModemUartMqtt = 0,
  kModemUartVoice,
  kModemUartSms,
};

struct RuntimeState {
  bool ethernetStarted = false;
  bool ethernetConnected = false;
  bool wifiConfigured = false;
  bool wifiConnected = false;
  bool lteDataUp = false;
  bool lteMqttTransport = false;
  uint8_t ltePdpCid = 0;
  bool mqttConfigured = false;
  bool mqttConnected = false;
  ModemUartOwner modemUartOwner = kModemUartMqtt;
  bool oledReady = false;
  bool sht31Ready = false;
  bool ds18b20Ready = false;
  bool modemReady = false;
  bool simReady = false;
  bool networkRegistered = false;
  bool modemAudioPlaybackSupported = false;
  bool modemFileTransferSupported = false;
  int cregStat = -1;
  int ceregStat = -1;
  int cgregStat = -1;
  String operatorName = "";
  String smsc = "";
  String apn = COF_MODEM_APN;
  String modemModel = "";
  String radioInfo = "";
  String radioMode = "";
  int cnmp = -1;
  int imsVoice = -1;
  int imsReg = -1;
  bool forcedGsmForCall = false;
  bool skipGsmVoice = false;
  String imsi = "";
  String voiceIdentity = "";
  String predictedVoicePath = "unknown";
  String observedVoicePath = "";
  String radioAtDial = "";
  String radioAtConnect = "";
  bool callInProgress = false;
  bool otaInProgress = false;
  bool audioSyncInProgress = false;
  uint8_t pcfAddress = 0;
  bool pcfReady = false;
  float shtTemperature = NAN;
  float shtHumidity = NAN;
  float dsTemperature = NAN;
  int zmptRaw = 0;
  int signalQuality = -1;
  uint8_t oledAddress = COF_OLED_ADDRESS;
  String ipAddress = "-";
  String wifiSsid = "";
  String wifiIpAddress = "-";
  String lteIpAddress = "-";
  String mqttHost = COF_DEFAULT_MQTT_HOST;
  int mqttPort = COF_DEFAULT_MQTT_PORT;
  String mqttDeviceId = COF_DEFAULT_MQTT_DEVICE_ID;
  String mqttUsername = COF_DEFAULT_MQTT_USERNAME;
  String mqttPassword = COF_DEFAULT_MQTT_PASSWORD;
  int reportedConfigVersion = 0;
  String reportedConfigHash = "";
  uint32_t telemetryIntervalMs = kTelemetryPublishIntervalMs;
  bool callingEnabled = false;
  String statusLine = "Booting";
  // Reason the ESP32 last reset, captured in setup() via ESP.getResetReason().
  // Published with the first status so a reboot can be told apart from a crash
  // (see BACKLOG §6). "Software reset CPU" = ESP.restart() = recovery stage 5.
  String bootResetReason = "unknown";
  String modemAudioPath = COF_MODEM_AUDIO_PATH;
  // The canned asset the manifest keeps on the modem (C:/cof_test.wav). It is
  // only a fallback: a call tries to download the spoken TTS audio first, and
  // only when that download is impossible does it play this instead of not
  // dialing at all. See placeCallAndPlayAudio().
  String modemFallbackAudioPath = COF_MODEM_AUDIO_PATH;
  bool modemFallbackAudioReady = false;
  // Pre-recorded call audio, one file per distinct alarm text. Keyed by the
  // first 16 hex of the text sha; the JSON is persisted in Preferences. The
  // call looks up the rule's call_audio.text_sha256 here and plays the matching
  // modem file without any network access. See syncRuleAudio().
  std::map<String, String> ruleAudioPaths;
  String manifestFirmwareVersion = "";
  String manifestFirmwareUrl = "";
  String manifestFirmwareSha256 = "";
  String manifestAudioVersion = "";
  String manifestAudioUrl = "";
  String manifestPhoneNumber = COF_PHONE_NUMBER;
};

struct DeferredEvent {
  String type;
  String severity;
  String message;
  String commandId;
  String transport;
};

enum CallEndSource {
  kCallEndRemote,
  kCallEndAudioDone,
  kCallEndTimeout
};
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

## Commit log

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2026-09-03 Fix NVS config keys and expose MQTT event payloads in the UI.
    Shorten Preferences keys under the ESP32 15-char limit so desired config can persist, and show low-level desired/reported payloads on the device page.
    [cof_config.h, main.cpp]
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2026-09-03 fix: keep SIM SMSC and skip retained config replay after SMS
    Network timeout was likely our forced Claro SMSC. Also keep MQTT alive so a long SMS wait does not re-apply config v2.
    [cof_config.h, main.cpp]
2026-09-03 fix: report real outgoing call progress instead of ATD OK
    Wait for CLCC/VOICE CALL before claiming success so a silent failed dial is not logged as Call done.
    [cof_config.h, main.cpp]
2026-09-03 fix: do not dial in NO SERVICE and report CEER after voice fail
    [cof_config.h, main.cpp]
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2026-09-04 feat: infer voice path live from IMS, CREG and radio, reset on SIM change
    [cof_config.h, main.cpp]
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2026-09-04 fix: wait until CPAS, CREG and SMS stack are ready before call or SMS
    [cof_config.h, main.cpp]
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2026-09-04 fix: do not abort CSFB with AT polls, and stop showing predicted voice as proven
    Ignore NO CARRIER for 40s and listen only for URCs; CFUN bounce on retry. Web keeps the last test number and greens voice only after a connected call.
    [cof_config.h, main.cpp]
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2026-09-06 fix: require CLCC active before Call done so unanswered CSFB is not success
    Claro emits VOICE CALL BEGIN / MO CONNECTED while the far end is still ringing. Only +CLCC state 0 after alerting counts as answered.
    [cof_config.h, main.cpp]
2026-09-06 fix: classify CSFB calls by hangup cause, not false CLCC active
    Claro marks the call active during ringback. Play audio while it rings, but report Call done only after a real remote hangup; BUSY/CEER 17-21 is Call rejected and no pickup is Call no answer.
    [cof_config.h, main.cpp]
2026-09-06 fix: stop polling AT during calls so reject and hangup URCs are seen
    CLCC polls flushed BUSY, NO CARRIER and audio-stop. Listen only; hang up after playback; CEER 16 after audio is Call done, quick drop is Call rejected, timeout after ringing is Call no answer.
    [cof_config.h, main.cpp]
2026-09-06 fix: classify calls by who hung up and 3GPP CEER
    Stop using audio/ring duration. Unanswered phones do not DISCONNECT; remote cause 16 is answer or hangup after pickup.
    [cof_config.h, main.cpp]
2026-09-06 fix: keep reject and hangup URCs instead of flushing them
    CCMXPLAY was discarding BUSY/VOICE CALL:END, and A7672 END without spaces was ignored, so reject looked like no answer.
    [cof_config.h, main.cpp]
2026-09-06 fix: read hangup after stopping call audio, not after ATH
    CCMXPLAY can hide BUSY/END until stop. Delay play 8s, drain URCs, query CEER before hanging up, stamp firmware on every test_call event.
    [cof_config.h, main.cpp]
2026-09-06 fix: stop playing TTS on ring and show modem AT trace on the web
    Playing into ringback marked no-answer and reject as Playing audio. Capture the call AT log once at the end instead of guessing.
    [cof_config.h, main.cpp]
2026-09-06 fix: play after lead-in and hang up after trailing silence
    Claro CSFB only signals remote hangup. Play into the voice path, wait 4s then 2s after TTS, mark done on CLCC 6 / CEER 16 or audio end.
    [cof_config.h, main.cpp]
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2026-09-06 fix: keep ordered tenant contacts and harden alarm plus call queue
    Multiple emails and chats notify all; phones are stored in order but only the first is dialed yet. Firmware 0.2.40 snapshots MQTT commands and sends SMS before a queued call.
    [cof_config.h, main.cpp]
2026-09-06 feat: serialize modem SMS and calls in a per-device queue
    Multiple alarms no longer overwrite each other. One modem job runs at a time; the next starts after the device result or a timeout.
    [cof_config.h, main.cpp]
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2026-09-10 Lock v1 proto hardware: 5 V MOSFET OR, THT parts, 2 IN / 2 OUT, independent buzzer.
    PCF keeps NET and ALARM LEDs; buzzer is P3 via ULN so a rule can sound without closing field relays.
    [01-alimentacion.kicad_sch, 02-io.kicad_sch, cof-v1-bom.csv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]
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2026-09-13 Fail over to LTE when Ethernet looks up but MQTT is dead.
    WT32-ETH01 often keeps ETH_CONNECTED after the cable is pulled, so the device sat on a stale IP and never opened the modem PDP.
    [cof_config.h, main.cpp]
2026-09-13 Associate WiFi while Ethernet is up and fail over when the cable is yanked.
    0.2.46 only saved the SSID, so unplugging never had WiFi or LTE. Probe the MQTT path and show ETH/WiFi/LTE on the OLED.
    [cof_config.h, main.cpp]
2026-09-13 Clear ESP-stored WiFi on Olvidar and probe Ethernet without waiting for MQTT.
    Forget left the radio associated so the web kept the old IP, and unplugging never reached LTE because the cable check skipped when the broker dropped.
    [cof_config.h, main.cpp]
2026-09-13 Publish LTE PDP AT dumps and retry data when the modem is not registered.
    Without LAN the device sat on L wait with no MQTT, so the CNACT failure was invisible. Dump the trace like a test call once the broker is reachable again.
    [cof_config.h, main.cpp]
2026-09-13 Retry SIM detection after boot so SMS is not stuck on no SIM.
    [cof_config.h, main.cpp]
2026-09-21 Reorganize repo into firmware/, web/, ota/ and topic docs/
    Top-level now mirrors the four separate worlds of the project:
    - firmware/: the ESP32 code (src/, include/, platformio.ini, partitions.csv).
    PlatformIO resolves src_dir/include_dir relative to its own ini, so run
    `cd firmware && pio run`. Verified: builds clean (Flash 56.5%).
    - web/: static commercial site (was website/). Caddy still mounts it at
    /srv/website so no Caddyfile change was needed there.
    - ota/: the OTA artefact (was actual_version/) - manifest, firmware.bin,
    and audio. It is a build output, not source.
    - docs/: split into hardware/, device/, ops/, voice/, modem/.
    Path updates that had to move with the dirs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
    [partitions.csv]
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2026-09-21 Fix network path selection, publishing cadence and lossy events (fw 0.2.55)
    The device could sit with Ethernet, WiFi and LTE all apparently available and
    yet reach nothing, and it published telemetry every ~20 s instead of 60 s. Both
    came from the same class of bug: "the interface is up" was being used as a
    synonym for "the internet works".
    Publishing cadence
    - kMqttSilenceReconnectMs was 20 s while telemetry is published every 60 s, so
    the silence watchdog declared the link dead once per cycle, forced a
    disconnect/reconnect, and the reconnect path republishes status + telemetry.
    That is the observed ~20 s cadence, on every path, not just LTE.
    - Raise the threshold to 90 s (above the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
    [cof_config.h, main.cpp]
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2026-09-21 Recover a stuck modem radio and fix the Ethernet recovery probe (fw 0.2.56)
    Modem radio recovery
    - The modem can wedge in a state where it answers the AT channel but has no
    service at all: +CPIN: READY, AT+CIMI OK, yet +CSQ: 99,99,
    +CPSI: NO SERVICE,Online and AT+CNACT? -> ERROR. AT+CMEE=2 and AT+CGATT=1 do
    not recover it, and nothing else in the firmware did either. The only known
    cure was a physical power cycle, unavailable on a remote site, so the device
    fell back to the 6-minute MQTT-silence reboot, which does not touch module
    power.
    - pollModem() now watches radioReportsService() and escalates resetModemRadio()
    through detach/attach + COPS=0, CFUN=0/1 with a full scan, CFU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
    [cof_config.h, main.cpp]
2026-09-21 Report link health, not link presence, to the connectivity alarms
    - network_ethernet_ok / network_wifi_ok were reporting state.ethernetConnected
    and state.wifiConnected, i.e. link + DHCP presence. A cable plugged into a
    router with no uplink still raises PHY and gets a lease, so the "ethernet
    down" alarm stayed quiet in exactly the outage it exists to catch. Report the
    health flags instead, which are driven by real broker reachability.
    - The ethernet flag deliberately does not honour the holdoff: the holdoff is a
    routing-preference delay, so reporting off it would flap the alarm on every
    brief unplug.
    - pollWifiPath() skipped probing whenever Ethernet was connected. If Ethernet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
    [main.cpp]
2026-09-21 Trust CPSI's NO SERVICE over a stale CEREG registration
    radioReportsService() ignored CPSI's NO SERVICE whenever networkRegistered was
    true, but networkRegistered ORs CREG/CEREG/CGREG and CEREG keeps reporting
    "registered" on a stale context long after the radio lost service. Checking
    registration first therefore made the function claim a healthy radio in exactly
    the stuck state it was written to detect, contradicting its own comment. Check
    NO SERVICE first; it is the authoritative signal.
    [main.cpp]
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2026-09-21 Raise the MQTT keepalive from 10 s to 30 s (fw 0.2.57)
    Nothing polls connection state on a timer: connected() and loop() run on every
    loop() pass (~20 ms) and are free on Ethernet/WiFi. kMqttKeepAliveSeconds is the
    protocol heartbeat, not a state check, and 10 s was more aggressive than the
    15-60 s typical for MQTT. On LTE every PINGREQ is a modem round-trip, so 30 s
    takes it from 6/min to 2/min.
    Cost: a silently dead socket is noticed up to ~20 s later. Nothing depends on the
    keepalive being short, because kMqttSilenceReconnectMs (90 s) independently
    covers the "no successful publish" case.
    Also note in the docs that the keepalive bounds how long MQTT may go unattended,
    and that every lon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
    [cof_config.h, main.cpp]
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2026-09-21 firmware: cap the telemetry interval and fix the false watchdog comment
    The comment on kMqttSilenceReconnectMs claimed the largest accepted telemetry
    interval was 60 s, "enforced in loadSavedMqttConfig". It was not: loadSavedMqttConfig
    clamped to 3600 and applyDesiredConfig accepted anything up to 3600, while the
    comment in docs and the backend's alarm freshness threshold were built on the
    60 s claim.
    That mattered because the watchdog disconnects after 90 s without a successful
    publish and each reconnect republishes telemetry - so any stored interval above
    90 s re-created the ~20 s telemetry cadence the watchdog change was meant to fix.
    An operator could get there purely from the config fo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
    [main.cpp]
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2026-09-21 firmware: resolve the broker hostname without blocking, so boot-time probes work
    cachedMqttIp is only ever learned from a successful MQTT connect and lives in
    RAM, so after every reboot it is 0.0.0.0 until that first connect. Every
    reachability probe - probeMqttOverEthernet, probeMqttOverWifi, lanPathReachable -
    bails out on an unset IP, which left the whole boot window with connect-failure
    demotion as the only mechanism for detecting a dead LAN path.
    Closing that window with WiFi.hostByName() was not an option: it waits up to 16 s
    on the lwIP DNS semaphore, which is precisely why it was rejected for probe use in
    the first place.
    serviceBrokerResolve() drives the same lwIP call the Arduino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
    [cof_config.h, main.cpp]
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2026-09-21 firmware: bump version to 0.2.60
    Ships the module split plus the OTA integrity/gate fixes, then the
    extra verification of static initialisation order across the new
    translation units (the one dependency, ds18b20 <- oneWire, still runs in
    the same relative order).
    [cof_config.h]
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2026-09-21 docs: never commit credentials, and drop the leaked admin password
    The repo is public, so the admin panel password must not be written into
    BACKLOG.md. Removed it and replaced the on-disk secret guidance with a rule:
    ask for credentials in chat or have the user run the step.
    Also fixes cof_config.h, which claimed 'private repo only' while the repo is
    public, and widens .gitignore to cover .env.*, *.pem, *.key and *.p12.
    [cof_config.h]
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2026-09-23 lte: teardown exclusivo por stack, y documentar que el MQTT por LTE nunca conecto
    El 2026-09-22, con el cable desconectado, el OLED mostro la IP de LTE pero
    `MQTT --` y la web perdio el equipo. El evento `lte_data` de esa noche muestra
    que el ruteo LTE funciona (`+CIPOPEN: 0,0` = TCP abierto al broker, seis veces)
    y que el fallo esta en el handshake MQTT sobre el socket AT: el TCP se abre y
    nunca llega el CONNACK. No es APN, DNS ni el IP cacheado.
    `stopLtePdp()` mandaba `AT+CNACT=<ltePdpCid>,0` con el PDP en NETOPEN, donde
    `ltePdpCid` vale 1 pero el contexto CNACT es siempre 0. El modulo contestaba
    ERROR, visible en el trace. Los dos stacks son alternativas (detectLteIpStack
    elige uno), nun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
    [cof_config.h, lte_pdp.cpp]
2026-09-23 lte: capturar el handshake MQTT sobre LTE para poder diagnosticarlo
    El 2026-09-22 el MQTT por LTE no conecto y el trace no pudo explicar por que:
    muestra `+CIPOPEN: 0,0` (TCP abierto al broker) y ningun CONNACK, pero nada del
    envio. Dos huecos lo escondian:
    - `appendModemLog()` solo se llama desde `sendAT()`, y `LteMqttClient::write()`
    escribe el `AT+CIPSEND` directo al serial. Todo el envio MQTT queda fuera del
    log: por eso no hay un solo `CIPSEND`, no porque no se haya enviado.
    - `modemCallLog` es un ring que conserva solo la cola, y publica los ultimos 900
    bytes. En un loop de reintentos identicos el primer intento -el unico que
    importa- se descarta siempre.
    Ahora el cliente cap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
    [cof_config.h, mqtt_io.cpp]
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2026-09-23 Hacer visible y aplicar el tope de 40 audios de llamada
    El equipo guarda 40 audios distintos (kRuleAudioMax). Pasarse era
    completamente silencioso, por tres razones apiladas: el continue que salteaba un
    asset no tocaba ningun contador; el evento call_audio solo se publicaba si
    installed/pruned/failed eran > 0; y el backend no conocia el tope. Una config con
    45 reglas y 40 ya en el modem no publicaba ningun evento, la pagina del equipo no
    mostraba nada, y esas 5 reglas quedaban mudas. Cual quedaba sin voz dependia del
    orden de iteracion del std::map.
    Firmware (0.2.68):
    - El salteo incrementa `skipped`, se reporta como "skipped (cap)" en el evento
    call_audio, y ese evento pasa a warning (an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
    [cof_config.h, ota_config.cpp]
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2026-09-23 lte: re-resolver el broker cuando el connect falla, en vez de confiar en la cache
    cachedMqttIp se aprende del connect por LAN y, mientras MQTT viaja por
    LTE, no habia ninguna via que la actualizara ni la invalidara: el
    connect solo cachea con !lteMqttTransport y el resolver solo adopta un
    repoint con MQTT caido. Las dos vias cerradas.
    El dano era mayor de lo que parecia: cachedMqttIp no lo usan solo los
    probes de LAN. resolveLteMqttPeer() la preferia POR ENCIMA del DNS del
    modulo, asi que con una IP vieja el connect de LTE tambien fallaba. El
    sintoma no era 'LTE anda pero no vuelvo a la LAN' sino 'se cae todo', y
    solo sanaba por el reboot de los 6 minutos.
    El disparador es angosto (LAN con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
    [cof_config.h, cof_state.h, lte_pdp.cpp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]
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2026-09-25 fix: detectar reboot del modem (*ATREADY/eco) y no filtrar credenciales MQTT (0.2.74)
    [cof_config.h, modem_at.cpp, mqtt_io.cpp]
2026-09-25 feat: instrumentar reset reason y evento por stage de la escalera de radio (§6)
    [cof_state.h, main.cpp, mqtt_io.cpp]
2026-09-25 fix: histeresis anti-flap en la escalera de radio y dedup de eventos (0.2.75)
    [cof_config.h, main.cpp, mqtt_io.cpp]
2026-09-25 fix: *ATREADY one-shot, no reset mid-init (wedged 'L no AT' + 'Wait SIM', 0.2.76)
    [cof_config.h, cof_state.h, main.cpp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]
2026-09-25 fix: bound modem UART reads, rebuild PDP after voice call, throttle initModem (0.2.77)
    [cof_config.h, cof_state.h, main.cpp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]
2026-09-26 lte: stop self-inflicted radio flaps and PDP rebuilds
    - pollModem: require sustained NO SERVICE (kModemNoServiceGraceMs=45s)
    before starting the recovery ladder; a single CPSI 'NO SERVICE' read
    (mid-reselection or right after our own teardown/CSFB bounce) no longer
    detaches the modem. Fixes the 8x 'Radio NO SERVICE, recovery started'
    feedback loop seen 2026-09-25 on good signal.
    - resetModemRadio: stage 1 is now a gentle operator reselect (COPS=0),
    no CGATT=0 detach; PS re-attach and radio cycle move to stages 2/3.
    - noteUrc: distinguish +CIPEVENT NETWORK CLOSED (PDP dead -> rebuild)
    from +IPCLOSE/+CASTATE (socket close -> keep PDP, just reopen socket).
    A broker close was trigg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
    [cof_config.h, cof_state.h, lte_pdp.cpp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]
2026-09-26 lte: fix native CMQTT result parsing + PUB arg order (0.2.81)
    cmqttResult() mis-parsed comma-less results like +CMQTTSTART: 0 as -1, so a successful START was treated as failure and the service was left running on the modem (OTA only reboots the ESP32). Every retry then hit 'already started -> ERROR'. Also: CMQTTPUB args were <qos>,<retained>,60 instead of <qos>,<pub_timeout>,<retained>; and CMQTTSTART activates its own PDP (A76XX ch.18) so NETOPEN-first was reverted.
    [cof_config.h, lte_mqtt_native.cpp, lte_pdp.cpp]
2026-09-26 lte: query LTE IP after native connect + harden cmqttTearDown (0.2.82)
    Native CMQTT never runs NETOPEN, so lteIpAddress stayed '-' and the OLED showed 'L --'. Read the real address (queryLteIp) after connect so OLED/status/telemetry report it. Also make cmqttTearDown issue DISC unconditionally: after a publish failure or route bounce our brokerUp flag is false but the modem still holds the connection, so REL/STOP answered 'client is busy' ERROR. Documented the 0.2.81 double-CONNECT observation.
    [cof_config.h, lte_mqtt_native.cpp, mqtt_io.cpp]
2026-09-26 lte: never hang on LTE-only - radio health probe + connect-fail escalation (0.2.83)
    Two escape hatches for a silent radio death while MQTT rides native CMQTT (where pollModem/refreshCellularStatus are gated off): (1) serviceLteMqttHealth() does one AT+CSQ per 30s while connected, and on sustained +CSQ 99,99 tears the PDP down so the recovery ladder runs; (2) connectMqttNativeIfNeeded() now refreshes radio status after a 3-fail PDP rebuild and forces a radio cycle (resetModemRadio 3) when the radio still claims registered but data won't connect.
    [cof_config.h, cof_state.h, lte_mqtt_native.cpp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]
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2026-09-26 sms: free the modem before sending over LTE (0.2.85)
    When MQTT rides LTE (native CMQTT), AT+CMGS and the broker session share the
    single A7672 UART. transmitSms() tried to coexist and only released the socket
    on the retry, so the 60 s SMS read blocked past the 30 s broker keepalive and
    dropped the connection mid-send; the result event was lost and the backend
    timed the test_sms command out. Release the MQTT session before the SMS dialog,
    send on a quiet modem, and let the caller reconnect (publishDeviceEvent defers
    the result until MQTT is back).
    Also documents the SMS-on-LTE path in BACKLOG.
    [cof_config.h, sms_voice.cpp]
2026-09-26 lte: fix inbound commands over native CMQTT (0.2.86)
    Firmware 0.2.85 proved the SMS path: test_sms works over Ethernet but the
    command never reaches the device over LTE (no command_ack). The bug is inbound
    reception over native CMQTT, which never worked.
    Three defects on the RX path:
    - cmqttSubscribe() sent only the length form and ignored the +CMQTTSUB result,
    so a rejected SUB left the device publishing telemetry but deaf to commands.
    It now verifies +CMQTTSUB:<n>,0 and falls back to the parameter form.
    - readModemUntil() and flushModemInput() read the shared UART and dropped any
    byte that was not their token, losing +CMQTTRX* bytes for good (the broker had
    already acked the PUBLI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
    [cof_config.h, lte_mqtt_native.cpp, modem_at.cpp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]
2026-09-26 lte: do not subscribe while a retained message is still arriving (0.2.87)
    0.2.86 field log: the length-form SUB works, the parameter form returns ERROR,
    and the second SUB was issued while config/desired (1994 bytes) was still
    streaming. The modem answered +CMQTTSUB: 0,14 (client is busy), the JSON arrived
    truncated (config v0 rejected: invalid JSON), and CMQTTSTOP during *ATREADY
    rebooted the module so every following CMQTTSTART returned code 1.
    Wait for +CMQTTSUB: 0,0 and drain the retained burst before the next AT command.
    Subscribe to command first, then config. Do not send the parameter form when the
    length form is accepted. On CMQTTSTART code 1, wait for PB DONE instead of STOP.
    Skip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
    [cof_config.h, lte_mqtt_native.cpp, mqtt_io.cpp]
2026-09-26 lte: release the leftover CMQTT client before restarting it (0.2.88)
    0.2.87 never connected. The radio was online (CREG 1, CPSI LTE Online, CSQ 30);
    every attempt was AT+CMQTTSTART ERROR then AT+CMQTTSTOP ERROR. A bare START
    ERROR means the service is still running: OTA rebooted the ESP32 and left the
    0.2.86 client on the modem, and our flags start false so tearDown sent nothing.
    STOP alone answers ERROR while that client is still acquired, so START stayed
    ERROR. On that bare ERROR, DISC then REL then STOP, and only then START.
    [cof_config.h, lte_mqtt_native.cpp]
2026-09-26 lte: retry the broker socket instead of tearing CMQTT down (0.2.89)
    0.2.88 brought the service up (CMQTTSTART 0, ACCQ and will OK) and then
    +CMQTTCONNECT: 0,3, which the A76XX manual defines as sock connect fail. The
    broker answers TCP 1883 from outside. The firmware treated that as a dead
    service, issued STOP, and dialed the hostname again with the same result.
    Wait for a PDP address before CONNECT. Dial the IP Ethernet already reached
    when it is cached. On code 3, retry CONNECT on the same client, then resolve
    with CDNSGIP and dial that address.
    [cof_config.h, lte_mqtt_native.cpp]
2026-09-26 lte: restore the native MQTT path that connected (0.2.90)
    0.2.84 and 0.2.85 published LTE MQTT OK. 0.2.86 through 0.2.89 changed that
    path while chasing inbound SMS: a second subscribe during the retained config,
    a START/STOP loop, a sock-connect retry, and finally the 0.2.83 radio ladder
    issuing AT+CFUN=0 against a registered LTE radio (phone failure, *ATREADY,
    NO SERVICE). Put lte_mqtt_native, mqtt_io and modem_at back to 0.2.85. SMS
    over LTE is still open.
    [cof_config.h, lte_mqtt_native.cpp, modem_at.cpp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]
2026-09-26 lte: leave subscribe when the modem reports the result, not after a fixed pause (0.2.93)
    [cof_config.h, lte_mqtt_native.cpp]
2026-09-26 lte: stop CMQTT when the modem reboots and re-init before dialing again (0.2.94)
    [cof_config.h, lte_mqtt_native.cpp, modem_at.cpp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]
2026-09-26 lte: see a modem reboot even when the URC is behind a null byte (0.2.95)
    [cof_config.h, lte_mqtt_native.cpp, modem_at.cpp]
2026-09-26 lte: keep the CMQTT client across a broker drop so LTE does not redial every minute (0.2.96)
    [cof_config.h, lte_mqtt_native.cpp, lte_pdp.cpp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]
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2026-09-27 Release firmware 0.2.99: fix twin telemetry after LTE reconnect and skip AT+IPADDR on native CMQTT.
    [cof_config.h, lte_pdp.cpp, main.cpp]
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2026-09-28 Release firmware 0.2.103: UART debug append-only, flush intact over MQTT
    Seal live AT text into outbound chunks instead of wiping/replacing the log on reconnect so post-ATREADY dumps keep the pre-crash trail.
    [cof_config.h, lte_pdp.cpp, modem_at.cpp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]
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2026-09-29 Release firmware 0.2.108: PUB soft-fail cooldown only (no CONNECT), stop forcing UART debug on OTA.
    [cof_config.h, cof_state.h, lte_mqtt_native.cpp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]
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
